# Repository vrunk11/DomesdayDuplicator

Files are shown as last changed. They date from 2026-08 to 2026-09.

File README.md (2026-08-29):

# Domesday Duplicator (DdD)

The Domesday Duplicator is a LaserDisc capture focused, USB 3.0 based DAQ capable of 40
million samples per second acquisition of analogue RF data at 10-bits resolution.

Please see the [Project Documentation](https://domesday86.github.io/DomesdayDuplicator/) for
details of the project and for access to the project documentation. For contributing
guidelines, see [CONTRIBUTING.md](CONTRIBUTING.md).

Domesday Duplicator Overview

## The capture application

Capture is via an easy to use GUI capture application, with real-time signal analysis —
waveform, spectrum analyser and spectrogram, amplitude history and live capture statistics —
so you can see the RF while it is being sampled rather than after the fact.

The capture application, showing the spectrogram view

The application also drives a Pioneer LaserDisc player over serial, runs whole-disc automatic
captures, and updates the Duplicator's own firmware and gateware over USB. The
[Capture Application documentation](https://domesday86.github.io/DomesdayDuplicator/capture-gui/)
covers every panel.

## Installing — no compilation required

**There is absolutely no need to compile anything.** All end-user installs must be performed
using the provided binary packages and firmware images. Building from source is a development
activity only, and nothing you need as a user requires it.

### The capture application

Download from the [releases page](https://github.com/Domesday86/DomesdayDuplicator/releases)
and follow the installation page for your platform:

| Platform | Package | Installation |
| --- | --- | --- |
| Linux | `DomesdayDuplicator-<version>.flatpak` | [Linux (Flatpak)](https://domesday86.github.io/DomesdayDuplicator/capture-gui/install-flatpak/) |
| macOS (Apple Silicon) | `DomesdayDuplicator-<version>-macos-arm64.dmg` | [macOS (DMG)](https://domesday86.github.io/DomesdayDuplicator/capture-gui/install-dmg/) |
| Windows 11 | `DomesdayDuplicator-<version>-windows-x64.msi` | [Windows (MSI)](https://domesday86.github.io/DomesdayDuplicator/capture-gui/install-msi/) |

Every release also carries `SHA256SUMS` and a `PROVENANCE.txt` recording the commit each
asset was built from. Verify your download against `SHA256SUMS`.

### Firmware and gateware

You do not build these either. Firmware releases publish a single signed update bundle,
`domesday-duplicator-update-<version>.dddfw`, and the capture application installs it for you:
**Tools → Firmware → Update firmware…**. The application verifies the bundle's signature and
every payload digest before it writes anything, and reports the version it reads back off the
live device afterwards. See
[Updating your Domesday Duplicator](https://domesday86.github.io/DomesdayDuplicator/capture-gui/updating-your-domesday-duplicator/).

A board that has never been programmed is handled the same way, with no jumper and no shell —
see [Bringing up a new or legacy board](https://domesday86.github.io/DomesdayDuplicator/capture-gui/bringing-up-a-board/).
Firmware releases also publish the raw images (`firmware.img`, the provisioning `.jic` and the
factory `.svf`) for bench recovery, but the bundle is the supported route.

Every released artefact is built by CI from the tagged commit; nothing is built on a
maintainer's machine or attached by hand
([release pipeline](https://domesday86.github.io/DomesdayDuplicator/development/release-pipeline/)).

## Cloning the repository

Everything is in this one repository. There are no git submodules, so a plain clone gives
you the complete project:

```
git clone https://github.com/Domesday86/DomesdayDuplicator.git
```

### Repository layout

| Directory | Contents |
| --- | --- |
| [hardware/](hardware/) | KiCad design for the custom DdD board, plus hardware documentation |
| [fpga/](fpga/) | Verilog gateware for the Terasic DE0-NANO (Cyclone IV) |
| [fx3/firmware/](fx3/firmware/) | Cypress FX3 USB 3.0 controller firmware |
| [fx3/programmer/](fx3/programmer/) | Host-side tool for programming the FX3 |
| [fx3/mkimage/](fx3/mkimage/) | `fx3-mkimage`, the project's own ELF-to-boot-image tool |
| [fx3/sdk/](fx3/sdk/) | Vendored Cypress FX3 SDK the firmware builds against |
| [ddd-gui/](ddd-gui/) | Qt 6 capture application, and the Flatpak/DMG/MSI packaging under `ddd-gui/packaging/` |
| [docs/](docs/) | Source of the project documentation website |
| [docs-vendor/](docs-vendor/) | Transcribed vendor service documentation for supported players |
| [nix/](nix/) | The single flake's shared helpers, default dev shell, NixOS module and whole-tree checks |
| [tools/](tools/) | Repository-wide scripts, run both by hand and by the checks |

## Developing the project

**Do NOT install from source unless you intend to develop the software** — see
[Installing](#installing--no-compilation-required) above for user installations.

### Nix on Linux is the only supported environment

**The only supported development and build environment is Nix on Linux.** There is exactly one
`flake.nix`, at the repository root, and exactly one `flake.lock`; every toolchain the project
needs is pinned by it, and CI builds through the same flake, so a build that fails under Nix
is a real failure rather than an environment quirk.

**Pull requests that introduce another development or build environment will not be accepted.**
That includes alternative build systems, per-distribution dependency lists, and packaging
intended to make a component build without Nix. If you develop on macOS or Windows, use a
Linux virtual machine — that is the supported route, and it is the only one.

### Building

Run any of these from anywhere in the working tree; Nix walks up to find the flake at the
root, so `.#ddd-gui` resolves identically from `ddd-gui/` and from the repository root.

| Component | Build | Development shell |
| --- | --- | --- |
| Capture application | `nix build .#ddd-gui` | `nix develop .#ddd-gui` |
| FX3 firmware | `nix build .#fx3-firmware` | `nix develop .#fx3` |
| FX3 programmer | `nix build .#fx3-programmer` | `nix develop .#fx3` |
| FX3 boot-image tool | `nix build .#fx3-mkimage` | `nix develop .#fx3` |
| FPGA gateware | `nix build .#bitstream` | `nix develop .#fpga` · `nix develop .#fpga-quartus` |
| Documentation site | `nix build .#docs-site` | `nix develop .#docs` |
| PCB | — | `nix develop .#hardware` |

```
nix develop                          # every component's tools in one shell
nix flake check                      # build everything and run the whole T1–T4 test suite
```

The capture application installs three binaries: `ddd-gui`, plus `ddd-update` and `ddd-jtag`,
which drive the same engine from a shell.

Components deliberately carry no flake of their own: an earlier layout gave each one a thin
flake for the `cd ddd-gui && nix develop` shorthand, and every one of those resolved
`nixos-unstable` into a lock file of its own — so entering the tree through a component quietly
got a different nixpkgs from the root pin. The reasoning is in the header comment of
[flake.nix](flake.nix).

Two caveats on the FPGA row. Quartus Prime Lite is unfree, `x86_64-linux` only and cannot be
served from a binary cache, so `nix build .#bitstream` means a multi-gigabyte first download
and is excluded from `nix flake check` — the per-commit tier must never require an unfree
download of anyone. It *is* built by CI, in a workflow of its own that runs on gateware
changes and from release tags, so every released bitstream is CI-built from the tagged commit.
`nix develop .#fpga` — without `-quartus` — gives the free tools instead: Verilog lint,
simulation and a language server, with no Quartus at all, and that covers most gateware work.

Build directories are `build/` under each component and are gitignored. Never build in-tree:
in the gateware's project directories in particular, Quartus rewrites the tracked `.qsf` on
every compile.

On NixOS, device permissions come from the flake's module — set
`hardware.domesdayDuplicator.enable = true;`, which covers the Duplicator, the FX3 and the
on-board USB-Blaster together. Elsewhere, see
[Linux device access](https://domesday86.github.io/DomesdayDuplicator/development/hardware-programming/linux-device-access/).

[AGENTS.md](AGENTS.md) records the project conventions and [TESTING.md](TESTING.md) the test
tiers, including the hardware-in-the-loop capture-integrity procedure that is the most
important test in the project.

## The Decode Family

The samples the DdD captures can be used with the whole family of decoders that make the FM RF
archival workflow ready to use today.

The original design was for the wide bandwidth of LaserDisc RF — making it suitable for all of
the more bandwidth restricted mediums too (that have a single stream of RF).

[Please see the documentation for more details](https://domesday86.github.io/DomesdayDuplicator/general/overview/)

## 3D Printed Case

The Domesday Duplicator also has [3D models](https://github.com/Domesday86/DomesdayDuplicator-Case)
and ready to use STL files for producing 3D printed cases, to protect from dust or line with
copper tape for affordable EMI shielding for example.



## Authors

Domesday Duplicator is designed and maintained by [Simon Inns](https://github.com/simoninns).

## Licences

- [Software Licence — GPLv3](LICENSE)
- [Hardware Licence — Creative Commons BY-SA 4.0](https://creativecommons.org/licenses/by-sa/4.0/)
  (full text in [hardware/pcb/LICENSE.txt](hardware/pcb/LICENSE.txt))

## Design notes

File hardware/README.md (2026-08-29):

# Domesday Duplicator Hardware

Design files for the custom Domesday Duplicator PCB — the analogue front end, ADC and
interconnect that sit between the RF source and the DE0-NANO/FX3 boards.

## Contents

| Path | Contents |
| --- | --- |
| [pcb/](pcb/) | KiCad project: schematics, PCB layout, symbol and footprint libraries |
| [pcb/fab/](pcb/fab/) | Fabrication outputs, one frozen directory per board revision |
| [pcb/tools/](pcb/tools/) | Plotting and Gerber comparison scripts |
| [doc/](doc/) | Hardware documentation, including the gain and filter calculations |

The project is on the current KiCad format (10). Board revisions are recorded in
[pcb/CHANGELOG.md](pcb/CHANGELOG.md), and [pcb/MIGRATION.md](pcb/MIGRATION.md) documents the
conversion from the original KiCad 4 files, how it was verified, and what is still
outstanding.

Schematic PDFs and the BOM are not kept in the repository. They are build output, plotted
per revision into `pcb/fab/rev<REV>/` by the script below, and can be regenerated from the
project at any time.

## Design

The Domesday Duplicator hardware is based on:

- Terasic DE0-NANO FPGA development board (see [fpga/](../fpga/))
- Cypress FX3 USB 3.0 controller (see [fx3/](../fx3/))
- High-speed ADC for RF signal capture
- Custom analogue front-end circuitry

## Manufacturing

Each fabricated board revision has its own directory under `pcb/fab/`, holding the Gerbers
and drill file exactly as sent out, the schematic PDF and BOM they were built from, a
`MANIFEST.md` recording provenance, and a `SHA256SUMS`. These are a historical record, not
build output: they are written once and never regenerated, because they are the reference
for what the working board actually is.

`pcb/fab/rev1.0/` is the proven production board, plotted with KiCad 4.0.7 in 2018. A
modern KiCad cannot reproduce it byte for byte — it encodes zone fills differently — which
is why it is preserved rather than rebuilt.

To plot a new revision:

```sh
nix develop .#hardware
hardware/pcb/tools/plot-fab.sh 2.0
```

The script refuses to write into a revision directory that already exists. To compare a
fresh plot against an existing one, plot with `--scratch` and use
`pcb/tools/gerber-compare.py`, which compares geometry rather than text and so ignores the
aperture renumbering and object reordering that make a plain diff useless.

## Licence

The hardware design is licensed under **Creative Commons Attribution-ShareAlike 4.0
International**. The full text is in [pcb/LICENSE.txt](pcb/LICENSE.txt).

This is different from the software in this repository, which is GPLv3 — see the root
[LICENSE](../LICENSE).

## Documentation

For detailed documentation, please see the
[main project documentation](https://domesday86.github.io/DomesdayDuplicator).

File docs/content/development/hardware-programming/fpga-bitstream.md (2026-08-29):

# FPGA bitstream

How to build the Domesday Duplicator's gateware and get it onto the DE0-NANO, with a check to
confirm each step actually worked.



The gateware runs on a **Terasic DE0-NANO** carrying an Intel (Altera) **Cyclone IV
EP4CE22F17C6**. It generates the ADC sampling clock, buffers samples across the clock-domain
boundary, and feeds them to the FX3 over the GPIF II bus.

The board has an **onboard USB-Blaster**, so no separate programming pod is needed — the
DE0-NANO's mini-USB connector is both its power supply and its programming interface.

The DE0-NANO's mini-USB connector, in an assembled unit

!!! warning "In an assembled Duplicator, it is not the only power supply"

    That description is of the board on its own. Bolted to a Duplicator PCB with the FX3 kit
    above it, the assembly is powered through **either** USB connector, and either one alone
    keeps the whole thing alive.

    Two consequences, and the second is a trap. The board is lit whatever the mini-USB is
    doing, so "the lights are on" says nothing at all about whether the USB-Blaster is
    connected — a charge-only cable looks identical to a working one. And **a power cycle
    means unplugging both cables**: pull only one and nothing reboots, while the board stays
    lit and looks perfectly normal.

!!! tip "The application can do this for you"

    Writing the EPCS no longer needs Quartus: `ddd-gui` plays a CI-built SVF through the same
    onboard USB-Blaster — **Tools ▸ Firmware ▸ Bring up a new or legacy board…**.
    See [Bringing up a new or legacy board](../../capture-gui/bringing-up-a-board.md), and
    [USB-Blaster and SVF programming](../usb-blaster-and-svf.md) for how it works.

    This page remains the reference for building the bitstream and for programming it by
    hand.

There are two ways to program it, and you will usually want both:

| | Writes to | Survives a power cycle | Use for |
| --- | --- | --- | --- |
| **FPGA configuration SRAM** (`.sof`) | Volatile memory in the FPGA | **No** | Testing a bitstream before committing to it |
| **EPCS64 serial configuration device** (`.jic`) | The DE0-NANO's onboard flash | **Yes** | Normal use |

Start with the `.sof`. It cannot leave the board in a bad state — a power cycle restores
whatever the flash holds — so it is the safe way to find out whether a bitstream works before
making it permanent. This mirrors the RAM-then-EEPROM order on the
[FX3 firmware](fx3-firmware.md) page, and for the same reason.

## Before you start

1. **Set up device access** — [Linux device access](linux-device-access.md). Without it,
   Quartus reports `Unable to lock chain - Insufficient port permissions` and cannot program
   anything.
2. **Get Quartus Prime Lite.** It is free and needs no licence file, but it is a
   multi-gigabyte download and is `x86_64` Linux or Windows only. The project builds against
   **version 25.1**.

!!! tip "You may not need to build anything"

    Prebuilt `.sof` and `.jic` files are attached to
    [releases](https://github.com/Domesday86/DomesdayDuplicator/releases), along with a
    `bitstream-provenance.txt` recording the commit and Quartus version they came from. If you
    only want to program a board, skip to [step 2](#2-program-the-board).

## 1. Build the bitstream

### With Nix

From anywhere in a checkout, on `x86_64-linux`:

```bash
nix build .#bitstream
ls result/
```

```
application/  factory/  provisioning/  reports/  bitstream-provenance.txt
```

The gateware is **two** images that live in one flash: the capture gateware in
`application/`, and a small resident boot loader in `factory/` that a unit falls back to if
a gateware update is ever interrupted. `provisioning/` holds the one `.jic` that carries
both, and that is the file a board is programmed with. The model is described on the
[EPCS layout and boot flow](../epcs-layout-and-boot-flow.md) page.

There is deliberately **no `.jic` of the capture gateware alone**: programming one would
write it over the factory image, leaving a unit with nothing to fall back to.

Quartus comes from the flake, so nothing needs installing first. **The first build is slow**:
Quartus is not redistributable, so it can never come from a binary cache and must be fetched
from Altera. The build is restricted to the Cyclone IV device family, which removes five of
the six component downloads.

### With Quartus installed by hand

Put Quartus' `bin` directory on `PATH`, then:

```bash
./fpga/build-local.sh
```

That copies the sources to `fpga/build/`, compiles both images, converts them into one
provisioning `.jic` — and into the `.svf` carrying the same content as JTAG vectors — and
writes the provenance record. Or drive the tools yourself — the GUI
is not required for any step:

```bash
cd factory      && quartus_sh --flow compile DomesdayDuplicatorFactory
cd application  && quartus_sh --flow compile DomesdayDuplicator
cd provisioning && quartus_cpf -c DomesdayDuplicatorProvisioning.cof   # both .sof -> one .jic
cd provisioning && quartus_cpf -c -q 4.5MHz -g 3.3 -n p \
    DomesdayDuplicatorProvisioning_write_jic.cdf \
    DomesdayDuplicatorProvisioning.svf                                # the same, as vectors
```

!!! warning "Do not compile in `fpga/application/` or `fpga/factory/`"

    `quartus_sh` **rewrites the `.qsf` project file in place** to record the Quartus version
    that last touched it, and scatters about thirty build products beside the sources. Both
    routes above copy the project to a build directory first. If you compile in the source
    directories you will find the repository has uncommitted changes you did not make.

### Check: what did you just build?

The build writes a `bitstream-provenance.txt` recording where the bitstream came from:

```
Source
------
  commit                    1b86b65a
  device                    EP4CE22F17C6
  family                    Cyclone IV E

Toolchain
---------
  quartus                   Version 25.1std.0 Build 1129 10/21/2025 SC Lite Edition
```

A `-dirty` suffix on the commit means the working tree had uncommitted changes, so the hash
alone does not describe what you built. Worth noticing before you program anything.

## 2. Program the board

Each `.cdf` file names its own inputs, so run it from the directory holding the bitstream it
names — under `result/` for a Nix build, `fpga/build/` for a local one.

### 2a. The `.sof` — the test path

```bash
cd application && quartus_pgm DomesdayDuplicator_write_sof.cdf
```

or, to look at the factory image on its own:

```bash
cd factory && quartus_pgm DomesdayDuplicatorFactory_write_sof.cdf
```

```
Info (213045): Using programming cable "USB-Blaster [7-3.2]"
Info (213011): Using programming file ./DomesdayDuplicator.sof with checksum 0x001D67A1 for device EP4CE22F17@1
Info (209016): Configuring device index 1
Info (209017): Device 1 contains JTAG ID code 0x020F30DD
Info (209007): Configuration succeeded -- 1 device(s) configured
Info (209011): Successfully performed operation(s)
```

`0x020F30DD` is the Cyclone IV EP4CE22's JTAG ID. If you see a different one, the `.cdf` is
talking to a different board.

**This is volatile.** Power cycle and it is gone, replaced by whatever is in the EPCS64
flash. That is the point: if the bitstream is broken, you have lost nothing.

### 2b. The provisioning `.jic` — the production path

Do this once you are satisfied the bitstream works.

```bash
cd provisioning && quartus_pgm DomesdayDuplicatorProvisioning_write_jic.cdf
```

!!! tip "Or without Quartus at all"

    `ddd-jtag DomesdayDuplicatorProvisioning.svf` writes the same content through the same
    on-board cable, driving it over libusb rather than through Quartus — see
    [USB-Blaster and SVF programming](../usb-blaster-and-svf.md). The `.svf` comes from the
    same build as the `.jic` and describes the same flash, so the two routes are
    interchangeable; everything on the rest of this page — the power cycle, the silicon
    identifier, what the board comes up as — applies to both. Quartus's own `jtagd` holds
    the cable open whenever it is running, so stop it first.

This writes the EPCS64 serial configuration device, which the FPGA loads from at every
power-up, with **both** images: the factory image at address 0 and the capture gateware at
`0x200000`. It takes appreciably longer than the `.sof` path, because it programs the flash
through the FPGA rather than configuring the FPGA directly.

The programmer prints the flash's silicon identifier as it works. It must read `0x16`, the
EPCS64's, which is the same value the firmware checks before it will write a byte.

**Then power cycle the board, and treat that as part of the procedure rather than as
housekeeping.** The programmer reaches the flash by loading a serial flash loader into the
FPGA, and it leaves that running — so until the board is power cycled the FPGA is running
Altera's loader and not this project's gateware at all. It answers nothing on the register
link, and an update attempted in that state is refused with *"the FPGA is not answering"*.

What it comes up as depends on what was in the flash before, because **the erase is
page-selective and the boot block sector is outside the pages this file writes**:

- a board being provisioned for the first time has no boot block, so it comes up running the
  **factory image** — the resident boot loader rather than the capture gateware. The capture
  application reports it as running recovery gateware. Writing the boot block is the last
  step of a gateware update rather than part of this file, so that is the expected state;
- a board being *re*-provisioned keeps its existing boot block, and if the application image
  just written still matches the CRC that block records, it boots straight into the capture
  gateware.

Both are correct. The [EPCS layout and boot flow](../epcs-layout-and-boot-flow.md) page
describes the states and what makes an application image count.

**This is the last time a cable is needed.** From here the capture gateware is updated over
the same USB cable the Duplicator already uses.

## Confirming what is running

### The LEDs

The gateware generates no pattern of its own. It lights **LED 0 alone** coming out of reset
and then leaves the row to the FX3, which drives it over the register link as a status
display. So the LEDs answer a different question than they used to, and a more useful one:

| What you see | What it means |
| --- | --- |
| Nothing lit | The FPGA is unconfigured — its pins are high-Z |
| One LED, steady | Gateware configured and running, and the FX3 has not spoken to it yet |
| A firmware pattern | The FX3 is talking to it. The patterns are listed on the [FPGA register interface](../fpga-register-interface.md#led-0x11) page |
| One LED, blinking every few seconds | **Not a pattern.** The FPGA is configuring repeatedly — see below |

The blinking case is worth knowing on sight, because it is what a broken handover looks like
and it is easy to read as a heartbeat. Each brief flash is a configuration completing, the
FX3 not getting far enough to write the register, and the board reverting; the lap time is a
few seconds. A unit doing this is not running the capture gateware at all, whatever the
cable says.

The old bouncing-LED check — one lit LED sweeping up the row and back — belonged to gateware
predating the register interface, where it doubled as a PLL-lock indicator. The equivalent
check now is the register bank answering at all: the identity block cannot be read unless the
design is clocked and the PLL is locked.

### The device on USB

The FPGA does not appear on USB itself. What it does is supply the FX3's interface clock, so
the check is that the FX3 still enumerates at full speed:

```bash
$ lsusb -v -d 1209:2347 | grep -E "bcdUSB|iProduct"
  bcdUSB               3.00
  iProduct                2 Domesday Duplicator (d0566b3e)
```

!!! warning "This does not prove the capture path works"

    The FX3 enumerates when *it* boots, which may have been before you reprogrammed the FPGA.
    A device still present at SuperSpeed afterwards is consistent with working gateware but is
    not evidence of it.

    The only test that exercises the path carrying samples is a capture. Dropped samples do
    not announce themselves — a capture with a fault completes normally and produces a file
    that looks fine and is wrong. See below.

### The capture-integrity test — the one that counts

After any gateware change, run a test capture:

1. Launch the capture application and **enable test mode**. This switches the FPGA from ADC
   data to an internally generated counter ramp.
2. Capture for **at least 60 seconds**, so the buffers wrap many times. A short capture can
   pass while a longer one drops samples.
3. Analyse the capture: **Edit → Analyse test data...**, or from a shell,
   `DomesdayDuplicator --analyse-test-data <file>`.

**Zero sequence breaks is a pass.** Any break at all means a sample was lost somewhere
between the FPGA and the disk, and is a blocker rather than a flake — the ramp is
deterministic, so there is no such thing as an intermittent false positive here.

## Reproducibility

Quartus fitting is deterministic: the same source, on the same Quartus version and the same
architecture, produces the same placement and routing. The project pins the two settings that
depends on — the Fitter seed and the parallel-processor count — in the `.qsf`.

What that means for the files:

| File | Across rebuilds |
| --- | --- |
| `DomesdayDuplicator.jic` | **Byte-identical** |
| `DomesdayDuplicator.sof` | Differs in about 34 bytes, all header metadata — a compile timestamp, a per-run design hash, and the checksum covering them |

So `bitstream-provenance.txt` publishes two digests per file: a **release** digest over the
file as shipped, for checking a download, and a **canonical** digest over the configuration
content, for checking a rebuild. For the `.jic` they are the same number.

To verify a released bitstream yourself, rebuild it with the same Quartus version and compare
the canonical digests:

```bash
nix build .#bitstream
./fpga/bitstream-provenance.py --build-dir result
```

## Troubleshooting

| Symptom | Cause and fix |
| --- | --- |
| `Unable to lock chain - Insufficient port permissions` | Device permissions. See [Linux device access](linux-device-access.md) |
| `No JTAG hardware available` | The USB-Blaster is not visible at all. Check the DE0-NANO's mini-USB cable is connected and is a data cable, not charge-only |
| `jtagconfig` reports `USB-Blaster variant` rather than `USB-Blaster` | Also permissions — Quartus cannot open the device far enough to identify the cable |
| `Can't find the programming file` | The `.cdf` names its inputs relative to the working directory. Run `quartus_pgm` from the directory holding the `.sof`/`.jic` |
| A different JTAG ID than `0x020F30DD` | Not a Cyclone IV EP4CE22 — check which board is plugged in |
| LEDs dark or frozen after programming | The PLL is not locking, or the FPGA is held in reset. Check the FX3 board's reset button, and that both boards are seated in their headers |
| Board captures nothing but garbage | The FX3 firmware and the gateware may be out of step. They share a protocol defined in both — update both across a release that changed it |
| Quartus rewrote files in `fpga/application/` or `fpga/factory/` | You compiled in a source directory. See the warning in step 1 |

### You cannot brick the DE0-NANO by programming it

The `.sof` path never touches non-volatile memory. The `.jic` path writes the EPCS64, but the
FPGA can always be reconfigured over JTAG regardless of what the flash contains — the
USB-Blaster talks to the FPGA directly. If a bad image reaches the flash, program a good
`.sof` over JTAG and rewrite the `.jic`.

## Related

- [FX3 firmware](fx3-firmware.md) — the other half, and it must be kept in step with this one
- [Linux device access](linux-device-access.md) — the USB-Blaster needs a udev rule, and it is
  in the same file as the FX3's
- [Software guide](../software-guide.md) — what each Verilog module does

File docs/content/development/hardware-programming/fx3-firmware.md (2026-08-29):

# FX3 firmware

How to build the Domesday Duplicator's USB 3.0 firmware and get it onto the device, with a
check to confirm each step actually worked.



The FX3 is a **Cypress EZ-USB FX3 SuperSpeed Explorer Kit (CYUSB3KIT-003)** that plugs into
the Domesday Duplicator PCB. Everything on this page happens over the FX3's own USB
connector.

There are two ways to program it, and you will usually want both:

| | Writes to | Survives a power cycle | Use for |
| --- | --- | --- | --- |
| **RAM** (`-u`) | Volatile memory | **No** | Testing a build before committing to it |
| **I2C EEPROM** (`-p`) | The kit's onboard EEPROM | **Yes** | Normal use |

Start with RAM. It cannot leave the device in a bad state — a power cycle undoes it
completely — so it is the safe way to find out whether an image works before making it
permanent.

!!! note "There is no SPI flash here"

    The SuperSpeed Explorer Kit boots from an I2C EEPROM. Older versions of
    `fx3-programmer`'s help text described `-p` as programming "SPI flash"; that was wrong,
    and there has never been an SPI code path. If you are reading documentation that mentions
    SPI flash for this board, it is out of date.

!!! tip "The application can do this for you"

    Everything on this page is now also available from `ddd-gui` — **Tools ▸ Firmware ▸
    Bring up a new or legacy board…** — which programs both the FX3 and the FPGA
    with no vendor toolchain installed at all. See [Bringing up a new or legacy
    board](../../capture-gui/bringing-up-a-board.md).

    This page remains the reference for what the wizard is doing, and the route to take
    when something needs doing by hand.

## Before you start

1. **Set up device access** — [Linux device access](linux-device-access.md). Without it
   every command below reports that no device was found.
2. Locate the **PMODE jumper, J4**, on the FX3 board. You will be moving it.

The two positions, which every step below refers to as *fitted* and *removed*:

<div class="grid" markdown>

Jumper J4 fitted — the USB-boot position

Jumper J4 removed — the EEPROM-boot position

</div>

## 1. Build the firmware

From anywhere in a checkout:

```bash
nix build .#fx3-firmware
ls result/
```

```
firmware.elf  firmware.img  firmware.map
```

`firmware.img` is the one you program. Nothing needs installing first — the ARM cross
compiler, the image builder and the SDK all come from the flake.

For an editing loop rather than a one-shot build, `nix develop .#fx3` gives the same
toolchain as a shell; the build options are in
[`fx3/firmware/README.md`](https://github.com/Domesday86/DomesdayDuplicator/blob/main/fx3/firmware/README.md).

### Check: does the build know what it is?

The firmware stamps the commit it was built from into its USB product descriptor, which is
how you will confirm later that the device is running *your* image and not the one that was
already on it. The configure step prints it:

```
-- Firmware version: d0566b3e
```

A value of `unknown` means the build could not determine a version — pass one explicitly with
`-DFIRMWARE_VERSION=<hash>`. A `-dirty` suffix means the working tree had uncommitted
changes, so the hash alone does not describe what you built. Both are worth noticing before
you program anything.

## 2. Put the FX3 into bootloader mode

Both programming modes need the FX3's **boot ROM** in control. Once the device is running
firmware, the boot ROM is not, and neither `-u` nor `-p` will work.

1. **Fit the PMODE jumper (J4).**
2. **Power cycle the board** — unplug the FX3's USB cable and plug it back in.

### Check: is it in bootloader mode?

```bash
$ lsusb -d 04b4:
Bus 007 Device 013: ID 04b4:00f3 Cypress Semiconductor Corp. FX3 micro-controller (DFU mode)
```

`04b4:00f3` and "DFU mode" is what you want. And through the tool:

```bash
$ fx3-programmer -l
Found 1 FX3 device(s):

[0] VID:PID=04b4:00f3 Bus=007 Device=013 Mode=Bootloader (FX3)
```

If it still shows `1209:2347` / `Mode=Application`, the jumper is not fitted or the board was
not actually power cycled. Note that a warm reboot of your PC may not cut USB bus power —
unplug the cable.

## 3a. Load into RAM — the test path

```bash
fx3-programmer -d 0 -u result/firmware.img
```

```
Uploading result/firmware.img (111348 bytes) to FX3 device 0...
Target device: VID:PID=04b4:00f3
........................................................
Program entry address: 0x400074e8

Successfully uploaded 111300 bytes to FX3 device 0
```

The bootloader transfers control to the image as soon as the download finishes — there is no
separate start step. The device disappears from the bus and comes back as the Domesday
Duplicator a second or so later.

**This is volatile.** Power cycle and it is gone. That is the point: if the image is broken,
you have lost nothing.

## 3b. Write the EEPROM — the production path

Do this once you are satisfied the image works.

```bash
fx3-programmer -d 0 -p result/firmware.img -v
```

```
Downloading flash programmer /…/share/domesday-duplicator/cyfxflashprog.img to device 0...
Successfully uploaded 106408 bytes to FX3 device 0
Found FX3 flash programmer (device 0)
Programming result/firmware.img (111348 bytes, padded to 111360) to FX3 I2C EEPROM...
..
Successfully programmed 111360 bytes to FX3 I2C EEPROM
Verifying result/firmware.img against FX3 I2C EEPROM (111348 bytes, padded to 111360)...
..
Verification successful: EEPROM matches result/firmware.img
Power cycle the device (remove J4/PMODE to boot from EEPROM)
```

Three things worth understanding in that output:

- **A Cypress secondary loader is downloaded first.** The FX3 boot ROM can only write RAM, so
  reaching the EEPROM needs a helper program running on the device. `fx3-programmer` ships it
  and finds it automatically.
- **The device re-enumerates as `04b4:4720` partway through.** That is the loader running.
  It is expected and goes away at the next power cycle.
- **`-v` is worth using.** It re-reads the EEPROM and compares it against the file. Each
  chunk is also verified as it is written, but `-v` checks the whole image afterwards.

Then:

1. **Remove the PMODE jumper (J4).**
2. **Power cycle the board.**

It should now boot the programmed firmware on its own, with no host involvement.

## Confirming what is running

This is the step people skip, and it is the only one that proves anything.

```bash
$ lsusb -d 1209:2347
Bus 008 Device 005: ID 1209:2347 Generic Domesday Duplicator (d0566b3e)
```

Then read the descriptors:

```bash
$ lsusb -v -d 1209:2347 | grep -iE "bcdUSB|iManufacturer|iProduct"
  bcdUSB               3.00
  iManufacturer           1 Domesday86
  iProduct                2 Domesday Duplicator (d0566b3e)
```

Three things to check, in order of importance:

| Field | Expect | If it is wrong |
| --- | --- | --- |
| `iProduct` | `Domesday Duplicator (<commit>)` | The hash in brackets is the commit the firmware was built from. **If it is not the one your build printed, the device is running something else** — most likely the previous EEPROM contents, meaning your programming did not take |
| `bcdUSB` | `3.00` | At `2.10` or lower the device fell back to USB 2.0. Try a different cable or port — this halves your capture bandwidth and causes dropped samples |
| `iManufacturer` | `Domesday86` | Anything else is not this firmware |

You can also confirm the negotiated link speed:

```bash
$ for d in /sys/bus/usb/devices/*/; do
    [ "$(cat $d/idVendor 2>/dev/null)" = "1209" ] && \
    echo "$(cat $d/speed) Mbps — $(cat $d/product)"
  done
5000 Mbps — Domesday Duplicator (d0566b3e)
```

**5000 Mbps** is SuperSpeed and is what you need. 480 Mbps means USB 2.0.

## Troubleshooting

| Symptom | Cause and fix |
| --- | --- |
| `No FX3 devices found`, but `lsusb` shows it | Device permissions. See [Linux device access](linux-device-access.md) |
| `Error: device 0 is not in bootloader mode` | The FX3 is running firmware. Fit J4 and power cycle |
| `Error: Device must be in bootloader mode to launch flash programmer` | Same — `-p` needs the boot ROM |
| `Error: cyfxflashprog.img not found` | The Cypress secondary loader is missing. It ships with the programmer; if you are running from a build tree rather than an install, set `FX3_FLASH_PROG` to its path |
| Device never reappears after `-u` | The image is not bootable. Power cycle with J4 fitted to get back to the bootloader — RAM loading cannot brick anything |
| `iProduct` still shows the old commit | The EEPROM write did not take, or J4 is still fitted so it booted over USB instead. Re-check step 3b and that J4 is **removed** |
| `iProduct` shows `unknown` | The firmware was built without version information. Rebuild passing `-DFIRMWARE_VERSION=` |
| Device enumerates at 480 Mbps | USB 2.0 fallback. Use a USB 3.0 port and a cable rated for it |
| The **host** takes ~20 seconds to wake from sleep, with a blank screen | Not a device fault. A board left in bootloader mode across a suspend — see [below](#leaving-the-board-in-bootloader-mode-can-stall-suspend-and-resume) |

### There is no software reset

`fx3-programmer` has no reset option, and one is not possible: the FX3 boot ROM offers no
reset command, and the Domesday Duplicator firmware implements only its own capture control
requests. **Changing boot mode always means a physical power cycle**, with J4 fitted or
removed to choose where the device boots from.

### Leaving the board in bootloader mode can stall suspend and resume

Finish a programming session by putting the board back to application firmware, or by
unplugging it. A board left sitting in bootloader mode is running the Cypress boot ROM, and
the boot ROM does not survive a host suspend reliably.

On Linux, waking from S3 with an `04b4:00f3` device still attached can stall the kernel's
device-resume phase for around twenty seconds:

```
usb 7-3.3: reset high-speed USB device number 23 using xhci_hcd
usb 7-3.3: device descriptor read/64, error -110
```

`-110` is `-ETIMEDOUT`: after resetting the port, the kernel asked the device for its
descriptors and got no answer. All of that happens before `Restarting tasks`, so userspace —
including whatever is drawing your screen — is still frozen for the whole stall. **The
machine looks dead**, with a blank display and no response to input, until the kernel gives
up on the device and lets userspace run again.

It is not deterministic. The same board in the same state has resumed cleanly from a short
suspend and stalled after a long one, so a session that ended fine yesterday is no guarantee.
A board running application firmware (`1209:2347`) is unaffected — it resumes in the same
fraction of a second as a machine with nothing on the port at all.

The cure is to not leave it there: remove J4 and power cycle when you have finished, or
unplug the cable. Nothing in this project can do it for you, because
[there is no software reset](#there-is-no-software-reset) — the boot ROM has no command that
would return the device to application firmware, and the host cannot power cycle it.

If you would rather the host coped, Linux can be told to power the port down at suspend
rather than trying to resume the device:

```
usbcore.quirks=04b4:00f3:m,04b4:4720:m
```

`m` is `USB_QUIRK_DISCONNECT_SUSPEND`, which makes `usb_suspend()` call `usb_port_disable()`
on the way into suspend. At resume there is nothing on the port to reset, so the timeout never
happens and the device re-enumerates normally afterwards. `4720` is the transient
flash-programmer identity, which is the same boot-ROM-era code and worth covering too. This is
a boot parameter, so it needs a reboot to take effect — and unrecognised flag letters are
*silently ignored*, so check the letter against
`Documentation/admin-guide/kernel-parameters.txt` for your own kernel rather than expecting a
typo to report itself.

### Recovering a device that will not boot

You cannot brick the FX3 by programming it, because the PMODE jumper bypasses the EEPROM
entirely. Fit J4, power cycle, and the boot ROM takes over regardless of what is in the
EEPROM. Then reprogram.

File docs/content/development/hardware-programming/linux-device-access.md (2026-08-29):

# Linux device access

On Linux a USB device node is created owned by `root`, readable by everyone and writable by
nobody else. `fx3-programmer` and the capture application both need **write** access, so
without a udev rule every operation fails — and it fails in a way that looks like the device
is missing rather than forbidden:

```
$ fx3-programmer -l
No FX3 devices found
```

even though `lsusb` clearly shows it. If you see that, this page is the fix.

## What the rules have to cover

A Domesday Duplicator presents **five different USB identities** depending on what it is
doing, and a rule matching only one of them will appear to work until the moment it does not:

| Identity | When | Needed by |
| --- | --- | --- |
| `04b4:00f3` | FX3 in bootloader mode, PMODE jumper fitted | `fx3-programmer` |
| `04b4:4720` | Transient, while the EEPROM is being written | `fx3-programmer` |
| `04b4:0007` | The SuperSpeed Explorer Kit's on-board USB-UART, whenever it is powered | A serial terminal, for firmware debug output |
| `1209:2347` | Running Domesday Duplicator firmware | The capture application |
| `09fb:6001` | The DE0-NANO's onboard USB-Blaster, whenever it is powered | Quartus (`quartus_pgm`, `jtagconfig`) |

All five are covered by **one file**, `70-domesday-duplicator.rules`. The first four are the
FX3 board: everything with the Cypress vendor ID `04b4`, plus `1209:2347`. The UART needs a
rule of its own — the vendor rule matches only the USB device node, and a serial port is
opened through the tty node created alongside it. The bridge is CDC-ACM, so that node is
`/dev/ttyACM<n>` rather than the `/dev/ttyUSB<n>` most USB serial adaptors get.

`1209:2347` is this project's own ID, [registered with pid.codes](https://pid.codes/1209/2347/).
Boards running firmware from before that registration enumerate as `1d50:603b` and are not
matched by the current rules; reprogram them rather than adding the old pair back.

The capture application recognises `1d50:603b` all the same, and deliberately never opens
one: enumeration works without any rule, so such a board is named on screen instead of being
reported as no device at all, and nothing is asked of firmware that could not answer.

The fifth is the FPGA's JTAG cable. The same file also covers the other USB-Blaster and
USB-Blaster II product IDs (`6002`, `6003`, `6010`, `6810`) for anyone using a standalone
cable.

!!! note "Quartus does not install the JTAG rule for you"

    Neither Altera's own installer nor the nixpkgs package ships any udev rules. Without one
    the JTAG device is root-only and every Quartus programming operation fails.

!!! important "The USB-Blaster rules are installed even if you never program an FPGA"

    JTAG is the **recovery** path — the thing you reach for when a firmware update has left
    a board unresponsive — so it has to work the first time it is tried, on a machine set up
    months earlier by someone who only wanted to capture. Splitting the cable's rules into a
    file that a capture-only install had no reason to fetch would put the permissions
    failure exactly where it is least welcome, so there is one file and it covers
    everything.

    `ddd-gui`'s [bring-up wizard](../../capture-gui/bringing-up-a-board.md) programs the FX3
    and the FPGA in one flow. Its connectivity page opens both devices before anything is
    programmed, so a missing rule turns up there — named, with the file to install — rather
    than in the middle of writing a flash.

## NixOS

The repository provides a NixOS module. Add the flake as an input and enable it:

```nix
{
  inputs.domesdayduplicator.url = "github:Domesday86/DomesdayDuplicator";

  # ... in your configuration:
  imports = [ domesdayduplicator.nixosModules.udev ];
  hardware.domesdayDuplicator.enable = true;
}
```

Then `sudo nixos-rebuild switch`. That one option covers all five identities — the FX3 and
the USB-Blaster together — and by default also installs `fx3-programmer` itself. One option
narrows it:

| Option | Effect |
| --- | --- |
| `hardware.domesdayDuplicator.installProgrammer = false` | Permissions only, no `fx3-programmer` in `systemPackages` |

There is no option to leave the USB-Blaster rules out. `hardware.domesdayDuplicator.usbBlaster`
used to be one; it is now ignored, and setting it to `false` produces a build warning telling
you to remove the line.

## Debian, Ubuntu, Fedora, Arch and others

Install the rules file from the repository:

```bash
sudo install -m 644 fx3/programmer/configs/70-domesday-duplicator.rules \
     /etc/udev/rules.d/70-domesday-duplicator.rules
sudo udevadm control --reload
sudo udevadm trigger --action=add --subsystem-match=usb
```

That is the whole thing — FX3, capture device, debug UART and USB-Blaster in one file. If you
built and installed `fx3-programmer` with `cmake --install`, it is already at
`<prefix>/lib/udev/rules.d/70-domesday-duplicator.rules` and can be symlinked instead of
copied.

!!! warning "Remove any older Altera rules file first"

    Many Altera installation guides tell you to create
    `/etc/udev/rules.d/40-altera-usbblaster.rules` by hand. If you have followed one,
    delete that file. It grants access through `MODE="0666"` alone, with no `uaccess` tag, so it
    hands write access to *every* user and process on the machine rather than to the user at
    the console — and having two files matching the same device makes it much harder to work
    out which one is responsible when something is wrong.

## The filename matters

!!! warning "Do not rename the rules file to something sorting after `73`"

    `udev` processes rule files in **lexical order**, and systemd consumes the `uaccess` tag
    in `73-seat-late.rules`:

    ```
    TAG=="uaccess", ENV{MAJOR}!="", RUN{builtin}+="uaccess"
    ```

    A rule that sets the tag in a file sorting *after* 73 sets it after anything looks for
    it. No ACL is applied and the tag is silently ignored — and because the rules also set
    `MODE="0666"`, which *is* applied regardless of ordering, the file still appears to do
    its job. That combination is why the mistake is so easy to miss.

    The `70-` prefix is load-bearing. Keep it.

## Confirming it worked

Plug the device in — or re-trigger udev as above — and look at the node.

Find it first:

```bash
$ lsusb | grep -iE "04b4|1209"
Bus 008 Device 005: ID 1209:2347 Generic Domesday Duplicator (d0566b3e)
```

`Generic` is not a mistake and not a fault: `1209` is the [pid.codes](https://pid.codes/)
vendor ID for open-source hardware, and that is the name `usb.ids` gives the whole shared
range. The part after it — `Domesday Duplicator (<commit>)` — is not from `usb.ids` at all.
No entry exists there for `2347`, so `lsusb` falls back to the `iProduct` string read from
the device itself, which is why the build's commit hash appears in a line that otherwise
looks like a static lookup. That string is what identifies the device — see
[FX3 firmware](fx3-firmware.md#confirming-what-is-running).

Then check the permissions on that bus and device number:

```bash
$ ls -la /dev/bus/usb/008/005
crw-rw-rw-+ 1 root root 189, 900 Aug 12 20:36 /dev/bus/usb/008/005
```

The trailing **`+`** is the important character. It means an ACL is present. Confirm it names
you:

```bash
$ getfacl -p /dev/bus/usb/008/005
user::rw-
user:sdi:rw-        <-- you, granted by uaccess
group::rw-
mask::rw-
other::rw-
```

Finally, the tool that matters:

```bash
$ fx3-programmer -l
Found 1 FX3 device(s):

[0] VID:PID=1209:2347 Bus=008 Device=005 Mode=Application (Domesday Duplicator)
```

### And for the USB-Blaster

Same idea, different tool. `jtagconfig` scans the JTAG chain, which needs write access:

```bash
$ jtagconfig
1) USB-Blaster [7-3.2]
  020F30DD   10CL025(Y|Z)/EP3C25/EP4CE22
```

The second line is the FPGA it found, read back over JTAG — so this confirms both the
permissions and the cable's connection to the board.

Without the rule, the same command reports:

```
1) USB-Blaster variant [7-3.2]
  Unable to lock chain - Insufficient port permissions
```

Note that it says **`USB-Blaster variant`** rather than `USB-Blaster`. Quartus cannot open the
device far enough to identify which cable it is, so it falls back to a generic name. That
wording is itself a permissions symptom, and it is easy to mistake for a hardware problem.

## If it still does not work

| Symptom | Cause |
| --- | --- |
| No `+` on the device node | The rule did not match, or was not reloaded. Re-run `udevadm control --reload` **and** `udevadm trigger`, or simply replug the device — rules are applied at enumeration, so a device plugged in before the rule was installed keeps its old permissions |
| `+` present but no `user:` line for you | `uaccess` grants to the user at the **active local seat**. Over SSH, or as a second logged-in user, you will not get it. Fall back on the `MODE="0666"` the same rules set, or run as root |
| Rule present, no ACL, no error | Check the filename sorts before `73-seat-late.rules` — see above |
| Works for `1209:2347` but not for programming | Your rule matches only the application identity. The bootloader is `04b4:*` |
| FX3 works but Quartus reports `Insufficient port permissions` | The rules file in `/etc/udev/rules.d/` does not carry the USB-Blaster lines. Check it contains `09fb`, and reinstall it from the repository if not |
| `No JTAG hardware available` | Not a permissions problem — the blaster is not enumerating at all. Check `lsusb` shows `09fb:6001`, and that the DE0-NANO's mini-USB cable carries data rather than power only |

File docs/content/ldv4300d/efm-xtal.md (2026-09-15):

# Removing the EFM crystal

# Overview
The reference LD-V4300D LaserDisc player produces an unwanted signal in the RF output around 8.5MHz which can interfere with PAL captures.

The unwanted signal is caused by the EFM decoder IC's clock on the AUDB board and injected via the CN12 board interconnect cable.

To remove this unwanted signal it's possible to simply remove the clock from the AUDB board.

!!! warning "Caution"
    Removing the clock will disable all EFM functionality - the player will no longer output digital sound via the backpanel connectors.

You will need a soldering iron, some de-soldering wick, flux and a correctly grounded anti-static band.

# Instructions

## Remove the bottom plate

Turn the player upside down on the bench and remove the 6 screws shown in the following photograph:

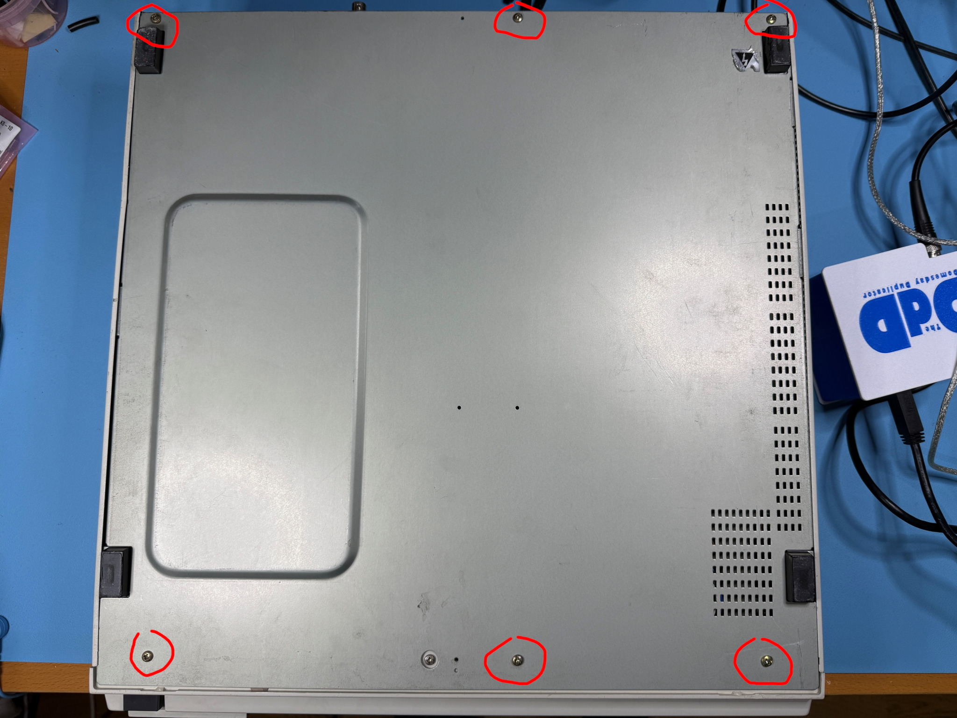
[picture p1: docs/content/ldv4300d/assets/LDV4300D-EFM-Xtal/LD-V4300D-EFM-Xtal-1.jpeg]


With the screws removed, the bottom panel should easily lift out to expose the circuit boards at the bottom of the player.

## Remove the connector screws

At the back of the player you will find 3 screws holding the audio out and EFM out connectors in place.

Remove all 3 screws - keep note of which screw goes where - the audio out screw is different from the EFM screws.

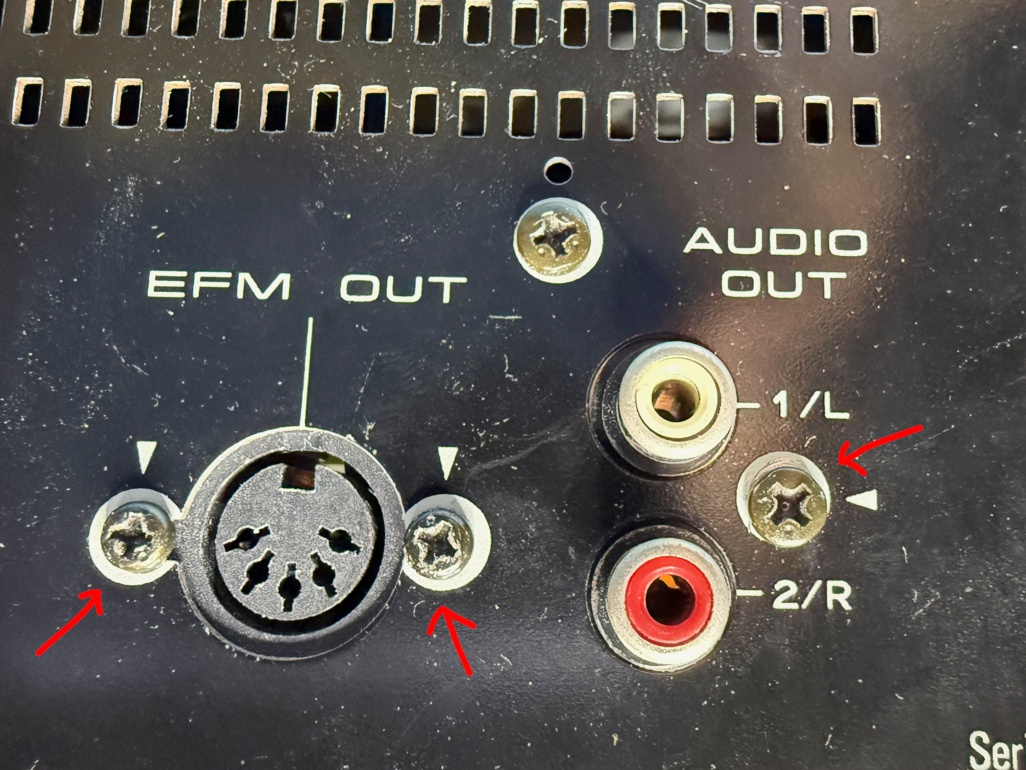
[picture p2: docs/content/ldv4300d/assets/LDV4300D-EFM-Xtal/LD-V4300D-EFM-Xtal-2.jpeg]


## Remove the AUDB PCB screws

There are 3 screws along the front of the AUDB PCB which also need to be removed.

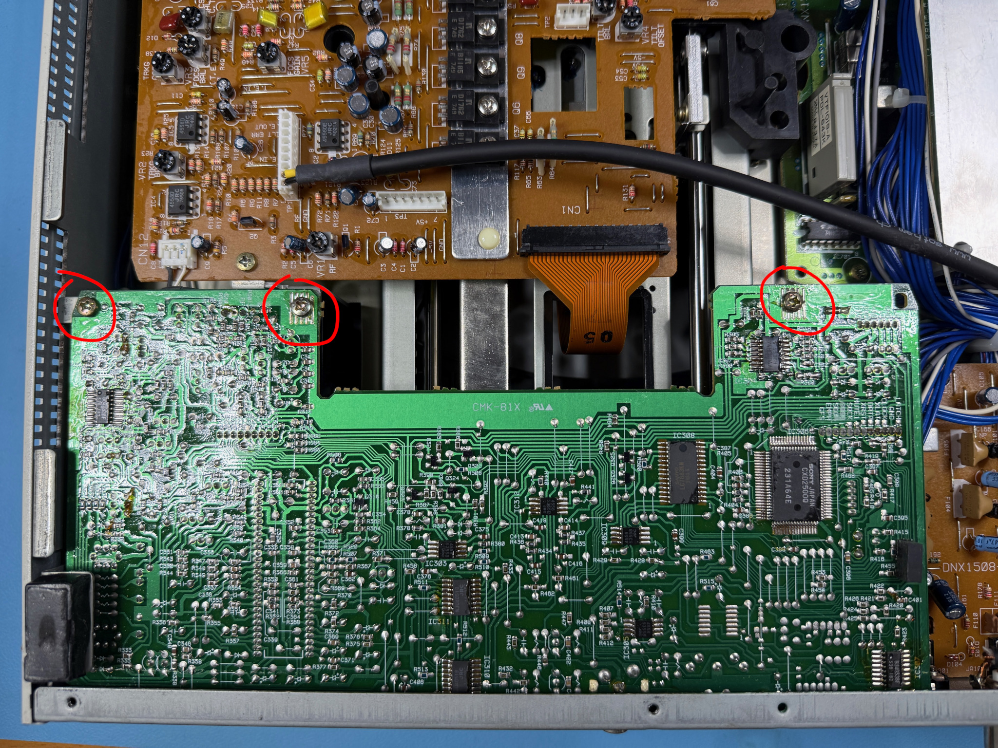
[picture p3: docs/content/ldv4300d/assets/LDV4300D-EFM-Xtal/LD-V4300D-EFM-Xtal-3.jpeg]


## Releasing the cables under the AUDB PCB

Now that all the screws are removed it's possible to lift the AUDB board slightly by the front edge.

!!! warning "Caution"
    Do not force the board up - there are cables under the board which restrict the movement.

You will need to get your hand under the board and release the cables from the cable holder shown in the following photo.

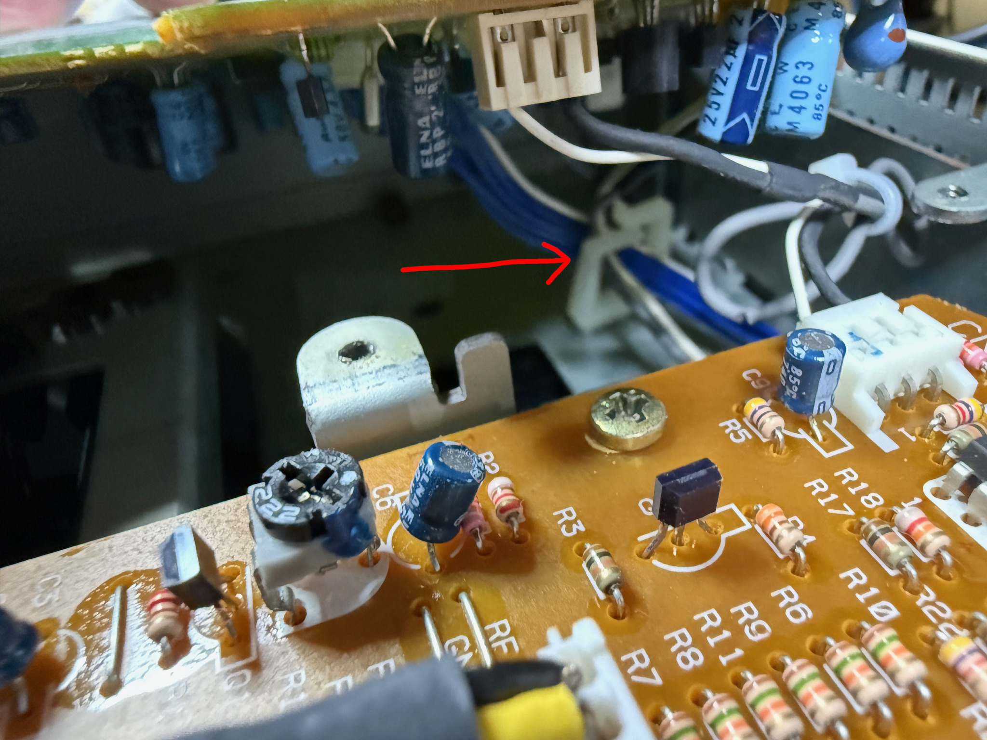
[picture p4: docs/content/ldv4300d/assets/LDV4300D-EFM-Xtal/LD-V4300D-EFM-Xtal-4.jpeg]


Once released the board should come up easily - note that the cables on the right-hand side of the board will stop you from completely lifting the board.  This is ok, you do not need to remove it completely.

The board should be as shown in the following photograph:

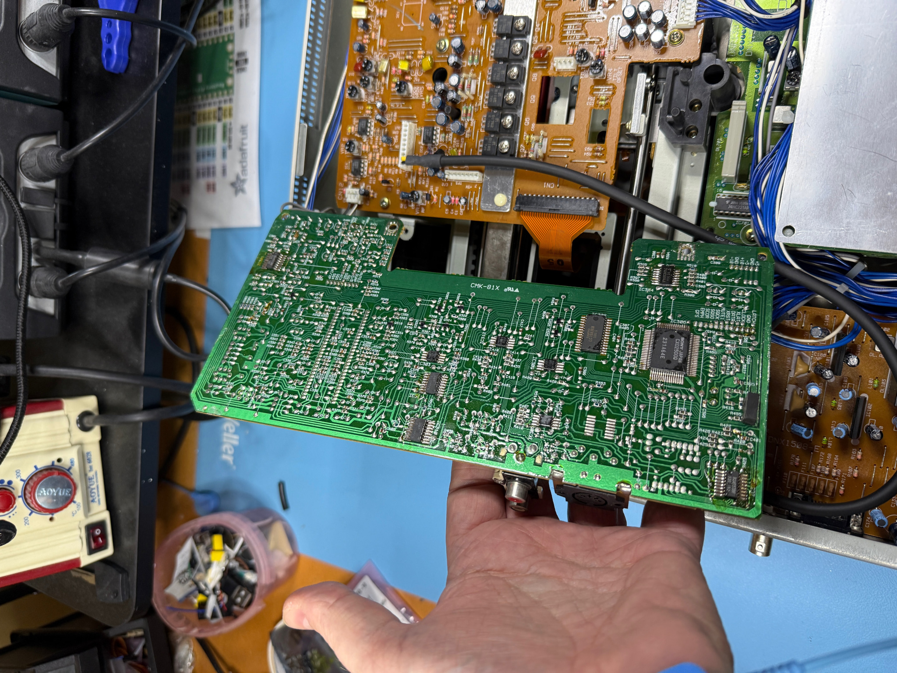
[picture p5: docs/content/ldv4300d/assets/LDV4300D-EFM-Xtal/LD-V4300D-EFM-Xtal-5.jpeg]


## Locating the crystal

The crystal is a standard quartz 'can' and has two terminals on the left of the AUBD PCB shown in the following photograph:

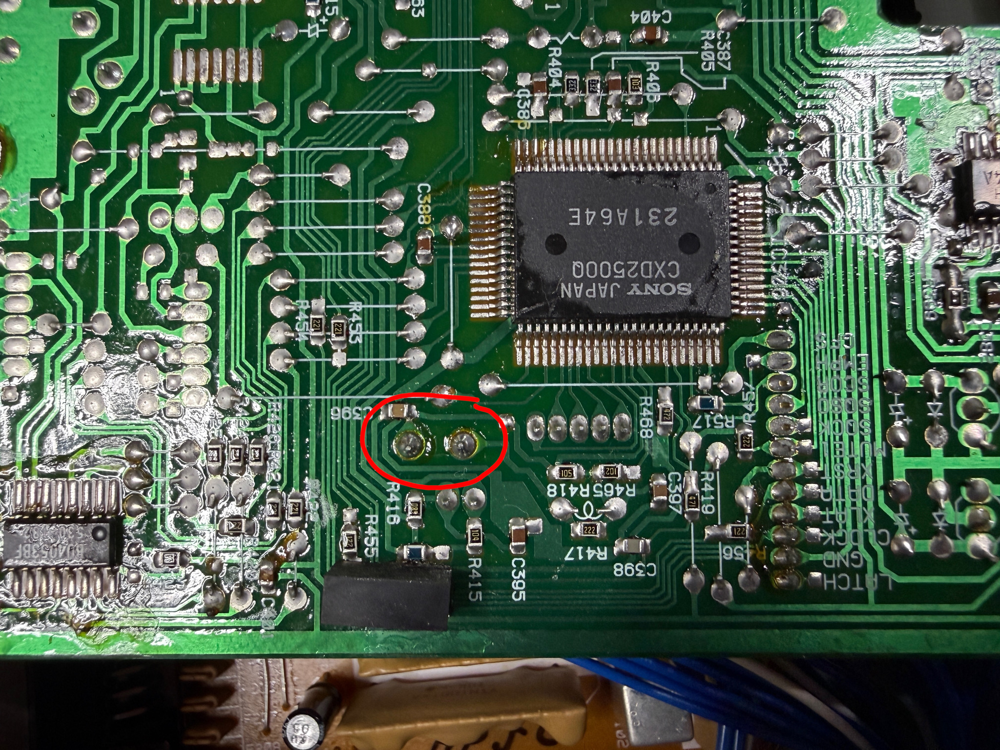
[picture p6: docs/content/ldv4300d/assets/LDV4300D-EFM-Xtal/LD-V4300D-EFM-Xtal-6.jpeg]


Using de-soldering wick (such as Chemtronics Soder-Wick size #3) and a good soldering iron - put some flux around the two terminals and remove the solder with the wick.  Make sure the solder is removed - the crystal should just fall out of the PCB (be careful not to drop it into the player).

Once removed it should look like the following photo (crystal shown here just for reference):

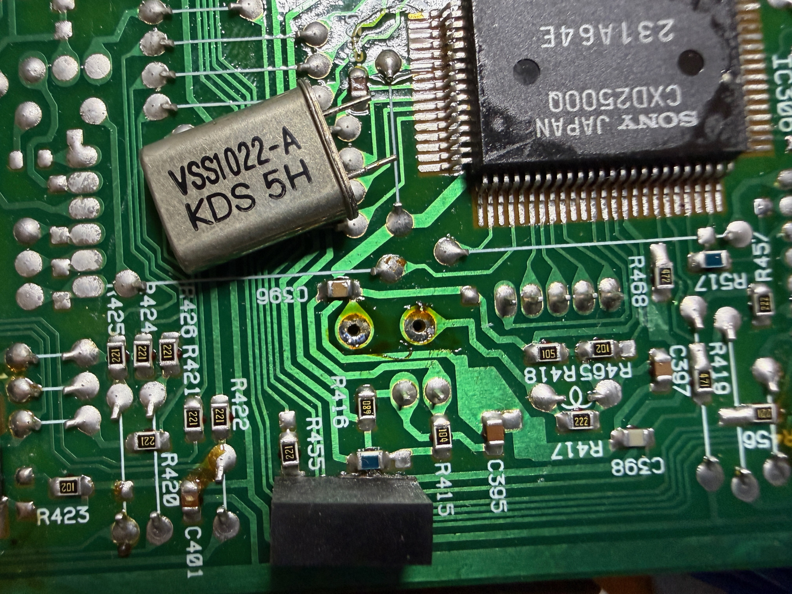
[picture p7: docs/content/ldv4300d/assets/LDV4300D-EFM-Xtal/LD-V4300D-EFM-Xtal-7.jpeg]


## Reassemble

To reassemble follow the assembly instructions in reverse. Make sure the cables are placed back in the cable holder and ensure that the PCB is slotted into the holder in the back panel correctly.  Double check that the PCB is flat and square before screwing it back in.

Keep the removed crystal in an anti-static bag - if you need to reverse the modification, you can simply solder the crystal back in place.

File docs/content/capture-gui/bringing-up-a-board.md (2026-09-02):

# Bringing up a new or legacy board

**Tools ▸ Firmware ▸ Bring up a new or legacy board…**

Programming a Domesday Duplicator from nothing to fully up to date: the FX3's firmware, and both images in the FPGA's configuration flash. When it finishes there is nothing else to do — the board captures.

**It does not matter what the board is running now.** A newly built unit whose FX3 has never been programmed and whose DE0-Nano still holds whatever Terasic shipped on it; a unit running the original Duplicator firmware from before this application existed; a unit that already works; a unit left half-programmed by a run of this that was stopped. This asks for the same things and does the same work in every case, and running it twice is harmless.

The reason is one physical fact: **fitting jumper J4 puts the FX3 into its boot ROM whatever it was doing**, and a JTAG configuration replaces whatever the FPGA is running whatever its flash holds. So nothing here has to diagnose your board, and nothing branches on what it finds — every board goes through the same eight pages, including one that is already sitting in its boot ROM.

If your board already answers this application and you only want the current release on it, **Tools ▸ Firmware ▸ Update firmware…** does that with no cables moved and no case opened. That is [updating](updating-your-domesday-duplicator.md), and it is what you want nearly every time.

## Before you start

**Take the unit out of its enclosure.** The FX3's jumper can be reached with the case on; the DE0-Nano's mini-USB connector cannot, and part of this happens through it.

**Stop any capture first.** The menu entry is greyed out while one is running, because everything behind it resets the device, rewrites its flash or reconfigures its FPGA, and a capture is a bulk transfer from that same device. Monitoring needs nothing from you — opening the wizard puts it down, and closing the wizard picks it up again.

You will need:

| | |
| --- | --- |
| The kit's **USB 3.0 cable** | The one you normally capture through |
| The DE0-Nano's **mini-USB cable** | A cable that carries **data**. A charge-only cable is the commonest thing that goes wrong here, and the board lights up either way |
| A **jumper** (shunt) | Always, whatever the board is running. A newly built kit already reports the boot ROM the wizard needs, but it does so because its EEPROM is empty — take the jumper away and it leaves again at the first restart |
| An **update file** | Usually nothing to do: an installed copy of this application already carries one. See *The update file* below |

Both cables stay connected for the whole procedure, and the mini-USB comes off at the very end, when the case goes back on. Allow about five minutes, most of it watching the three images being written and checked.

## The one thing that catches people

**A power cycle means unplugging *both* cables.**

The assembled unit is powered through the FX3 kit's USB 3.0 connector *and* through the DE0-Nano's mini-USB. Either one alone keeps the whole assembly alive. So pulling just the USB 3.0 cable leaves the unit powered, the FX3 never re-reads where it boots from, the FPGA never reloads from flash — and the board stays lit and looks completely normal while nothing at all has happened.

Every page that asks for a power cycle says *both*, in those words. If a page waits and waits for the board to come back, that is the first thing to check.

## The update file

**The same file the update window installs.** One signed `.dddfw` per release, and it carries four payloads:

| Payload | What it is |
| --- | --- |
| `firmware.img` | The FX3's firmware |
| `gateware-app.rpd` | The application gateware — what the board captures with |
| `gateware-provisioning.svf` | The gateware as **JTAG vectors** |
| `gateware-factory.rpd` | The **factory image**, as raw flash bytes |

An ordinary update writes the first two and ignores the rest. A bring-up needs all four, and the reason is the ordering problem this whole flow exists to solve: an ordinary gateware update goes *through* the gateware's own flash bridge, which a board being brought up does not yet have. So the vectors put a gateware into the FPGA over a second cable first, and everything else is then written through the bridge that gateware provides.

**An installed copy of this application already carries a file**, and the wizard chooses it for you. That is deliberate and it is the point: a board being brought up cannot be updated over USB, so the computer beside it is quite likely one that has just been built and has nothing downloaded yet. Nothing about this procedure needs a network.

Two reasons to choose a file instead, and the page has a button for it:

- **your copy carries none.** A build from source does, unless it was told otherwise. The page says so and names the file to fetch;
- **you have a newer release** than the one your application shipped with.

Either way it is verified identically: the signature first, then every payload's digest, before anything is programmed. Arriving with the application is not a reason to trust a file, and a bundled one that does not verify is refused exactly as a downloaded one would be. A development-signed file says so on the page, every time, because that signature proves the file is well formed and nothing whatever about where it came from.

A release bundle from before the bring-up payloads existed is refused here, and the page names exactly which of the four it is missing. Such a file updates a working device perfectly well; it just cannot bring a board up.

## How each page tells you where it has got to

Every page that has anything to wait for ends in one line, and it is one of two:

| Line | Means |
| --- | --- |
| **• Waiting for** *…something…* | Nothing is happening yet, and this is what it is waiting for — you to press a button, or a board to come back |
| **✓ All done.** *…what happened…* **Click “Next ›” to continue.** | That step is finished |

A step that is finished also takes its own button away: **Load the gateware** becomes a greyed-out **Gateware loaded**, and **Program the board** becomes **Board programmed**. So there is never a question of whether pressing it again is needed, or whether it worked the first time.

## What the wizard does, page by page

### 1 · What this does, and what it will ask of you

A checklist rather than an explanation: what to have ready before starting, and what you will be asked to do. Everything physical is listed here so that the case comes off once, both cables go on once, and no physical step is ever asked for twice.

It also states where you end up: **a working Duplicator running the release you chose, ready to capture.** Nothing follows it.

### 2 · Both boards, and jumper J4

Three numbered instructions and two live status rows.

The instructions: **fit jumper J4** across the FX3 board's two-pin `PMODE` header — a photograph at the foot of the page shows exactly which — then **unplug both cables**, then **plug both back in**. The jumper only takes effect on a boot, and the unit does not boot while either cable still feeds it, which is why all three steps are needed and why doing only the first looks exactly like success.

**Fit it whatever the board is running**, including one the page reports as already waiting in its boot ROM. That is the state a newly built kit arrives in, and it arrives there because its EEPROM is empty rather than because anything is holding it there. Without the jumper it leaves the boot ROM again at the first restart — part way through step 5, which is where the bring-up fails with nothing obvious to point at. Nothing in software can see a jumper, so the wizard cannot tell the two cases apart and does not try to.

The two rows, one per board, are what the page waits for. Each device is **opened**, not merely noticed, so that a permissions problem turns up here — while nothing is half-programmed — rather than in the middle of writing a flash. The FX3 row ticks when the board has been seen to **go away and come back in its boot ROM**: going away is the half the application can actually see, and it is what proves both cables came out.

This is the page that makes your board's previous state irrelevant. Whatever it was running, the jumper reaches the same boot ROM, and everything after this works from there.

Each row carries a mark, and the middle one is the one people misread:

| Mark | Means |
| --- | --- |
| Green tick | That board is ready |
| **Amber dot** | That board is there, and the three steps above have still to be done to it. **Not** that anything is wrong with it |
| Red cross | Something to put right before going on |

What the FX3 row can say:

| Row says | Meaning | Mark |
| --- | --- | --- |
| *In its boot ROM after restarting* | The jumper is fitted and both cables came out. This is what the page is waiting for | Green |
| *Waiting in its boot ROM* | A newly built kit, whose EEPROM is empty. **The jumper is still needed**: an empty board comes up in its boot ROM whether or not one is fitted, and the row ticks only once the board has been seen to go away and come back | Amber |
| *Running this application's own firmware (commit)* | A board that already works. **You probably want [Update firmware](updating-your-domesday-duplicator.md) instead.** Carrying on is safe and reprograms everything | Amber |
| *Running the **original** Duplicator firmware … 1d50:603b* | The firmware from before this application existed | Amber |
| *The kit's debug serial port is answering* | The board has power and its USB 3.0 link is not answering. Check that cable and that it is in a USB 3.0 socket | Red |
| *Nothing found* | No cable, no power, no permissions — **or, on Windows, a board that is plainly attached and running firmware.** See below | Red |

And the FPGA row:

| Row says | Meaning | Mark |
| --- | --- | --- |
| *Found and opened* | The USB-Blaster is reachable | Green |
| *Nothing found* | Nearly always a charge-only cable. On Linux, check `70-domesday-duplicator.rules` is installed — see [Linux device access](../development/hardware-programming/linux-device-access.md) | Red |
| *attached but could not be opened* | Something else has it. Quartus's own `jtagd` holds the cable open whenever it is running; on Windows it is the driver binding | Red |

**Bring-up needs the device rules installed on Linux.** One file, `70-domesday-duplicator.rules`, covers both the Duplicator and the USB-Blaster.

**On Windows it needs WinUSB bound to up to three USB identifiers**, and the first two are not the one a working Duplicator uses: `04B4:00F3` for the FX3 in its boot ROM, and `09FB:6001` for the DE0-Nano's on-board USB-Blaster. Windows binds drivers by USB identifier, so a board in either of those states is a *different device* as far as Windows is concerned. An unbound FX3 is invisible to this application rather than merely unopenable, so its row reads as nothing found; the USB-Blaster is seen on the bus whatever driver holds it, so an unbound cable reads as *attached but could not be opened* and names the binding. Do both before starting: [Windows — MSI](install-msi.md#if-the-board-does-not-show-up-as-a-domesday-duplicator) walks through it. macOS needs nothing.

**A board running the original firmware reads as *nothing found* on Windows, and that is the state this page is built around.** `1D50:603B` is an identifier nobody has any reason to bind, so such a board is absent as far as this application is concerned even though it is plainly attached and lit. The remedy is the one the page asks for anyway: fit jumper J4, pull both cables, plug them back in, and the board returns as `04B4:00F3` — the identifier to bind, and the only one this flow needs from the FX3.

The third is `1209:2347`, the Duplicator the board becomes, and it is needed *part way through* — step 5 restarts the board into its new firmware and then reopens it under that identifier. On any machine that has ever had a working Duplicator plugged in it is already bound and there is nothing to do. On one that has not, the board presents nothing for Zadig to pick until step 5 has already run, so this binding is made a different way: **Zadig's Device → Create New Device** installs a driver for an identifier nothing is presenting, and Windows matches it when the board appears. Do it in the same session as the other two, before starting — [Binding an identifier the board is not presenting yet](install-msi.md#binding-an-identifier-the-board-is-not-presenting-yet) has the fields to enter — and the wizard runs straight through.

Reaching step 5 without it costs nothing but the run. The step stops after thirty seconds, having written nothing permanently, and it names what happened rather than reporting an absence — the board *is attached as a Duplicator (1209:2347) and cannot be opened under that identifier* — because the board is on the bus at that point doing exactly what it was told to, and the only thing missing is the driver binding. Leave the board plugged in, bind `1209:2347` the ordinary way now that it is visible, and run the wizard again. The application does not need restarting; it re-reads the device list five times a second.

### 3 · The update file

The file your copy of the application carries, already chosen, with its version and what it carries written out. Signature and digests are checked here, on that one exactly as on any file you choose instead.

If your copy carries none, this is the one page that needs something from elsewhere: the file to download and where from.

### 4 · Load the gateware into the FPGA

Press **Load the gateware**. It plays the gateware into the FPGA through the DE0-Nano's own USB-Blaster — the only route to a board whose flash holds nothing this application can talk to. About three seconds.

**Nothing is written to the board by this step.** A JTAG configuration lives in the FPGA's own memory and would be lost the moment the power went off. What it buys is the next page: a Duplicator that can reach its own flash, so that everything after this is written by the device itself over the USB 3.0 cable.

Because nothing is written, an attempt that does not take can simply be made again — and the page does that for you, once, before reporting anything. Nearly six million bits go down a bit-banged cable, the check at the end of the file exists to catch a configuration that did not arrive intact, and the answer to one that it catches is another three seconds rather than a message. If you see the bar go back to the beginning, that is what happened, and the page says so while it runs. A second failure is reported, with the line of the file it stopped at.

The FX3 is sitting in its boot ROM while this happens, with every shared pin idle. That is why this comes before the firmware rather than after it — see *Why this order* below.

### 5 · Program the board

Press **Program the board**. Everything permanent happens in this one step: the FX3's boot ROM is handed the firmware and runs it from memory, and that firmware then writes three things — the same protocol, the same digests and the same readback an ordinary update uses:

1. its own **EEPROM**, so the board has firmware of its own;
2. the FPGA's **factory image**, which is what the board falls back to and what makes future updates possible;
3. the FPGA's **application image**, which is what it captures with.

**That order is deliberate.** Stopped or interrupted at any point, the board comes back in a state this application can reach and repair: after the first write it boots the new firmware, and after the second it always has a valid image to fall back to before the region it falls back *from* is touched. Written the other way round, an interrupted run could leave a bare board with an application image and nothing to load it with.

Nothing is restarted at the end. The jumper is still fitted, and a restart would land the FX3 back in its boot ROM — so all three become the running images together, at the power cycle two pages on.

The flash writes pause every few seconds while a block is erased; that is the flash doing its job, not something stuck. **Stop** is safe at any point.

### 6 · Remove jumper J4

Same board, same photograph, header bare. **Do not unplug anything yet.**

Nothing here can detect a jumper, and the page says so rather than pretending to wait for something: click **Next ›** once it is off.

### 7 · Power cycle

Three numbered instructions again: unplug both, wait a couple of seconds, plug both back in. That is what makes the three images you have just written the running ones — the FX3 re-reads where it boots from, and the FPGA loads the factory image, which hands over to the application image beside it.

**This page cannot go by whether a Duplicator is attached**, and that is worth knowing because one is. The previous step handed the firmware to the FX3's boot ROM and ran it out of memory, so the board is enumerating as a working Duplicator before you touch anything. What the page waits for instead is two things it can observe:

- the device **going away**, which is what proves a cable came out;
- it coming back **on the application image**, which is what proves the board lost power. The gateware loaded over JTAG in step 4 is the *factory* image, and only a power cycle makes the FPGA reload from flash.

That second check catches the failure this page has always warned about. Pulling the USB 3.0 cable alone makes the device vanish and return while the mini-USB keeps the board alive — the firmware in memory survives, the gateware in the FPGA survives, and every outward sign is of a power cycle that worked. The page says so:

| What the page says | What happened |
| --- | --- |
| *Waiting for both cables to come out* | Nothing yet — the board is still on the bus |
| *Waiting for the Duplicator to come back* | The cables are out |
| **The board did not lose power** | Only one cable came out. Unplug **both** |
| **The board has come back in its boot ROM** | Jumper J4 is still fitted. Go back a page and take it off |
| **✓ All done** | It restarted and is running from its own flash |

**Both go back in, even though the USB 3.0 cable alone would boot the board.** It would: with both cables out the unit is dead, so the USB 3.0 cable on its own is a real cold start, and nothing on this page or the next one is read over the mini-USB. It goes back in so that the instruction is the same one every time — the half people get wrong is the *unplug* half — and so that the USB-Blaster is still there if this page sends you back a step. The mini-USB comes off at the end of step 8, when the case goes back on.

### 8 · What the device is running now

Four things, read off the device rather than assumed:

- the Duplicator's own firmware is running;
- it speaks a protocol this build knows;
- its firmware is the build the update file carries;
- its FPGA is answering, **on the application gateware**.

That last one is what separates a finished board from one that is most of the way there. A board that comes back on its factory image works and is not damaged, but it cannot capture — and the page says so rather than reporting success.

Then: **unplug the DE0-Nano's mini-USB cable, put the case back on and click Close.** The mini-USB was only ever the way in to a board that could not yet be reached over USB 3.0, and nothing from step 5 onwards uses it; the kit's USB 3.0 cable stays where it is, because that is the one you capture through. From now on this board updates itself.

## Why this order

The FX3 and the FPGA share one interconnect, and one line changed direction between the original design and the current one. Under the original firmware `CTL_07` is driven by the FX3; under the current gateware the same wire is driven by the FPGA. Those two must never run together.

What keeps a board out of that pairing is not care — it is where the FX3 is while the FPGA changes. In its boot ROM every shared pin is idle, so the gateware can change underneath it with nothing to contend with, and by the time any firmware runs again it is the firmware out of the file you chose. That is why the page that asks for the jumper comes before the gateware is loaded, and why the wizard refuses to write anything until it has been.

## If something goes wrong

**Nothing here can be broken by stopping part way**, and that is worth stating plainly:

- the FX3 cannot be bricked. Fitting jumper J4 always reaches its boot ROM, whatever is or is not in its EEPROM;
- the DE0-Nano cannot be bricked. JTAG always reaches the configuration flash, whatever is in it;
- every step can simply be run again, from the beginning, as many times as you like. A stopped run leaves a board this same wizard accepts on its next run, because that run assumes nothing.

The commonest failures, in order:

| What you see | What it usually is |
| --- | --- |
| A page waiting for a board that never comes back | Only one cable came out. Unplug **both**, count to three, reconnect |
| *The board did not lose power* on page 7 | The same thing, caught rather than guessed at — the USB 3.0 cable alone came out while the mini-USB kept the board alive |
| *Nothing found* on the FPGA row | A charge-only mini-USB cable |
| The cable is attached and will not open | Quartus's `jtagd` is running, or the udev rules are not installed |
| A page waiting for the boot ROM after fitting the jumper | The jumper is on the wrong header, or the power cycle did not happen |
| *Nothing found* on the FX3 row, on Windows, with the board plainly attached | The board is running firmware under an identifier nothing is bound to. Fit jumper J4 and pull both cables: it comes back as `04B4:00F3`, which is the identifier to bind |
| The file is refused on page 3 | It is a release from before the bring-up payloads existed. The page names what is missing |
| *The device restarted … and is attached as a Duplicator (1209:2347), but this application cannot open it*, on page 5, on Windows | WinUSB has never been bound to `1209:2347` on this machine. Nothing was written; bind it with Zadig and run the wizard again. Creating that binding before starting avoids the run entirely — see [Both boards, and jumper J4](#2-both-boards-and-jumper-j4) above |
| *The device did not come back after being given its firmware*, on page 5 | The board did not re-enumerate at all, which is a different failure from the one above and is not a driver binding: nothing with those identifiers is on the bus. Nothing was written — unplug both cables, plug them back in, and run the wizard again |

## What this replaces

Before this existed, both halves were programmed with vendor tools: `fx3-programmer` for the firmware and Quartus for the FPGA — several gigabytes of unfree, x86_64-Linux-only software whose entire role was to write a file this project already publishes. Those procedures still work and are still documented under [hardware programming](../development/hardware-programming/index.md); the wizard is the same operations without the toolchain.

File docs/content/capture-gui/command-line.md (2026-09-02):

# Command line

The application is called `ddd-gui`. It is a graphical application and needs no arguments,
but it accepts a few.

```bash
ddd-gui [options]
```

| Where the binary is | |
| --- | --- |
| Linux (Flatpak) | `flatpak run --command=ddd-gui io.github.simoninns.DddGui` |
| macOS | `/Applications/Domesday Duplicator.app/Contents/MacOS/ddd-gui` |
| Windows | `C:\Program Files\Domesday Duplicator\ddd-gui.exe` |

## Options

### `--version`

Prints the commit the binary was built from. This is the string to quote in a bug report.

!!! note "Windows, and where the output goes"

    The Windows build is linked as a GUI-subsystem executable and has no console of its own,
    so at startup it borrows the console it was started from. Output then appears in the
    command prompt as it does everywhere else — but the prompt does not wait for a windowed
    application, so it returns immediately and the output lands underneath it. Started from a
    desktop shortcut there is no console to borrow and nothing is printed at all, which is
    why **Help ▸ About** carries the identical string.

### `--help`

The usual summary of these options.

### `-d`, `--debug`

Log debug-level diagnostics, and show the [Log panel](main-window.md#the-log-panel) at
startup rather than leaving it hidden.

This is what to do before reproducing a fault you intend to report: start with `--debug`,
make the fault happen, then copy the Log panel's contents into the report. Better still,
add [`--log-file`](#-f-log-file-file) and attach the file.

`--debug` is the short way to say `--log-level debug` *and* open the panel. Given both, the
explicit `--log-level` decides the level and `--debug` still opens the panel — so
`--debug --log-level info` is "show me the panel, at the usual level".

### `-l`, `--log-level <level>`

How much is logged, to the [Log panel](main-window.md#the-log-panel) and to the console
alike. One of:

| Level | What it admits |
| --- | --- |
| `trace`, `debug` | Everything, including per-step diagnostics |
| `info` | The default: what the application did |
| `warn`, `warning` | Only what went wrong or nearly did |
| `error`, `critical` | Only failures |
| `off` | Nothing at all |

At `debug`, a capture keeps a full account of itself — see
[What debug level records about a capture](#what-debug-level-records-about-a-capture)
below. That is the level to reproduce a fault at.

The application has four levels of its own, and this vocabulary is the wider one the
project's other tools use, so a level named there means the same thing here: `trace` is a
second name for `debug` and `critical` a second name for `error`. The names are lower case
and an unknown one is an error rather than a silent fall back to `info`.

```bash
ddd-gui --log-level debug
```

### `-f`, `--log-file <file>`

Write the log to a file as well as showing it in the Log panel. The file is **replaced at
every start**, so it describes the run that produced it — reproduce a fault twice and you
have the second attempt, not both.

```bash
ddd-gui --log-level debug --log-file capture.log
```

This is the log to attach to a bug report. The Log panel holds the last few thousand records
and closes with the application; a file survives both. The console stays quiet unless
[`--log-out`](#-log-out-destination) asks for it.

### `--log-out <destination>`

Where the log goes **besides** the Log panel:

| Destination | Where records go |
| --- | --- |
| `none` | The default: the Log panel and nowhere else |
| `console` | The console as well. A `--log-file` is ignored |
| `file` | A log file as well, and nothing to the console |
| `both` | The console and a log file |

The Log panel is not one of these values and cannot be turned off by one. It shows every
record the level admits whatever this says — it is the destination a user who is not looking
at a terminal has, and `none` means *no second copy*, not "no log".

Naming a [`--log-file`](#-f-log-file-file) with no `--log-out` is an explicit request for a
file, so it means `file`. Spelling out `--log-out` always wins over that, including
`--log-out none` beside a `--log-file` — which writes no file, and says so in the panel
rather than leaving a switch that quietly did nothing.

`file` and `both` need `--log-file` to have named one. Asking for either without a file logs
to the panel and the console and says so.

!!! tip "Where the console is"

    Log records go to standard error, so that a script reading `--analyse-test-data`'s
    verdict from standard output does not have to filter them out. On Windows the console is
    the one the application was started from, as described under `--version` above.

### Capture options

Eight options start, stop and set up a capture, so that a script can do what the window
does. They are listed here for completeness and covered properly — with the exit codes, the
worked examples and what each platform needs — in
**[Scripting captures](scripting.md)**.

| Option | What it does |
| --- | --- |
| `--start-capture` | Start capturing as soon as a device is found. The window still opens unless `--headless` is given |
| `--headless` | Run with no window. Needs `--start-capture` |
| `--stop-capture` | Stop the capture a running instance is taking, wait for its file to be finished, print it and exit |
| `--capture-directory <folder>` | Write here instead of the configured folder. Created if it is not there |
| `--capture-name <name>` | Call the capture this, without a suffix |
| `--sample-rate <msps>` | `40` or `20` |
| `--duration-limit <seconds>` | 1 to 86400. Leave it out to capture until stopped |
| `--output-format <format>` | `flac` or `s16` |

Given without `--start-capture` or `--stop-capture`, the last five simply fill the window in
and start nothing. Whatever they set applies to that run only and is never saved.

```bash
ddd-gui --headless --start-capture --capture-name disc-42-side-1 --duration-limit 1800
```

The finished file's path goes to standard output on its own, and everything meant for a
person goes to standard error — so `file=$(ddd-gui --headless --start-capture …)` is all the
parsing a script needs.

### `--analyse-test-data <file>`

Check a test-mode capture for sequence breaks and exit, without opening a window.

```bash
ddd-gui --analyse-test-data TestData_2026-08-16_14-30-00.ddd.flac
```

| Exit code | Meaning |
| --- | --- |
| `0` | The ramp was intact |
| `1` | It broke |
| `2` | The file could not be analysed |

The verdict goes to standard output and "I could not read this" to standard error, so a
script collecting results does not end up with a message about its own arguments in the
collection. On Windows it goes to the console the application was started from, or wherever
a caller redirected it; the exit code works either way, and that is what a script actually
reads.

This is the same analysis **Tools → Test data → Analyse test data…** performs, over the same
code. See [Test mode](test-mode.md).

### `--dev-update-key`

Accept a firmware update file signed with the project's **development** key, whose secret
half is public.

A release build pins the release key and accepts nothing else. This widens that for one run,
and the Update page puts a banner on every development-signed file it then opens. It proves
the file is well formed and **nothing about where it came from**, which is the whole reason
it is opt-in and per-run rather than a setting.

You want this only if you are building update bundles yourself; see
[Developer update loop](../development/developer-update-loop.md).

## What is always logged

Three lines every run, whatever the level, because they are what every fault report is read
against:

```
Capture application started.
Application commit c6ca52b4-dirty.
Platform: NixOS 26.05 (Yarara), kernel linux 6.18.43, x86_64, Qt 6.11.1.
```

The commit is the build; **Help ▸ About** carries the identical string. The platform line
names the operating system as it names itself, the kernel — which is the version that
actually decides how USB behaves, and is the one a kernel-level fault is filed against — the
processor architecture, and the Qt in use. A packaged build that ships one Qt and loads
another says both versions, which is a class of fault that reads as an application bug until
this line contradicts it.

## What debug level records about a capture

`info` says a capture started, stopped, and how it ended. `debug` adds the account a
developer needs to say *why* it ended that way, and none of it needs a rebuild to turn on.

**When the stream starts**, the ring it will run with — asked for, planned, and how much
time it buys before a sample would be lost — and every option the run was made under, so a
log can be read without the settings file that has since been changed.

```
Ring: 256.0 MiB asked for, 127 slots of 2.0 MiB = 254.0 MiB, which is 3.33 s of
  headroom at 40.0 Msps (80.0 MB/s)
Options: test mode off, memory locking on, priority elevation on, stall timeout
  5000 ms, snapshot every 4 buffers of 64.0 KiB, throughput window 1000 ms,
  progress every 10000 ms
```

**While it runs**, a line every ten seconds carrying the throughput against what it should
have been, the ring depth, the device's back pressure, and how much has reached the file.
This is the record of *when* a squeeze happened, which no figure taken at the end can give.

```
Capturing for 4 m 12 s: 9648 buffers, 79.9 MB/s (99.9% of the wire rate), ring
  1/127 slots, peak 6; device buffer 0% back pressure, peak 34%; written
  9.42 GiB (4 m 12 s of stream)
```

**When a capture file closes**, what actually reached it: samples, the length of stream
they are, the size on disk and what that is as a fraction of what arrived — which is the
compression a FLAC capture achieved — and how long the encoder's final flush took, since
that pause is paid for out of the ring's headroom.

```
Closed flac after 9648 buffers over 4 m 12 s: 10113318912 samples = 4 m 12 s of
  stream, 9.42 GiB on disk (46.7% of the 18.83 GiB that arrived), finishing took
  214 ms
Capture file: 10113318912 samples over 4 m 12 s, 9.42 GiB of 18.83 GiB that
  arrived (50.0%), 38.3 MB/s to disk
Signal in the file: range 41-980 of 1023, RMS 331.2, clipped low 0 high 0
While this file was open: device lost 0 samples in 0 overflows; session peak back
  pressure 34%, session peak ring depth 6 of 127 slots
```

**When the stream stops**, the whole run: what went through, how full each buffer got, and
what the device's own FIFO did. Back pressure is reported as a mean and as counts at three
levels beside the peak, because a run that touched three quarters of the ring once and one
that sat there for twenty minutes report the same peak and are not the same capture.

```
Run: 4 m 20 s, 9962 transfers, 9962 buffers = 19.45 GiB = 4 m 20 s of stream,
  averaging 79.8 MB/s (99.8% of the wire rate, counting the discarded opening
  slots and anything still in flight)
Ring depth: mean 0.9%, peak 4.7% (9962 readings), never over a quarter full; peak
  6 of 127 slots, 9962 filled, 9962 freed
Device back pressure: mean 2.1%, peak 34% (1043 readings), over a quarter for 3,
  never over half; at or above the gateware's near-full mark for 1.42 s, peak
  9216 words
Signal over the run: 10402320384 samples, range 38-988 of 1023, RMS 330.9,
  clipped low 0 high 0; sequence intact
```

Two of those figures are worth knowing how to read:

- **Ring depth** is the host keeping up. A healthy capture sits near zero and never
  climbs; a mean that is not near zero means this machine is only just managing, whatever
  the peak says.
- **Device back pressure** is the device waiting for the host to take packets, on a scale
  where zero means every packet was taken as soon as it was offered and one hundred means
  samples were lost. The near-full time beside it is how long the device spent close to
  the edge, which is the figure that survives a squeeze nobody was reading at the moment
  it happened.

## What debug level records about an update or a bring-up

Installing firmware and bringing a board up are the two operations that touch a device
permanently, and both are minutes long. At `debug` each keeps its own account, and the
engine's half and the interface's half go to the same place.

**Choosing a file** — what it is, whether it verified, and what the compatibility gate made
of it beside the device it was asked about. A file that verifies and cannot be installed is
the commonest thing to be handed, and the verdict alone does not say why:

```
Update page: opening /home/me/Downloads/domesday-duplicator-update-1.4.0.dddfw
Update file verified: version 1.4.0, release channel, 3.41 MiB, …
Compatibility gate: allowed (device attached, personality application, firmware
  protocol 2, register map 3)
```

**Installing** — what the file carries, what is being written, the shape the device
negotiated, and how long each part took:

```
Update starting: bundle version 1.4.0, channel release, restart deferred no
  carries firmware 4d23a25, 195.3 KiB, sha256 c7a7d73b, interface version 2
  carries gateware 4d23a25, 1.02 MiB, sha256 91b0e47c, interface version 3
Installing firmware 4d23a25, 195.3 KiB, …: 98 chunks of 2.0 KiB (the device
  offered 2048 bytes), device phase idle
Sent the whole firmware: 98 chunks, 195.3 KiB in 12.41 s (16.1 KiB/s). Waiting for
  the device to finish writing and reading back.
Installed firmware after 41.20 s
Update finished after 3 m 04 s: succeeded at stage Complete, identity confirmed,
  device reports "Domesday Duplicator (4d23a25)", gateware 4d23a25
```

**When it fails** — the device's own account of itself at the moment it stopped, which is
the diagnosis and the one thing nobody can go back and ask for afterwards:

```
Failed to install firmware after 2.31 s: The device could not write to its own
  memory. The update was not completed.
Device status at the failure: phase failed, error write (10), 200000 received,
  0 written, 0 verified
Update finished after 2.34 s: failed at stage Failed, identity not confirmed; …
```

**A bring-up** records the same for its writes, and around them the procedure itself: every
page the wizard visited, what the USB-Blaster probe found, whether the file carries all four
payloads a bring-up needs, each step and how long it took, and — because the JTAG step is
allowed a second attempt — what each attempt did:

```
Bring-up: moved to page 4 of 8 — Load the gateware
Bring-up: USB-Blaster probe: opened
Bring-up: update file verified: version 1.4.0, release channel, carries firmware
  yes, factory image yes, gateware yes, JTAG vectors yes
Bring-up: starting the gateware-over-JTAG step
Configuring the FPGA over JTAG: 1.38 MiB of vectors from the update file, up to 2
  attempts. Nothing is written to the board by this step.
JTAG attempt 1: succeeded after 2.71 s, cable opened, 1284 statements, 5717248
  bits shifted
Bring-up: the gateware-over-JTAG step succeeded after 2.83 s
Programming the board, in the one order that leaves every interruption
  recoverable: EEPROM (195.3 KiB), factory image (1.02 MiB), then application
  image (1.02 MiB). Nothing is restarted here.
```

and, at the end, the last page's verdict check by check — a board that fails one of them is
a completely different problem from one that fails all of them.

## A related tool

`ddd-update` installs a firmware bundle from a shell, over the identical engine code the
application's Update page uses. It links no Qt at all. It is built alongside the
application from source but is not part of the released packages — it is a developer tool,
and [Developer update loop](../development/developer-update-loop.md) is its page.

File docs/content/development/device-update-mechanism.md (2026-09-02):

# Device update mechanism

How a Domesday Duplicator updates its own firmware and gateware over the one USB cable it already has, with no jumper, no second cable, no Quartus and no command line.

!!! note "Specification first, and now built end to end"

    This page is **normative**: it defines the protocol, the register map and the compatibility rules that the firmware, the gateware and the capture application are built to. All of it now describes something that exists.

    **Target 0 — the FX3 boot EEPROM — is implemented and proved on hardware.** The firmware answers `0xD0`–`0xD4`, brings up its own I2C block, writes and verifies its own boot EEPROM, and advertises a protocol version in `bcdDevice`. The application installs a bundle through it and `ddd-update` does the same headlessly.

    **Target 1 — the FPGA's EPCS — is implemented and proved on hardware.** The firmware drives the EPCS through the gateware's flash bridge: it identifies the flash, erases and programs the application region, reads it back to check the digest, writes the boot block last, and answers `0xD5`. Both gateware images implement register map version 2 around it. A unit was provisioned, updated and handed over from the factory image to the application image on 2026-08-15; the procedure is §6 of TESTING.md, and the defects that first session found are recorded there and on the [EPCS layout and boot flow](epcs-layout-and-boot-flow.md) page.

    Both numbers this page used to carry from documentation are now measurements: the flash's silicon identifier is `0x16`, and how long an update takes is under [Writing the EPCS](#writing-the-epcs-what-target-1-actually-does) below. What has *not* been exercised is the interruption half — power lost mid-write or mid-verify — which is the next bench session, and which the commit ordering below is what will be under test.

## The problem

Updating a Duplicator today needs tools and physical intervention. The FX3 firmware needs `fx3-programmer`, the J4 boot jumper and a power cycle; the FPGA gateware needs Quartus, the DE0-Nano's second USB cable and `quartus_pgm`. Both live in the *hardware programming* section of this site and both are developer procedures. A user with an assembled, cased unit cannot follow either.

The two halves of that problem have different shapes, and only one of them is a software problem.

The FX3 boots from an I2C EEPROM on the Explorer Kit. Its I2C pins are dedicated — not shared with the 16-bit GPIF bus or the UART — so the running firmware *can* bring up the I2C block and rewrite its own boot EEPROM. It simply does not today.

The FPGA is harder, and the reason is in the wiring rather than in the code: **the FX3 has no electrical path to the FPGA's configuration circuitry**. A trace of the schematics finds the GPIF data bus, `USB_PCLK`, the CTL lines carrying the SPI register link and `nReset`, sixteen wired-but-unused data lines and one spare — and no JTAG, no active-serial pins, no `nCONFIG`, no `nSTATUS`, no `CONF_DONE`, no MSEL. The EPCS64 configuration flash sits on the DE0-Nano's own dedicated pins and never leaves that board. So the only route from the host to the EPCS is *through the FPGA fabric*, using the Cyclone IV's `asmiblock` primitive to reach the flash and `rublock` to trigger reconfiguration.

That single fact shapes the whole design. It is also why loading the gateware from the host at every connection — the obvious way to make staleness impossible — is not merely inadvisable here but electrically impossible.

## One agent, three targets

```
ddd-gui ──EP0 vendor requests──▶ FX3 application firmware
                                    │
                                    ├─ target 0:  I2C block ──▶ boot EEPROM (M24M02)
                                    │
                                    ├─ target 1:  bit-banged SPI ──▶ spiRegisters
                                    │                   │ (flash bridge unlocked)
                                    │                   └──▶ asmiblock ──▶ EPCS64
                                    │                        rublock  ──▶ reconfigure
                                    │                          application image, 0x200000
                                    │
                                    └─ target 2:  the same route, the factory image at 0
```

The FX3 application firmware is the single on-device update agent. It is its own flasher for its own EEPROM, and it is the host's proxy for the EPCS. The gateware stays deliberately dumb: it offers a byte-at-a-time SPI pass-through and a reconfiguration trigger, and every decision about erase order, page programming and verification lives in C, where it can be reviewed and — for the pure parts — tested without hardware.

The alternative was a flash command engine in the gateware, with the firmware relaying. It is functionally equivalent and was rejected because it puts the complexity in the half of the project with the weakest test coverage. The gateware's job here is small enough to review line by line, which matters more than usual because half of it ends up in an image that can never be updated in the field.

## The vendor protocol

Six requests, all on endpoint 0. Existing codes are untouched: `0xA0` belongs to the Cypress boot ROM, `0xB0`/`0xBA`/`0xBB` to the Cypress flash programmer personality, and `0xB5`–`0xB8` to this firmware's capture and register interface.

`wIndex` selects the target throughout: **0** is the FX3 boot EEPROM, **1** is the FPGA EPCS application image, **2** is the same flash at the factory image's address. A request naming any other target stalls.

Target 2 is the one a user never reaches. It is written by a board bring-up and by nothing else — that is the one flow which replaces the image a board falls back to — and it is refused unless `UPDATE_BEGIN` carries the factory-write word below. Adding it was an **additive** change and deliberately did not bump the protocol version: no existing field changed meaning.

There is no firmware in the field without it. The first release of this firmware carries all three targets, and everything published before it is the original firmware, which has no update agent at all and is recognised on the bus rather than asked. So this page describes no fallback for a device that speaks the protocol but lacks target 2 — that combination exists only as an intermediate build inside this repository, and designing a recovery path around it would be documenting the development process rather than the product.

| Request | `bmRequestType` | Direction | Data stage | Purpose |
| --- | --- | --- | --- | --- |
| `0xD0` `UPDATE_STATUS` | `0xC0` | IN | 16 bytes | Phase, byte counter, last error, capability bits |
| `0xD1` `UPDATE_BEGIN` | `0x40` | OUT | 40 bytes | Payload length and SHA-256; enters update mode |
| `0xD2` `UPDATE_DATA` | `0x40` | OUT | ≤ 2 KiB | One chunk; `wValue` is the chunk index |
| `0xD3` `UPDATE_FINISH` | `0x40` | OUT | none | Finish writing, verify by readback, commit |
| `0xD4` `DEVICE_RESET` | `0x40` | OUT | none | Cold reset; the device re-enumerates |
| `0xD5` `FPGA_RECONFIG` | `0x40` | OUT | none | Trigger reconfiguration from the application image |

### `0xD1` UPDATE_BEGIN

| Offset | Size | Field |
| --- | --- | --- |
| 0 | 4 | Payload length in bytes, little-endian |
| 4 | 32 | SHA-256 of the payload |
| 36 | 4 | Flags, little-endian. `0x00000000` for targets 0 and 1; `0x57464444` — `'D','D','F','W'` on the wire — unlocks target 2. Any other value is refused |

**The flag word is a guard against a mistake, not against a determined host**, and it is sized for exactly that. Writing the factory region is safe when it is meant and irreversible when it is not, so a host that means target 1 and sends a 2 is refused because it carries a zero flags word. Nothing stronger is needed here: recovery from a half-written factory region needs JTAG, and every DE0-Nano has a USB-Blaster soldered to it — the cable is present on every unit this could happen to, and connected by definition during the one flow that uses the target. The word is required *only* on target 2, and target 2 is refused without it, so neither can be reached by accident from the other.

The digest arrives *before* the first byte of payload, which is what lets the firmware hash the incoming stream as it arrives and abort before anything is committed. It is SHA-256 and not a CRC because it is the same number the bundle's manifest carries and the same number CI computed at build time — one digest, checked at every hand-off, is the rule the whole chain is built on.

`UPDATE_BEGIN` is refused while a capture is running, and a capture is refused while an update is in progress. The two are mutually exclusive by state, not by convention.

### `0xD2` UPDATE_DATA

`wValue` carries the chunk index, starting at zero and incrementing by one. A chunk that arrives out of order fails the transfer rather than being buffered: the host is a program, not a network, and a gap in the sequence means something has gone wrong that reordering would hide.

Every chunk but the last is the full chunk size the device advertises in `0xD0`, and **every chunk but the last must be a whole number of the target medium's pages** — 64 bytes for the EEPROM, 256 for the EPCS. That is the one constraint the protocol puts on the host, and it is there so that the firmware can write a chunk straight to the medium with no assembly buffer in between: a page write that runs past the end of its page wraps to the start of the same page on both media, so the alignment has to hold somewhere and the host is the cheapest place for it to hold.

A host that takes the advertised chunk size and rounds it *down* to a multiple of **256** satisfies both targets for any advertised size, which is what the application does rather than assuming 2048. One alignment for both, because a whole number of the larger page is a whole number of the smaller one.

The last chunk carries whatever is left. On the EEPROM the firmware zero-pads its final page on the way out, and the padding is outside the payload the digest covers; on the EPCS nothing beyond the payload is written at all, because an erased flash byte already reads as what an unwritten byte should be.

Chunks are acknowledged by the control transfer itself; per-target flow control — I2C page-write timing, EPCS busy polling — happens inside the firmware between chunks, so the host never has to know the medium's timing. **The host must therefore put no deadline on `0xD2`**, and this matters far more for the gateware than for the firmware: the chunk that opens a new 64 KiB flash sector pays for that sector's erase, which the part specifies at a second typically and three at worst. Roughly one chunk in thirty is seconds long, and the application's progress line says so rather than leaving a bar to pause unexplained.

**Each EEPROM page is attempted up to four times before the transfer is given up.** A firmware image is a little over two thousand 64-byte page writes and a few hundred readback reads, and until this was added every one of them had to succeed or the whole update was abandoned — which is an unreasonable thing to ask of an I2C bus. The SDK documents its own timeout return as retryable with no recovery needed, and a board whose bus is marginal (long wiring, weak pull-ups, a rail sagging under a just-configured FPGA) fails one page somewhere in the middle, in a different place every run, and never completes. Between attempts the firmware settles the bus and then waits for the part to acknowledge its own address again rather than guessing how long its internal write cycle needs.

Retrying is safe because a page write is idempotent and the whole page is rewritten, not the part of it that did not go: a transfer that died part way has left an unknown number of bytes in the part's page buffer, and refilling it is the only way to know what is in there. Nothing about this weakens the guarantee, either — what decides whether an update commits is the readback digest over the medium, never the fact that a write returned success.

### `0xD3` UPDATE_FINISH

The firmware completes any outstanding writes, reads the written region **back from the medium**, recomputes SHA-256 over what it read, and compares it against the digest from `UPDATE_BEGIN`. Only on a match does it write the commit record. The result is read with `0xD0`; `UPDATE_FINISH` itself does not stall on a verification failure, because "the update failed and here is why" is more useful than a stalled endpoint.

`UPDATE_FINISH` **returns immediately**. It checks the stream digest — the cheap half, over bytes already in RAM — and if that passes it moves to the verifying phase and hands the readback to the firmware's application thread. The readback is tens of seconds of I2C for the EEPROM and minutes for the EPCS, and a control request that took that long to answer would be abandoned by the host long before it did. The host watches the `bytes verified` counter and waits for the phase to reach complete or failed.

That split is also why the phase, rather than a lock, decides which of the firmware's two threads may touch the medium. Every request the USB setup callback would honour is refused during the verifying phase, so the application thread has the medium to itself; and `UPDATE_STATUS`, which is what the host's progress display is made of, stays answerable throughout because it takes no lock at all.

The same asymmetry explains which failures stall and which do not, and the dividing line is *when the answer is known*, not how serious it is. A refusal that can be reached before the request's data stage is read stalls; one that cannot be reached until afterwards is answered through `UPDATE_STATUS`, because the USB hardware acknowledges a control-OUT transfer as soon as its last byte arrives and a request whose payload has been taken can no longer be refused.

So two kinds of refusal stall. A request whose *shape* is wrong — an `UPDATE_BEGIN` that is not 40 bytes, a chunk larger than the advertised maximum. And **an `0xD2` the transfer's own state cannot accept**: the wrong target, an index out of sequence, a length that is not a whole number of pages or would overrun, or a transfer that is no longer receiving because it has already failed. All of that is in the request's fields, so none of it has to wait for the data.

That second case is the one that matters in practice. Without it a device that fails a write part way through an image goes on acknowledging every chunk that follows, and a host has no other signal to read: it sends the whole remaining image — tens of seconds of it — into a transfer that ended long ago, and only learns what happened when it reads `UPDATE_STATUS` at the end. Stalling costs no diagnosis, because the host reads `UPDATE_STATUS` on a failed chunk anyway and the *first* error recorded is the one kept: what it finds there is the write that failed and the offset it reached, not the sequence refusal that followed from it.

A content refusal still cannot stall, and `UPDATE_FINISH` still does not: "the update failed and here is which check caught it" is worth more to whoever is looking at the screen than an endpoint that simply stopped answering.

### `0xD0` UPDATE_STATUS

| Offset | Size | Field |
| --- | --- | --- |
| 0 | 1 | Phase: idle, receiving, writing, verifying, complete, failed |
| 1 | 1 | Last error code, zero when there has been none |
| 2 | 2 | Maximum chunk size the device accepts, little-endian |
| 4 | 4 | Bytes received so far |
| 8 | 4 | Bytes written to the medium so far |
| 12 | 4 | Bytes verified so far |

Three separate counters, because they move at very different speeds and a progress bar driven by one of them would lie during the other two. Transferring a gateware image over EP0 takes seconds; erasing and programming the EPCS takes minutes; verifying takes about as long as reading it back. A user watching a single bar would see it fill quickly and then apparently stop.

The status request is answerable at any time, including when no update is in progress, and it is how the host discovers the chunk size rather than assuming one.

### `0xD4` DEVICE_RESET and `0xD5` FPGA_RECONFIG

`0xD4` is `CyU3PDeviceReset(CyFalse)` — a cold reset, so the FX3 re-reads its boot source and comes back running whatever is now in the EEPROM. It also closes a long-standing gap: until now the host had no way to reboot the device at all.

`0xD5` writes the reconfiguration trigger through the gateware's `rublock` control. Reconfiguration stops `USB_PCLK` underneath the GPIF, so `0xD5` is always followed by `0xD4`: the FX3 is reset rather than left holding a capture path whose clock has gone away.

It is refused — by stalling — when no gateware carrying the flash bridge is answering, and while a transfer is open. Acknowledging either would tell a host that a reconfiguration had happened when nothing had, and the second case would pull the bridge out from under a write in progress.

What the FPGA reconfigures *to* is the factory image, not the application image. The factory image then makes the same boot decision it makes at every power-on, with whatever the flash now holds. That asymmetry is deliberate: an update ends with the device booting the way it always boots, rather than the way a special case in the application image thought it should, so the path taken after an update is the path every unit has exercised since it was provisioned.
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

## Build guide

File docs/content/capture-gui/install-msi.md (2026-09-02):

# Windows — MSI

The Windows package is a standard MSI installer carrying the application, the Qt runtime,
libFLAC and libusb.

**Windows 11 (64-bit) only.** Windows 10 and earlier — including Windows 8, 7 and XP — are
not supported, and no package is built for them. The application is built and tested against
Windows 11 alone; an older release may install, but nothing about it is tested and problems
on it are not something the project can act on.

## Install

Download `DomesdayDuplicator-<version>-windows-x64.msi` from the
[releases page](https://github.com/Domesday86/DomesdayDuplicator/releases), then verify it
in PowerShell:

```powershell
Get-FileHash DomesdayDuplicator-<version>-windows-x64.msi -Algorithm SHA256
```

and compare against the line for that file in `SHA256SUMS`.

Run the installer. It installs to `C:\Program Files\Domesday Duplicator` and adds a Start
menu shortcut.

## First launch: SmartScreen

**The installer is not code-signed**, so Windows will show:

> Windows protected your PC — Microsoft Defender SmartScreen prevented an unrecognised app
> from starting.

Click **More info**, then **Run anyway**. Code signing needs a certificate held by an
individual, which is not something a community project's CI can hold; verifying the
download against `SHA256SUMS` gives you the same assurance that the file is the one that
was released.

## You still need the WinUSB driver

**The MSI does not install a device driver.** Windows will not let the application talk to
anything on the USB bus until WinUSB is bound to it, and shipping a driver package requires
a signed `.inf` — the same problem as above.

Windows binds drivers **by USB identifier**, so this is not one binding: it is one per
identifier the hardware can present, and a board that is new, legacy or half-programmed
presents *different* identifiers from a working one. That is why a board can be plugged in,
lit up and completely absent from the application. The bindings are done once per machine
with [Zadig](https://zadig.akeo.ie/), and they persist.

| What it is | Shows in Zadig as | USB ID | Bind it when |
| --- | --- | --- | --- |
| A working Duplicator | `Domesday Duplicator (…)` | `1209:2347` | Always — this is what the capture window opens. Already done if this machine has ever run one; on one that has not, and where a board is about to be brought up, create it in advance as below |
| The FX3 in its boot ROM | `WestBridge` | `04B4:00F3` | The board is new, legacy, or an update was interrupted |
| The DE0-Nano's on-board USB-Blaster | `USB-Blaster` | `09FB:6001` | You are bringing the board up, or reprogramming its FPGA |

Binding a device that is plugged in is the same four steps:

1. Plug the device in.
2. Run Zadig, and choose **Options → List All Devices**.
3. Pick the device by the identifiers in the table — the **USB ID** field in Zadig shows
   them, and it is the field to go by rather than the name.
4. Choose **WinUSB** in the driver box and click **Replace Driver**.

**A board is only ever one of these at a time**, because whatever firmware it is running is
what it enumerates as. A board running this project's firmware shows `1209:2347` and a board
running the original firmware shows `1D50:603B` — and neither of them shows `04B4:00F3`,
however long you look. To bind `04B4:00F3` you first have to put the board *into* its boot
ROM by fitting jumper J4 and power-cycling it — see
[If the board does not show up as a Domesday Duplicator](#if-the-board-does-not-show-up-as-a-domesday-duplicator)
below.

### Binding an identifier the board is not presenting yet

The four steps above need the device in front of Zadig, and one of these bindings cannot be
done that way. A board being brought up does not present `1209:2347` until it has been
programmed, and it cannot be programmed until the application can open what it becomes — so
on a machine that has never had a working Duplicator plugged into it, that binding has
nothing to attach to at the moment it is needed.

**Zadig can install a driver for an identifier nothing is presenting.** Use
**Device → Create New Device**, which writes the driver into Windows' driver store so that
PnP matches it when a device with those identifiers eventually appears:

| Field | Enter |
| --- | --- |
| Device name (top box) | `Domesday Duplicator` |
| USB ID, first box | `1209` |
| USB ID, second box | `2347` |
| USB ID, third box (Advanced Mode only) | leave empty |
| Driver | `WinUSB` — the left-hand box reads `(NONE)`, which is correct for a device that is not there |
| Button | **Install Driver** |

The third USB ID box is the interface number, for composite devices. The Duplicator has a
single interface, so anything entered there produces a driver that never matches.

The name is cosmetic — it becomes the device's description in Device Manager. Use the plain
name rather than the full product string the firmware reports, which carries the build's
commit hash: the binding outlives firmware updates and a hash in it would stop being true at
the first one.

To check it took, before there is any board to test it with:

```powershell
Get-ChildItem C:\Windows\INF\oem*.inf | Where-Object {
  ([Text.Encoding]::ASCII.GetString([IO.File]::ReadAllBytes($_.FullName)) -replace "`0") -match 'VID_1209&PID_2347'
} | Select-Object -ExpandProperty Name
```

One `oemNN.inf` back means the driver is in the store and keyed on the right identifier.
Nothing back means the install did not take, or the identifiers were mistyped. The
byte-for-byte read is deliberate: these files may be UTF-16, and `findstr` finds nothing in
those without saying so, which looks exactly like a driver that was never installed.

The application says so plainly when it cannot open a device it can see, so a missing
binding looks like a clear message rather than an empty device list.

## If the board does not show up as a Domesday Duplicator

If Zadig lists no `1209:2347` at all, your board is not running this project's firmware, and
no amount of driver binding will make it appear as a Duplicator. What is listed instead says
which case you are in:

| Zadig lists | What the board is | What it needs |
| --- | --- | --- |
| `04B4:00F3` (`WestBridge`) | An FX3 sitting in its boot ROM: a newly built kit whose EEPROM has never been written, or a board left half-programmed by an interrupted update | Bring-up, or a firmware repair |
| `1D50:603B` | The **original** Duplicator firmware, from before this application existed | Bring-up — and note that this is what Zadig shows *instead of* `04B4:00F3` until jumper J4 is fitted |
| `04B4:0007` only | The FX3 kit's debug serial port. The board has power but its USB 3.0 link is not answering | Check the USB 3.0 cable, and that it is in a USB 3.0 socket |
| Nothing from that board at all | No data cable, no power | A cable that carries **data**, in a working socket |

For the first two, the way forward is
**Tools ▸ Firmware ▸ Bring up a new or legacy board…** — see
[Bringing up a new or legacy board](bringing-up-a-board.md). It programs the FX3's firmware
*and* both images in the FPGA's flash, which is what a new or legacy board needs; the
firmware alone would leave you with a device that enumerates and cannot capture.

**On Windows that wizard needs up to three bindings**, and each has to be in place before
the step that uses it:

1. **`04B4:00F3` — the FX3 in its boot ROM.** The wizard fits jumper J4 and hands the
   firmware to the FX3's built-in loader over the USB 3.0 cable. Until WinUSB is bound to
   `04B4:00F3` the application cannot open the board in that state at all, so the wizard's
   connectivity page marks the FX3 row as a problem and will not go on.

   **Putting the FX3 into its boot ROM so Zadig can see it.** A board that is running
   firmware — legacy or otherwise — does not present `04B4:00F3`, so there is nothing for
   Zadig to bind: a legacy board shows `1D50:603B` and a working one shows `1209:2347`.
   Do this first, in this order:

   1. **Unplug the USB 3.0 cable from the FX3**, and the DE0-Nano's mini-USB USB-Blaster
      cable too if it is connected. Either cable on its own keeps the unit powered, and the
      jumper is only read at boot — so with either still attached the board never reboots
      and nothing changes.
   2. **Fit jumper J4** across the FX3 board's two-pin `PMODE` header.
   3. **Plug the USB 3.0 cable back in.** The board boots into its boot ROM and enumerates
      as `04B4:00F3` (`WestBridge`).
   4. **Now run Zadig** — **Options → List All Devices** — and bind `04B4:00F3` to WinUSB.

   Leave J4 fitted afterwards: this is also the state the wizard's step 2 asks for, so
   nothing is wasted, and the wizard takes the jumper back off at step 6.

   If you also need `09FB:6001` bound, reconnect the mini-USB cable once the FX3 binding is
   done and bind that in the same Zadig session.

2. **`09FB:6001` — the DE0-Nano's on-board USB-Blaster.** This is the JTAG cable that loads
   the gateware into the FPGA, and it is the only route to a board whose flash holds nothing
   the application can talk to. It appears on the DE0-Nano's **mini-USB** connector, which is
   a second cable to the same assembly — connect it before running Zadig. Without this
   binding the wizard's FPGA row is a problem too.

   **The wizard can see this cable whatever it is bound to**, unlike the FX3 above, so a
   missing binding here reads as *a USB-Blaster is attached but this application cannot
   open it* rather than as an empty row. That sentence names the binding, and it means the
   cable and its lead are fine and Zadig is all that is left to do.

   A **charge-only mini-USB cable** is the commonest thing that goes wrong here: the board
   lights up either way, and nothing enumerates. If Zadig lists no `09FB` device, try
   another cable before anything else.

   The application drives the original USB-Blaster, `09FB:6001`, which is what the DE0-Nano
   carries on board. A USB-Blaster II (`09FB:6010` or `09FB:6810`) is a different cable and
   is not driven — the application names it rather than saying nothing was found.

   If you have **Quartus** installed, its own Altera USB-Blaster driver may already be bound
   to this device. Replacing it with WinUSB takes the cable away from Quartus; undo it in
   Device Manager if you want Quartus to have it back. Only one of them can hold the cable.

3. **`1209:2347` — what the board becomes.** The wizard does not merely program the FX3 and
   stop: step 5 hands the firmware to the boot ROM, the board restarts into it, and the
   wizard then **reopens it as a Duplicator** to write the EEPROM and both gateware images.
   So `1209:2347` is needed part way through the wizard, not after it.

   **Usually there is nothing to do here.** If this machine has ever had a working Duplicator
   plugged into it — this board before it was reprogrammed, or another unit entirely — the
   binding is already there and persists, and the wizard runs straight through.

   On a machine that has **never** seen a working Duplicator, the board presents nothing for
   Zadig to pick until step 5 has already programmed the FX3. Create the binding in advance
   instead, with **Device → Create New Device** — see
   [Binding an identifier the board is not presenting yet](#binding-an-identifier-the-board-is-not-presenting-yet)
   above. Do it in the same Zadig session as the other two, before starting the wizard, and
   the bring-up runs straight through.

   **If you reach step 5 without having done it**, the step stops after thirty seconds and
   says that the device is **attached as a Duplicator (1209:2347) but cannot be opened under
   that identifier** — it looks at the bus before it speaks, so this is what a board that
   came back and may not be opened gets, rather than the *did not come back* sentence that
   belongs to a board which never restarted. Nothing was written permanently: the failure is
   before the first write, with the firmware running out of memory. Leave everything plugged
   in, bind `1209:2347` — the board is on the bus now, so the ordinary four steps work —
   and run the wizard again from the start. It assumes nothing about the board's state and
   running it twice is harmless.

   **You do not need to quit the application to do this.** Its device list is re-read five
   times a second, so a binding made while it is running is picked up as soon as Windows
   re-enumerates the device. Only the wizard is restarted, not the program — and if you have
   Zadig already open, binding it inside the thirty seconds step 5 waits lets that step carry
   on by itself.

The bindings survive the bring-up, so a board that later needs bringing up again — or a
second board on the same machine — needs none of this repeated.

## Update

Run the newer MSI. It upgrades in place — there is no need to uninstall first.

## Uninstall

**Settings → Apps → Installed apps → Domesday Duplicator → Uninstall**, or Add/Remove
Programs. The WinUSB driver bindings are separate and stay; undo them in Device Manager if
you want a device back on its original driver.

## First time through

In this order:

1. **Bind the device to WinUSB** with Zadig, as above. Until that is done the application
   cannot open it.

2. **If the board has never been programmed, or is running the original firmware**, bind
   `04B4:00F3` and `09FB:6001` as well — a board running the original firmware has to be
   put into its boot ROM with jumper J4 before Zadig can see `04B4:00F3` at all — then run
   **Tools ▸ Firmware ▸ Bring up a new or legacy board…** — see
   [If the board does not show up as a Domesday Duplicator](#if-the-board-does-not-show-up-as-a-domesday-duplicator)
   above, and [Bringing up a new or legacy board](bringing-up-a-board.md). A board that
   already captures needs none of this.

3. **Tell the application what SW401 is set to.** **File → Settings…**, and set **Front-end
   gain** to the position of the four-way DIP switch on the Duplicator board. The switch is
   mechanical and has no electrical path to anything the application can read, so until it is
   declared every level is shown in converter codes rather than in millivolts. Nothing about
   the capture itself depends on it — see [Front-end gain](settings.md#front-end-gain).

4. **Take a first capture.** The [Quick start](quick-start.md) walks through monitoring,
   setting the player's RF output by what is on screen, and writing a file.

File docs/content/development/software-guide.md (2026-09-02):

# Domesday Duplicator Software Guide

The Domesday Duplicator is a completely open-source and open-hardware solution.  All required files to construct the hardware and all of the source-code is available on Github. The Github repository contains the following items:

* Kicad schematics and PCB design
* FPGA Verilog HDL code for the DE0-Nano
* GPIF II state-machine design for the FX3
* FX3 firmware for the Cypress FX3 board
* Qt 6 GUI capture application for Linux, Windows and macOS

The Github repository is accessible via the following link: [Domesday Duplicator Github](https://github.com/Domesday86/DomesdayDuplicator) 

Every component builds with ordinary, distribution-packaged tools, and the repository provides a Nix flake that supplies them all — see [Building locally](building-locally.md). The one exception is Cypress GPIF II Designer, which produces the FX3's parallel-interface state machine and is Windows-only. Its output is committed to the repository, so it is only needed in order to change the state machine.

# FPGA code
## Purpose
The DE0-Nano FPGA board is used to bridge the Domesday Duplicator's ADC hardware with the Cypress FX3 USB 3.0 board.  The code provides data manipulation, error checking and a 16K word FIFO to allow buffering in case of short constrictions of USB bandwidth to the host computer.  The FPGA code also contains a test data generation function that allows testing of the Domesday Duplicator with known test data (that can be verified as intact once received by the host application).

## Development environment
The FPGA code is built with **Intel Quartus Prime Lite 25.1**. Quartus is free and needs no licence file, but it is a multi-gigabyte download and is `x86_64` Linux or Windows only.

The project files were originally written by Quartus 16.0.2 and 18.0.0. Version 25.1 compiles them unchanged — no upgrade prompt and no source edits — although it does rewrite the `.qsf` in place to record the version that last touched it, which is why builds should be run out of tree.

**The GUI is not required at any point.** Compiling, converting and programming are all command-line tools, and the repository provides a development shell that supplies them:

```bash
nix develop .#fpga-quartus     # Quartus, plus the free tooling below
```

For editing, linting and simulating the Verilog you need no Quartus at all — those tools are free and cross-platform:

```bash
nix develop .#fpga             # verible, verilator, iverilog, gtkwave
./fpga/tests/run-lint.sh       # lint the hand-written modules
./fpga/tests/run-sim.sh        # run the testbenches
```

## USB device configuration
Programming the DE0-Nano needs user-space access to its onboard USB-Blaster. The repository ships the required udev rule — in the same `70-domesday-duplicator.rules` that covers the FX3, so a machine set up for capture is already able to program the FPGA — and the procedure, including the NixOS module that installs it, is on the **[Linux device access](hardware-programming/linux-device-access.md)** page.

!!! warning "If you followed an Altera installation guide"

    Most of them tell you to hand-write `/etc/udev/rules.d/40-altera-usbblaster.rules`. **Delete that file if you have it.** It grants access through `MODE="0666"` alone, which hands write access to every user and process on the machine rather than to the user at the console, and having two files matching the same device makes permission problems much harder to diagnose.

## Building and programming the DE0-Nano
Both steps are covered in full, with the output to expect at each stage and a troubleshooting table, on the **[FPGA bitstream](hardware-programming/fpga-bitstream.md)** page. In brief:

```bash
nix build .#bitstream                              # or ./fpga/build-local.sh
cd result
quartus_pgm DomesdayDuplicator_write_sof.cdf       # volatile, lost on power cycle
quartus_pgm DomesdayDuplicator_write_jic.cdf       # permanent, into the EPCS64
```

The `.cof` conversion setup and both `.cdf` programming files are committed, so no settings need entering by hand. Program the `.sof` first: it cannot leave the board in a bad state, so it is the safe way to test a bitstream before making it permanent.

The DE0-Nano User Manual, which documents the EPCS64 serial configuration device in section 9.1, is available from Terasic.

## Source code modules
### DomesdayDuplicator.v
This module is the top-level verilog module and contains the hardware mapping information for the communication between the FPGA and the ADC as well as the communication between the FPGA and the FX3. The module also includes instantiation code for the Intel IP PLL function, which generates the single 80 MHz system clock the whole design runs from. The ADC's 40 MHz sampling clock is a divide-by-two of that clock generated in the fabric, and the register that divides it also provides the sample enable, so the sampling instant and the ADC clock edge are aligned by construction. The top-level module includes the sub-modules 'dataGenerator', 'buffer' (and the 'fifo' it is built from, and the 'bufferMonitor' that watches it), 'fx3StateMachine' and 'spiRegisters'.  The purpose of these modules is described below.

### dataGenerator.v
The data generator module is responsible for generating data either from the ADC or (if in test mode) internally. When in test mode the generator outputs a repeating sequence of 10-bit numbers, 0 to 1020 inclusive.

The data generator also inserts a sequence number into the top 6 bits of each sample, so that the DomesdayDuplicator application can detect missing samples. The sequence numbers count repeatedly from 0 to 62 inclusive, incrementing every 65535 samples.

Data from the ADC is read on the system clock edge that also takes the ADC clock high — one sample every second cycle — and passed to the FIFO buffer.

The lengths of the test sequence (1021) and the sequence number sequence (63) were chosen in order to maximise the length of time before a USB transfer has the same contents as a previous transfer in test mode (about 210 seconds). The number of samples per sequence number was chosen to allow a length of blocks of missing samples up to 0.1s to be detected correctly; experimentation on a machine with an early USB3 controller showed maximum dropouts of about 0.01s under artifically heavy CPU load, so this gives some additional margin.

The block length is 65535 rather than 65536, and the odd number is deliberate. The host detects loss by predicting the next sequence number, so the one gap it cannot see is a gap of exactly a whole period — all 63 blocks — because that leaves the stream in the phase it would have been in anyway. USB 3 loses capture data a whole endpoint packet at a time, 1024 bytes or 512 samples, and with a block of 65536 the period was 8064 whole packets: a 7.875 MiB hole, a tenth of a second of capture, read as no hole at all. An odd block length shares no factor of two with a packet, so the smallest hole that is both a whole number of packets and a whole period becomes 512 periods — just under 4 GiB, or 53 seconds. The capture application measures the block length off the stream rather than assuming it, so a board carrying gateware from before this change still captures and is still checked.

(In versions of the firmware before June 2022, there were no sequence numbers, and the test sequence ran from 0 to 1023. That firmware enumerates under the old USB identifiers, so the capture application recognises a board running it but does not speak to it — see [bringing up a legacy board](../capture-gui/bringing-up-a-board.md).)

### buffer.v
The buffering functionality is provided by a single FIFO of 16384 16-bit words, implemented in `fifo.v` rather than by vendor IP. It is written one word per sample and read one word per system clock cycle while the FX3 is taking a packet.

The FIFO is twice the packet size, and the packet size (8192 16-bit words) is chosen to match the USB end-point buffer size provided by the FX3 (16 Kbytes). The headroom above the packet is what a USB stall is paid for out of: 8192 words at 40 MSPS is about 205 µs of grace. The module has no collect enable: it buffers whatever `dataGenerator` produces for as long as the FPGA is out of reset.

`dataAvailable` is raised when a whole packet is queued and is then held for the length of that packet, so the FX3 is never told a packet is ready and then made to wait part-way through one. Samples are already 16 bits wide by the time they reach the buffer — `dataGenerator` packs the 10-bit ADC value and the 6-bit sequence number into one word — so no padding happens here. Data is only read from the FIFO while the `isReading` input is asserted, which `fx3StateMachine` holds for the duration of a transfer.

If the FX3 stops reading for long enough to fill the FIFO, the samples that do not fit are dropped and `bufferError` is raised and held long enough for the FX3 to see it. The sequence numbers in the stream let the host find the resulting gap.

(Before 2026 this module was two dual-clock `DCFIFO` instances in a 'ping-pong' arrangement, because a dual-clock FIFO cannot report an exact occupancy and so "is a whole packet ready" had to be answered by filling one buffer completely and swapping. With a single clock domain the occupancy is exact and one FIFO answers it directly.)

### bufferMonitor.v
The buffer monitor watches the FIFO and reports what it did, so that a host can tell a capture that was comfortable from one that nearly failed. It keeps the highest occupancy reached since it was last read and since reset, the number of overflow bursts and the samples they cost, the packets the FX3 has taken, and the time spent at or above three quarters of the depth. The host reaches all of it through registers `0x40` to `0x56` of the SPI register bank — see the [FPGA register interface](fpga-register-interface.md) page for the block and for the read that samples it.

**Every port but one is an output, and the exception reaches nothing else.** The module is given the occupancy, the write enable, the overflow condition and the read strobe, and it is given a one-clock pulse when a host reads the block; that pulse touches only this module's own registers. There is no path from the instrument back into the FIFO, its pointers, `dataAvailable` or the GPIF handshake, so a defect here can misreport a capture but cannot damage one. That is why it is a module of its own rather than a handful of counters added to `buffer.v`.

Reading it is a sampling operation rather than a stream: the link the figures leave by moves about a byte every 80 µs and the occupancy changes every 12.5 ns, so a read copies every counter into a shadow bank in a single clock and clears the interval counters. What comes back over the link is one coherent instant rather than nine counters caught at nine different ones.

A figure worth knowing before reading any of it: on a capture that is keeping up the peak is 8194 of 16384 words on every interval, because the FIFO fills to the 8192-word packet threshold, `dataAvailable` is registered on the next clock, and the FX3 begins draining a cycle or two later while the sampler is still adding a word every second clock. The overshoot is two words, and it is the same two words every time. A peak that *stops* being constant is the FX3 having been late.

### fx3StateMachine.v
The fx3StateMachine module implements the required mirror state-machine for the GPIF II implementation (detailed below).  The state-machine has two states:

1. state\_waitForRequest - The state-machine waits for the GPIF II state-machine to indicate a transfer is about to begin.
2. state\_sendPacket - The state-machine waits for 8192 clock cycles (whilst data is transferred) before returning to the waitForRequest state.

### spiRegisters.v
The spiRegisters module holds the registers that the FX3 reads and writes over the private SPI link between the two boards. It replaced statusLED.v, which used to run a chasing pattern on the DE0-Nano's eight LEDs to show that the gateware was alive.

The registers are a read-only identity block — a fixed signature, the register map version, build flags and the commit the gateware was built from — plus test mode, the LEDs, and (in the application image only) the capture buffer instrument's window at `0x40`–`0x56`. The LEDs are now driven by the FX3, which uses them to report capture state. The gateware lights one of them coming out of reset, so a board that is configured but has not yet been spoken to by the FX3 still looks different from one that is not configured at all.

The commit comes from `version.vh`, which `fpga/generate-version.sh` writes at build time. The copy committed beside the sources reports no commit, which is the honest answer for a lint or simulation run.

The module is a shift register and two counters, framed by chip select. It is deliberately one module rather than a slave and a register file with an interface between them, because what is worth testing is the whole path from an edge on a pin to a register that changed — and `fpga/tests/tb_spiRegisters.v` does exactly that, driving the link at the fastest rate the specification allows.

# Cypress FX3 firmware
## Purpose
The Cypress FX3 firmware provides a DMA driven data transfer between the FPGA and the USB 3 compatible host computer.  A GPIF state-machine design is used to automatically read data from the FPGA and transmit it via USB 3 with minimal interaction of the FX3's ARM processor. 

In addition the FX3 provides a set of generic input and output GPIOs to and from the FPGA.  Currently the firmware monitors the inputs from the FPGA and produces debugging information (via the serial console) if any signal is set, this is to assist with debugging the FPGA code.  Configuration of the FPGA is done through a register bank in the gateware, which the FX3 reaches over a private SPI link and exposes to the host through the vendor-specific commands 0xB7 and 0xB8 described below.

## Development environment
The FX3 firmware is C, built with `arm-none-eabi-gcc` and CMake against the Cypress FX3 SDK 1.3.5. A subset of that SDK is vendored in the repository at `fx3/sdk/`, so no SDK installation is needed. `fx3-mkimage`, this project's own tool, converts the linked ELF into the boot-loadable image; it replaces the SDK's proprietary `elf2img`. The GPIF II state-machine design is developed in Cypress GPIF II Designer 1.0, which is only available for Windows.

Full build instructions, covering both the Nix route and the toolchain-only route, are in `fx3/firmware/README.md` in the repository.

## Programming the FX3
The FX3 is programmed with `fx3-programmer`, a small libusb command-line tool built from this repository. It replaces the Cypress `cyusb_linux` GUI that earlier versions of this page described.

The full procedure — device access, both programming modes, and what to check at each step — is on the **[FX3 firmware](hardware-programming/fx3-firmware.md)** page. In brief:

```bash
# Close jumper J4 (PMODE) and power cycle the board to enter bootloader mode
fx3-programmer -l                   # list connected FX3 devices
fx3-programmer -u firmware.img      # load into RAM: volatile, lost on power cycle
fx3-programmer -p firmware.img -v   # write the I2C EEPROM and verify: permanent
```

Program to RAM first. It cannot leave the device in a bad state — a power cycle undoes it completely — so it is the safe way to find out whether an image works before making it permanent. Remove the J4 jumper and power cycle again once you are done.

## GPIF II
### IO Matrix
The following diagram shows the IO matrix configuration for the FX3 GPIF implementation: 



_Cypress GPIF I/O Matrix view_

The purpose of the signals are as follows:

* CLK - This is the GPIF clock supplied by the FPGA (80 MHz)
* dataAvailable - This signal indicates that there is sufficient data in the FPGA's FIFO buffer for a transfer
* Databus - The 16-bit data bus from the FPGA to the FX3
* nReset - (not) reset condition signal from the FX3 to the FPGA
* collectData - Flag from the FX3 to the FPGA that indicates if the FPGA should collect ADC data. The current gateware ignores this signal and collects continuously — see the note under command 0xB5 below
* readData - Flag from the FX3 to the FPGA indicating that a transfer is about to begin
* input0 - Generic input GPIO from the FPGA to the FX3 - carries the buffer overflow flag in the current gateware
* input1 - Generic input GPIO from the FPGA to the FX3 - unused by the current gateware
* input2 - Generic input GPIO from the FPGA to the FX3 - unused by the current gateware
* input3 - Generic input GPIO from the FPGA to the FX3 - unused by the current gateware
* spiClock - SPI clock from the FX3 to the FPGA, for the register interface below (was outputE0)
* spiMosi - SPI data from the FX3 to the FPGA (was outputD0)
* spiMiso - SPI data from the FPGA to the FX3 (was outputD1)
* spiChipSelectN - SPI chip select from the FX3 to the FPGA, active low (was outputD2)
* (reserved) - Wired but unused, held for a future out-of-band signal (was outputD3)

These five lines used to be five independent configuration bits, of which only test mode was ever used. Four of them now carry an SPI link to a register bank inside the gateware, which is what the vendor commands below reach.

### State machine
The following diagram shows the GPIF II state machine design for the FX3 GPIF implementation:



_Cypress GPIF State-machine view__

The state machine is designed to use the automatic transfer feature of the FX3 where the incoming data from the FPGA is automatically moved to the USB interface by the GPIF module with minimal interaction with the FX3's ARM processor.  The design uses two GPIF 'threads' to ensure minimum delay between transfers.  The GPIF design is configured with 16Kbyte buffers and data is automatically committed to the USB interface once a buffer is full. 

As the GPIF interface is synchronous both threads enter a wait state until the FPGA signals that enough data is available for a transfer.  Once this flag is received the GPIF changes to the 'request' state where it signals to the FPGA that a transfer is about to start (the TH0\_REQUEST and TH1\_REQUEST states repeat for 3 clock cycles to allow time for the FX3 to send the signal and the FPGA to receive it). 

Once the state-machine enters the read state, 8192 16-bit words of data are transferred between the FPGA and the FX3 (filling the available 16Kbyte buffer), the state-machine then commits the data to the USB interface and returns to a wait state.  This design allows for a deterministic transfer with minimal signalling complexity whilst allowing for the non-deterministic nature of the DMA ready state on the FX3 (the buffer 'ready' is unpredictable due to the reliance on the host computer to transfer data in a timely manner).  By using a combination of deterministic and non-deterministic states the GPIF design provides an asynchronous data transfer via the synchronous interface with minimal overhead to ensure high-bandwidth of data transfer. 

Since the FPGA to USB interface is 80MHz (twice the rate of capture) this design allows the USB interface to 'catch-up' rapidly whenever there is a drop in the bandwidth across the USB interface.

## Source code modules
### cyfx\_gcc\_startup.S
This file contains the proprietary start-up code necessary for the FX3 to function - Cypress why-oh-why would you not release this open-source?

### cyfxtx.c
This file contains the Cypress USB 3.0 Platform source file - again under a proprietary license (and necessary for the FX3 to function)

### domesday-duplicator.c
This file contains the main functions for the Domesday Duplicator firmware: device and GPIO initialisation, the application thread, the USB setup and event callbacks, and the start and stop of the capture path.

### domesday-duplicator.h
This file contains the definitions, buffer sizes and function prototypes for `domesday-duplicator.c`.

### domesday-duplicator-gpif.h
This file contains the state-machine definition code generated by the GPIF II designer application. It is generated, not hand-written — the original GPIF II Designer project is also included in the repository. 

### usb-descriptor.c
This file contains the USB descriptor information for the Domesday Duplicator USB device. The product string descriptor is generated at build time so that it carries the commit the firmware was built from.

## Vendor specific USB commands
The firmware handles three vendor specific USB commands: 0xB5, 0xB7 and 0xB8.

### Vendor specific command 0xB5 - Start/Stop data collection
The vendor specific command 0xB5 accepts a value of either 0 or 1. If called with a value of 1 the firmware drives the collectData signal high to tell the FPGA to begin sample data collection; a value of 0 drives it low again. The firmware also uses the command to bracket a capture for link power management purposes, described below.

!!! note "Not currently in use"

    Neither half of this command is live today. The capture application does not send 0xB5, and the current gateware ignores the collectData signal and collects continuously. The command is still implemented in the firmware and the pin is still wired, so restoring the mechanism would be a change to the gateware and the capture application rather than to the firmware.

### Vendor specific commands 0xB7 and 0xB8 - FPGA registers
The gateware holds a small bank of registers that the FX3 reaches over the private SPI link described above, and these two commands relay them to the host.  They replaced command 0xB6, which set the five configuration GPIO pins directly — those pins are now the SPI link itself.

`0xB7` reads registers: `wValue` is the first register address and `wLength` the number of bytes.  The address auto-increments in the gateware, so the whole identity block is one request.  `0xB8` writes one register, with the address in the high byte of `wValue` and the value in the low byte, which keeps it to a setup packet with no data stage.

Because the commands address registers rather than named settings, a register added to the gateware later needs no new firmware command and no new request number to become reachable from the host.

The registers are a read-only identity block — a signature, the register map version, build flags and the commit the gateware was built from — plus test mode and the status LEDs.  The FX3 refuses to relay a host write to the LED register, because it drives the LEDs itself to report capture state.

A device whose FPGA is unconfigured, or whose gateware predates this interface, stalls both commands.  That is not an error condition: capture works normally, and only the gateware version and the status LEDs are lost.

The full contract — pin assignment, SPI mode and timing, the register map, and why this is SPI rather than I2C — is on the [FPGA register interface](fpga-register-interface.md) page.

## USB power management
A USB 3.0 link spends its time in one of four power states: U0 (active), U1 and U2 (progressively deeper idle states, entered and left by the link hardware), and U3 (suspend, which only the host may put the device into and only the device may leave, by signalling remote wakeup). How the firmware treats each is a deliberate design point, because a capture device that gets it wrong either drops samples or stops the host machine from going to sleep.

### U1 and U2
The USB driver's own handling of U1 and U2 is left in place while the device is idle, so an attached-but-unused device does not hold the link at full power. While a capture is running — which the firmware learns from the 0xB5 start and stop commands — U1 and U2 entry is refused, both by `CyU3PUsbLPMDisable()` and by the firmware's LPM request callback. U2's exit latency is up to 2ms, which is long enough for the FPGA's FIFO to overflow mid-capture. Normal handling is restored on stop, and on every USB reset, connect and disconnect, as the FX3 SDK requires for USB compliance. Because nothing sends 0xB5 today, that suppression is dormant; the FX3's own driver still declines U1 and U2 whenever it has packets waiting to go out.

### U3, host sleep and hibernate
When the host suspends the bus, the firmware stops the FPGA collecting, discards anything still buffered, and then leaves the link alone. It does **not** try to bring the link back to U0: requesting U0 from U3 *is* remote wakeup signalling, and a device that does it wakes the machine up again the moment it tries to sleep. The device does not advertise remote wakeup in its configuration descriptors, because it has nothing to wake a sleeping host for.

On resume the firmware rebuilds the capture path from scratch — endpoint, DMA channel and GPIF state machine — rather than assuming any of it survived. A resume does not necessarily bring a `SET_CONFIGURATION` with it, so nothing else would restore the DMA channel, and a device that enumerates but never delivers another sample is indistinguishable from one that has died.

Hibernating a host removes VBus. That reaches the firmware as a VBus removal event, and the response is to take the USB connection down explicitly and wait for VBus to return before presenting the device again, so it re-enumerates cleanly rather than resuming onto a connection that was torn down underneath it.

### Link speed
The capture path is only started on a SuperSpeed connection; 40 million samples per second is far beyond what a USB 2.0 link can carry. On a 2.0 connection the device still enumerates and still answers control requests, so the host can reset the port and re-train at SuperSpeed — which is what some machines do when resuming from hibernate.

## Serial debug
The FX3 Superspeed explorer board provides a USB 2.0 service debug output.  Connecting this output to a suitable machine with a serial terminal allows monitoring of the debug information from the FX3 firmware. The FX3 serial debug output is 115200 bps 8N1. In order to access any serial port the Ubuntu user account must be a member of the dialout group.  Add your current user account to the dialout group using the following command:

```sudo adduser $USER dialout```

If you have problems getting the ttyACM device configured for use with the Cypress FX3 board, create (as root) the following file:

```/etc/udev/rules.d/49-cypressserial.rules```

Then place the following configuration in the rules file:

```
# 04b4:0007 - Cypress FX3 serial debug port
ATTRS{idVendor}=="04b4", ATTRS{idProduct}=="0007", ENV{ID\_MM\_DEVICE\_IGNORE}="1"
ATTRS{idVendor}=="04b4", ATTRS{idProduct}=="0007", ENV{MTP\_NO\_PROBE}="1"
SUBSYSTEMS=="usb", ATTRS{idVendor}=="04b4", ATTRS{idProduct}=="0007", MODE:="0666"
KERNEL=="ttyACM\*", ATTRS{idVendor}=="04b4", ATTRS{idProduct}=="0007", MODE:="0666"
```

Then issue the following command to re-read the USB configuration rules:

```sudo udevadm control --reload-rules```

# Capture application
## Purpose
The capture application provides a capture front-end for the user. The application also provides a high-speed multi-threaded USB implementation that allows extremely high-speed data transfer from the FX3 in real-time. In addition, a multi-buffer disk IO implementation deals with writing the large amounts of capture data to disk in a timely manner. The application is also capable of sending vendor-specific USB commands to the Domesday Duplicator in order to control and configure the capture device.

![](../capture-gui/assets/main-window.png)

_The Domesday Duplicator capture application_

## Development environment
The application is C++20, built with CMake against Qt 6.5 or later (Core, Gui, Widgets and SerialPort), libusb-1.0 and libFLAC. It builds for Linux, Windows and macOS; Windows uses WinUSB in place of libusb. For instructions on how to build it please see [Building Locally](building-locally.md), which covers all of the components.

The build runs `clang-format` and `clang-tidy` as gates, so compiling is what enforces the code style. Build from `nix develop .#ddd-gui` — both tools change their check sets between releases, and CI runs them from that shell.

## Source code modules

The application lives in [`ddd-gui/`](https://github.com/Domesday86/DomesdayDuplicator/tree/main/ddd-gui). Its defining rule is that the parts which handle sample data link no Qt at all, so they can be unit tested without Qt, libusb or hardware — and if one of them ever grows a Qt dependency, its test binary stops linking.

| Directory | Contents |
| --- | --- |
| `src/capture/` | `ddd::capture` — the engine: the disk buffer ring, sequence validation and metrics, the capture file format, the FLAC writer and reader, the USB back-ends, the test-pattern verifier, and the device update and programming paths. Qt-free, by rule |
| `src/analysis/` | `ddd::analysis` — the display mathematics behind the waveform, spectrum and amplitude panels. Qt-free, for the same reason |
| `src/player/` | `ddd::player` — the LaserDisc player protocol, with one header per supported model under `src/player/players/`. Qt-free, and portless |
| `src/gui/` | `ddd::gui` — the Qt layer, built as a static library, plus `main()` |
| `src/update-cli/` | `ddd-update` — a `main()` over the engine that links no Qt, deliberately: it stops linking the moment a Qt dependency reaches the update path |
| `src/jtag-cli/` | `ddd-jtag` — the same, for the JTAG programming path |
| `src/vendor/` | The only third-party sources here: SHA-256 and Ed25519. Never edited in place — see [`src/vendor/VENDOR.md`](https://github.com/Domesday86/DomesdayDuplicator/blob/main/ddd-gui/src/vendor/VENDOR.md) |

The full layout, including the test binaries and what each of them is allowed to link, is in [`ddd-gui/README.md`](https://github.com/Domesday86/DomesdayDuplicator/blob/main/ddd-gui/README.md).

## Multi-threaded USB transfer architecture
The following diagram shows the approximate structure of the multi-threaded architecture used by the capture application to achieve the required USB and disk bandwidth:

![](assets/software/Transfer-diagram-1_0.png)

_The transfer architecture. The queue entries are asynchronous transfers in flight rather than separate threads_

The USB interface is read through a queue of transfers that are all in flight at once, so the device is never left waiting for the host to ask for more data. These are asynchronous transfers rather than a thread each: libusb's asynchronous API on Linux and macOS, and overlapped IO through WinUSB on Windows. Each completion is written into the current disk buffer slot and the request is immediately resubmitted. The transfer queue size and the disk buffer size are both configurable from the Settings dialog.

The disk buffers are much larger than the individual transfers as, for optimal disk write performance, it is more efficient to write larger blocks of data rather than many smaller writes. Once a disk buffer is full it is marked as ready, and a separate processing thread picks it up, checks the sequence numbers for dropped samples, packs the sample data and commits the result to disk.

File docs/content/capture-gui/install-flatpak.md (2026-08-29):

# Linux — Flatpak

The Linux package is a Flatpak bundle, which brings its own Qt and libFLAC and so does not
care which distribution you run it on.

## Install

Download `DomesdayDuplicator-<version>.flatpak` from the
[releases page](https://github.com/Domesday86/DomesdayDuplicator/releases), then:

```bash
# Verify the download first
sha256sum -c SHA256SUMS --ignore-missing

# Flathub provides the KDE runtime the application is built against
flatpak remote-add --if-not-exists --user flathub https://dl.flathub.org/repo/flathub.flatpakrepo

flatpak install --user DomesdayDuplicator-<version>.flatpak
```

Run it from your desktop's application menu, or:

```bash
flatpak run io.github.simoninns.DddGui
```

## You still need udev rules

**This is the step that catches people out.** A Flatpak cannot install udev rules — they are
host system configuration, and the sandbox has no business writing them. Without them the
device node belongs to root and the application cannot open it, which shows up as the
device simply not being found.

Install the rules once, on the host:

```bash
sudo curl -o /etc/udev/rules.d/70-domesday-duplicator.rules \
  https://raw.githubusercontent.com/Domesday86/DomesdayDuplicator/main/fx3/programmer/configs/70-domesday-duplicator.rules
sudo udevadm control --reload-rules
sudo udevadm trigger
```

Then unplug and replug the device.

!!! warning "Keep the `70-` filename"

    It sorts before `73-seat-late.rules`, which is the file that acts on the `uaccess` tag
    the rules set. Save it under a name sorting after that and the tag is set with nothing
    left to read it, leaving only the rules' `MODE="0666"` fallback doing any work.

One file is all you need. It covers the capture device, the FX3 in its recovery identities,
the debug UART, **and the FPGA's USB-Blaster** — the JTAG cable used to reprogram a board
that an update has left unresponsive. You almost certainly will not need that last one, but
the day you do you will not want to be diagnosing a permissions failure first, so it is
included here rather than in a separate step you would have skipped.

On NixOS, use the module the repository ships instead:

```nix
{
  imports = [ inputs.domesdayduplicator.nixosModules.udev ];
  hardware.domesdayDuplicator.enable = true;
}
```

Details, including how to check the rules took effect, are in
[Linux device access](../development/hardware-programming/linux-device-access.md).

## Why it asks for network access

It does not use the network. The application makes no network connections at all — it does
not check for updates, report anything, or fetch anything.

The permission is there for one reason: a Flatpak without it is put in a network namespace
of its own, and the kernel does not deliver device-attach events into one. Those events are
how the application learns that a Duplicator has been plugged in. Without the permission it
finds a device that was already attached when it started and never notices one attached
afterwards — and, during an update, never notices the device coming back after it restarts
itself.

If you would rather not grant it, you can take it away:

```bash
flatpak override --user --unshare=network io.github.simoninns.DddGui
```

The application is built to cope. It compares what the kernel says is attached against what
its USB library believes, and where the two differ it restarts its USB connection to catch
up — so a Duplicator plugged in afterwards is still found, a fraction of a second later than
it otherwise would be. The permission is what makes that fallback unnecessary rather than
what makes the application work, and the same fallback is what keeps it working inside a
plain container.

## What player control needs

[Player control](player-control.md) drives a LaserDisc player over a serial cable, and that
is a second cable with a second permission behind it. Three things are worth knowing before
you go looking for a Flatpak setting that does not exist:

- **No override is needed.** The same `--device=all` permission that reaches the Duplicator
  reaches `/dev/ttyUSB*` and `/dev/ttyACM*`, because both are inside `/dev`. There is no
  narrower static permission for a serial port and no portal for one, so this single
  permission covers both cables.
- **Your group membership still applies.** Serial devices belong to a group — `dialout` on
  Debian, Ubuntu and Fedora, `uucp` on Arch and its derivatives — and the sandbox keeps your
  supplementary groups rather than routing around them. `sudo usermod -a -G dialout $USER`,
  then **log out and back in**: a group you have just been granted does not apply to the
  session you are already in.
- **Nothing opens a port until you ask it to.** Player control is off until it is switched
  on, so a Flatpak install touches no serial port at all until then.

The rest — which players are supported, how the port is found, and what to do when nothing
answers — is on the [Player control](player-control.md) page.

## Where captures can be written

The Flatpak is granted your home directory plus `/run/media`, `/media` and `/mnt`, which
covers the usual places an external drive is mounted. Captures are large — an hour of
LaserDisc RF is around 90 to 145 GB — so most people write to a second drive, and those
paths are why that works without further configuration.

If your drive mounts somewhere else, grant it explicitly:

```bash
flatpak override --user --filesystem=/path/to/drive io.github.simoninns.DddGui
```

## Update

```bash
flatpak install --user DomesdayDuplicator-<newer-version>.flatpak
```

## Uninstall

```bash
flatpak uninstall --user io.github.simoninns.DddGui
```

The udev rules are separate and stay behind; remove
`/etc/udev/rules.d/70-domesday-duplicator.rules` if you want them gone too.

## First time through

In this order:

1. **Install the udev rules** on the host, as above. Without them the device is not found at
   all.

2. **Join the serial port's group** — `dialout`, or `uucp` on Arch — if you want [player
   control](player-control.md), and log out and back in. Skip it if you are not using it;
   nothing else needs it.

3. **Tell the application what SW401 is set to.** **File → Settings…**, and set **Front-end
   gain** to the position of the four-way DIP switch on the Duplicator board. The switch is
   mechanical and has no electrical path to anything the application can read, so until it is
   declared every level is shown in converter codes rather than in millivolts. Nothing about
   the capture itself depends on it — see [Front-end gain](settings.md#front-end-gain).

4. **Take a first capture.** The [Quick start](quick-start.md) walks through monitoring,
   setting the player's RF output by what is on screen, and writing a file.

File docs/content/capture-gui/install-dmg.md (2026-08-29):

# macOS — DMG

The macOS package is a disk image containing the application bundle, with Qt, libFLAC and
libusb bundled inside it.

**Apple Silicon (arm64) only.** Intel Macs are not supported, and no package is built for
them. The application is built and tested against Apple Silicon alone; on an Intel Mac you
would have to build [from source](../development/building-locally.md), and nothing about
that path is tested.

## Install

Download `DomesdayDuplicator-<version>-macos-arm64.dmg` from the
[releases page](https://github.com/Domesday86/DomesdayDuplicator/releases), then:

```bash
# Verify the download first
shasum -a 256 -c SHA256SUMS --ignore-missing
```

Open the `.dmg` and drag **Domesday Duplicator** to the Applications folder.

## First launch: Gatekeeper

**The application is not code-signed or notarised.** Signing requires a paid Apple Developer
ID held by an individual, and that is not something a community project's CI can hold. The
consequence is that a normal double-click gets you:

> "Domesday Duplicator" cannot be opened because the developer cannot be verified.

To open it the first time:

1. Find the application in Finder (`/Applications`).
2. **Right-click** (or Control-click) it and choose **Open**.
3. Click **Open** in the dialog that appears.

macOS remembers the decision, so subsequent launches are ordinary double-clicks.

If macOS refuses outright — on some versions the right-click route has been removed — clear
the quarantine attribute instead:

```bash
xattr -dr com.apple.quarantine "/Applications/Domesday Duplicator.app"
```

Do that only for a download you have verified against `SHA256SUMS`.

## USB access

No driver or permission setup is needed. macOS lets an unprivileged application claim the
device through libusb, so it should be found as soon as it is plugged in.

## Update

Drag the new version over the old one in `/Applications`.

## Uninstall

Move `/Applications/Domesday Duplicator.app` to the Trash. Settings are stored under
`~/Library/Preferences/com.domesday86.ddd-gui.plist` and can be removed separately.

## First time through

In this order:

1. **Plug the Duplicator in.** No driver or permission setup is needed on macOS.

2. **Tell the application what SW401 is set to.** **File → Settings…**, and set **Front-end
   gain** to the position of the four-way DIP switch on the Duplicator board. The switch is
   mechanical and has no electrical path to anything the application can read, so until it is
   declared every level is shown in converter codes rather than in millivolts. Nothing about
   the capture itself depends on it — see [Front-end gain](settings.md#front-end-gain).

3. **Take a first capture.** The [Quick start](quick-start.md) walks through monitoring,
   setting the player's RF output by what is on screen, and writing a file.

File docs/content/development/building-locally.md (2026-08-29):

# Building Locally

How to build each component from a checkout, out of tree, without installing anything into
the source directories.

Everything here runs from the **repository root**. Each component keeps its own build
directory, so building one never disturbs another and `git status` stays clean.

```bash
git clone https://github.com/Domesday86/DomesdayDuplicator
cd DomesdayDuplicator
```

There are no submodules — a plain clone gives you the whole project.

## Getting a toolchain

**Nix on Linux is the only supported development and build environment**, and nothing needs
installing to use it: each component has a development shell carrying exactly what it needs,
pinned by the repository's single `flake.lock`. If you develop on macOS or Windows, use a
Linux virtual machine.

| Shell | Carries |
| --- | --- |
| `nix develop .#ddd-gui` | Qt 6, libusb, libFLAC, GoogleTest, CMake, Ninja, clangd, clang-format and clang-tidy |
| `nix develop .#fx3` | `arm-none-eabi-gcc`, CMake, Ninja, libusb, GoogleTest |
| `nix develop .#fpga` | verible, verilator, iverilog, gtkwave — free tools, no Quartus |
| `nix develop .#fpga-quartus` | the above plus Quartus Prime Lite (`x86_64-linux` only, several GB) |
| `nix develop .#docs` | MkDocs Material and the site plugins |

These work from any directory in the tree; Nix walks up to find the flake at the root. A bare
`nix develop` gives the all-components shell rather than the one for the directory you happen
to be standing in.

## Why out of tree

Two of the three components have a specific reason beyond tidiness:

- **Quartus rewrites the project file it is given.** `quartus_sh` records
  `LAST_QUARTUS_VERSION` in the `.qsf` as it compiles, so building in `fpga/application` or
  `fpga/factory` dirties a tracked file every single time — and then scatters thirty-odd build products among the
  Verilog sources.
- **The FX3 build is a cross build.** Its CMake cache holds an ARM toolchain, and reusing a
  directory that once configured a host build produces confusing failures rather than clear
  ones.

The GUI has no such trap, but the same habit applies for consistency.

---

## The capture application

```bash
nix develop .#ddd-gui

cmake -B build/ddd-gui -S ddd-gui -G Ninja
cmake --build build/ddd-gui
```

Building it also runs its two quality gates: `clang-format` as a build target and
`clang-tidy` through `CXX_CLANG_TIDY`, so compiling is what runs them. Both tools change their
check sets between releases, and CI runs them from this shell — a clang-tidy of a different
version will disagree with CI in both directions, passing what CI fails and occasionally the
reverse, which is why the shell is pinned rather than assumed.

One consequence worth knowing: changing `.clang-tidy` does not invalidate object files, so
an incremental build re-analyses only what you edited. After a config change, build from a
clean tree before believing a green result.

`QT_QPA_PLATFORM=offscreen` is only needed where there is no display, such as over SSH; drop
it to run the application itself.

### As a Nix package

```bash
nix build .#ddd-gui
./result/bin/ddd-gui --version
```

This builds hermetically, runs the test suite as part of the build, and checks the installed
binary reports its commit. Note that it reads **git-tracked files only** — a new file that has
not been `git add`ed does not exist as far as the flake is concerned, which produces a
confusing "path that does not exist" error. CMake reads the working tree and has no such
restriction, which is why it is the better loop while you are editing.

---

## The FX3 firmware

A cross build for the ARM926EJ-S core in the FX3, so it needs a toolchain file. Pass it as an
**absolute** path — CMake resolves a relative one against the build directory, not the source
directory.

```bash
nix develop .#fx3

cmake -B build/fx3-firmware -S fx3/firmware -G Ninja \
      -DCMAKE_TOOLCHAIN_FILE="$PWD/fx3/firmware/arm-none-eabi-toolchain.cmake"
cmake --build build/fx3-firmware
```

That produces three files in `build/fx3-firmware/`:

| File | What it is |
| --- | --- |
| `firmware.img` | The boot-loadable image — this is what gets programmed |
| `firmware.elf` | The linked ELF it was made from |
| `firmware.map` | The link map, for working out where the space went |

```bash
ctest --test-dir build/fx3-firmware --output-on-failure
```

The build needs `fx3-mkimage` to turn the ELF into the image. If it is not on `PATH` — it is
in the `.#fx3` shell — CMake compiles it from `fx3/mkimage` automatically with the host
compiler, so this works either way.

### The host tools

`fx3-mkimage` and `fx3-programmer` are ordinary host builds and need no toolchain file:

```bash
cmake -B build/fx3-mkimage -S fx3/mkimage -G Ninja
cmake --build build/fx3-mkimage
ctest --test-dir build/fx3-mkimage --output-on-failure

cmake -B build/fx3-programmer -S fx3/programmer -G Ninja
cmake --build build/fx3-programmer
ctest --test-dir build/fx3-programmer --output-on-failure
```

### Loading it onto a device

```bash
./build/fx3-programmer/fx3-programmer -l                                  # list devices
./build/fx3-programmer/fx3-programmer -d 0 -u build/fx3-firmware/firmware.img
```

Reaching the device needs udev rules — see
[Linux device access](hardware-programming/linux-device-access.md) — and the boot-mode
jumper has to be set correctly. [FX3 firmware](hardware-programming/fx3-firmware.md) covers
the jumper, RAM versus EEPROM programming and what each mode looks like on the host.

### As Nix packages

```bash
nix build .#fx3-firmware      # result/ holds firmware.img, .elf and .map
nix build .#fx3-programmer
```

---

## The FPGA gateware

Everything except producing a bitstream is free software and needs no Quartus.

### Lint, simulation and constraints

```bash
nix develop .#fpga

./fpga/tests/run-lint.sh      # T4: verilator --lint-only over the hand-written modules
./fpga/tests/run-sim.sh       # T3: the module testbenches, under Icarus Verilog
./fpga/tests/run-style.sh     # T4: formatting and style, via verible
./fpga/tests/run-sdc.sh       # T4: the timing constraints parse and cover every pin
./fpga/tests/run-version.sh   # T2: the commit-to-register version stamp generator
```

They all work out of tree — they build in a temporary directory and leave nothing behind.
They are the same checks CI runs, as `nix flake check`'s `fpga-lint`, `fpga-sim`,
`fpga-style`, `fpga-sdc` and `fpga-version`, so a clean run locally means a clean run there.

`run-sdc.sh` is worth knowing about, because the timing constraints are the one gateware
source file only Quartus consumes, and Quartus never runs in CI. It checks the two things
that can be checked for free: that the file is valid Tcl, and that it names every pin the
top level maps — a constraint covering fifteen of sixteen databus pins leaves the sixteenth
unanalysed, and nothing else in the tree would notice. Whether the numbers in it are right,
and whether the design meets them, still needs a Quartus run.

### Building the bitstream

This is the one that needs Quartus Prime Lite, which is unfree, `x86_64-linux` only, and a
multi-gigabyte download.

```bash
nix develop .#fpga-quartus -c ./fpga/build-local.sh
```

The script copies `fpga/src` to `fpga/build` and compiles there, for the reason given above —
`quartus_sh` would otherwise rewrite a tracked `.qsf` on every run. Pass a different
destination as the first argument if you want the build somewhere else entirely:

```bash
nix develop .#fpga-quartus -c ./fpga/build-local.sh /tmp/ddd-bitstream
```

It produces `DomesdayDuplicator.sof` (volatile, for JTAG) and `DomesdayDuplicator.jic` (for
the EPCS64 flash), plus a `bitstream-provenance.txt` recording the Quartus version, the source
commit and the digests that make the result verifiable.

Program the board from the build directory:

```bash
quartus_pgm DomesdayDuplicator_write_sof.cdf     # volatile, lost on power cycle
quartus_pgm DomesdayDuplicator_write_jic.cdf     # permanent, writes EPCS64 flash
```

The USB-Blaster needs udev rules — the same `70-domesday-duplicator.rules` that covers the
Duplicator itself; [FPGA bitstream](hardware-programming/fpga-bitstream.md) covers those and
the programming procedure in full.

For a release build rather than an iteration, use the derivation instead — it pins the
toolchain and builds in a sandbox:

```bash
nix build .#bitstream
```

The bitstream is deliberately **not** built by CI. Quartus is `redistributable = false`, so it
can never come from a binary cache and every run would fetch gigabytes from Altera; the
bitstream is built locally and attached to firmware releases by hand, with its provenance
record and digests standing in for a CI build.

---

## The documentation site

```bash
nix develop .#docs
mkdocs build -f docs/mkdocs.yml --strict
mkdocs serve -f docs/mkdocs.yml     # live preview on http://127.0.0.1:8000
```

`--strict` is what CI uses: it fails on a broken internal link or a page missing from the
navigation, so a clean local build means the deploy will not surprise you.

---

## Everything at once

```bash
nix flake check
```

Builds every component and runs every test suite — the GUI, the FX3 firmware and host tools,
the documentation site, and the gateware lint and simulation. It skips only the bitstream, for
the Quartus reasons above.

This is what CI runs on every push, so it is also the answer to "will this pass?".

## Version stamping

Each component stamps the commit it was built from into its output: the capture application's
`--version` and About dialog, the FX3 firmware's USB product descriptor, and the bitstream's
provenance record.

A commit and nothing else — no release version anywhere, so all three parts of a Duplicator
report the same kind of thing and a bug report can quote three hashes side by side.

In a normal checkout this comes from `git` automatically, and a modified working tree is
marked — `af2511a5-dirty` — because a bare commit hash would name source that is not what
was built. Building from a tarball or inside a sandbox has no `git` to ask, so the value is
passed in:

```bash
cmake -B build/ddd-gui -S ddd-gui -DDDD_COMMIT=af2511a5
cmake -B build/fx3-firmware -S fx3/firmware -DFIRMWARE_VERSION=af2511a5 ...
```

Left unset with no `git` available, both fall back to `unknown` — which the release workflow
rejects, since a released binary that cannot be traced to a commit defeats the point of
building it in CI at all.

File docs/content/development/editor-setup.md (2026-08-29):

# Editor Setup

This project does not require an IDE, and no editor is privileged over any other. Everything
below is optional — the build works from a terminal with nothing but CMake and a compiler.

The reason this page exists is history. The FX3 sources arrived as an Eclipse CDT project,
the GUI as a Qt Creator qmake project, and the gateware as a Quartus GUI project. Each
brought its own build definition, each drifted from the real one, and each made contributing
conditional on installing a particular large application. All three are gone. What replaces
them is one mechanism that every modern editor already speaks: the Language Server Protocol.

## How it works, in one paragraph

Every CMake component sets `CMAKE_EXPORT_COMPILE_COMMANDS`, so configuring a build writes
`build/compile_commands.json` — the exact compiler invocation for every source file. Each
component also has a `.clangd` file pointing at that build directory. Start `clangd` in any
editor and you get completion, go-to-definition, find-references, inline diagnostics and
rename across the C and C++ in that component. Verilog gets the same treatment from
`verible-verilog-ls`. Both language servers come with the Nix dev shells, so there is nothing
to install per developer.

## Once, before anything else

Get the toolchain, then configure each component you intend to work on.

**Run all of this from the repository root.** The `nix develop` line would work from any
subdirectory — there is one `flake.nix`, at the root, and Nix walks up to find it — but the
`cmake` lines below use paths relative to the root, so the root is the one place every
command here is correct.

```bash
nix develop                      # everything free, across all components
cmake -B ddd-gui/build -S ddd-gui
cmake -B fx3/programmer/build -S fx3/programmer
cmake -B fx3/firmware/build -S fx3/firmware \
      -DCMAKE_TOOLCHAIN_FILE=../arm-none-eabi-toolchain.cmake
```

The configure step is what produces `compile_commands.json`.

!!! warning "Configure first"

    Until a component has been configured at least once, clangd has nothing to read and will
    report errors on every include. That is the single most common cause of "the language
    server does not work here".

Re-run configure after adding or removing a source file.

### With direnv

If you use [direnv](https://direnv.net/), `.envrc` in the repository root activates the
default shell automatically:

```bash
direnv allow
```

Editors launched from inside the directory then inherit the toolchain, which matters for
GUI editors that do not read your shell profile. To use a component shell instead, put
`use flake .#ddd-gui` in `.envrc.local`.

## Per-component notes

| Component | Language server | Notes |
| --- | --- | --- |
| `ddd-gui/` | clangd | Qt's moc output lands in the build tree; the compile database already includes those paths |
| `fx3/programmer/` | clangd | Nothing special — ordinary host C |
| `fx3/firmware/` | clangd | `.clangd` sets `Compiler: arm-none-eabi-gcc`. Without it clangd probes the *host* compiler for system headers and reports hundreds of false errors, because the firmware is freestanding and never sees the host libc |
| `fpga/` | verible-verilog-ls | `nix develop .#fpga` — free tools only, no Quartus needed to edit, lint or simulate |
| `docs/` | — | Markdown; any editor |
| `hardware/` | — | KiCad's own GUI. `nix develop .#hardware` |

## VS Code

Install two extensions:

- **clangd** (`llvm-vs-code-extensions.vscode-clangd`)
- **CMake Tools** (`ms-vscode.cmake-tools`)

Disable the C/C++ extension's IntelliSense if you have it installed — it and clangd fight
over the same files and produce contradictory diagnostics:

```json
{
  "C_Cpp.intelliSenseEngine": "disabled",
  "clangd.arguments": ["--background-index", "--clang-tidy"]
}
```

Open the *component* directory (`ddd-gui/`, `fx3/firmware/`) rather than the repository root, so
clangd finds the right `.clangd`. If you prefer a single window, use a multi-root workspace
with one folder per component.

Do not commit a `.vscode/` directory — it is gitignored at the root deliberately.

## Neovim

With the built-in LSP client and `nvim-lspconfig`:

```lua
require('lspconfig').clangd.setup {
  cmd = { 'clangd', '--background-index', '--clang-tidy' },
}

require('lspconfig').verible.setup {
  cmd = { 'verible-verilog-ls', '--rules_config_search' },
}
```

`clangd` locates the right configuration by walking up from the file being edited, so opening
a file anywhere in the tree works — there is no per-project setup beyond the above.

For Verilog, `verible-verilog-ls` is in the `fpga` shell. Start it with
`--rules_config_search` (as in the Neovim example below) and it finds
`fpga/.rules.verible_lint` by walking up from the file being edited, so the diagnostics in
your editor are the same ones the `fpga-style` CI check enforces. Formatting is
`./fpga/tests/run-format.sh`, not a bare `verible-verilog-format` — the settings live in
`fpga/.verible-format` and the script is what applies them.

## Emacs

With `eglot` (built in since Emacs 29):

```elisp
(add-hook 'c-mode-hook #'eglot-ensure)
(add-hook 'c++-mode-hook #'eglot-ensure)
(add-hook 'verilog-mode-hook #'eglot-ensure)

(with-eval-after-load 'eglot
  (add-to-list 'eglot-server-programs
               '(verilog-mode . ("verible-verilog-ls" "--rules_config_search"))))
```

`lsp-mode` works equally well; nothing in the repository depends on which you choose.

## Helix

Helix has an LSP client built in and needs no configuration for C and C++ — it looks for
`clangd` on `PATH`, which the dev shell provides. For Verilog, add to `languages.toml`:

```toml
[[language]]
name = "verilog"
language-servers = ["verible"]

[language-server.verible]
command = "verible-verilog-ls"
args = ["--rules_config_search"]
```

## Qt Creator

Qt Creator opens CMake projects natively. Use *File → Open File or Project* and select
`ddd-gui/CMakeLists.txt`.

Do **not** look for `.pro` files — the qmake project files were removed. They were a second
build definition maintained by hand alongside the CMake one, and they drifted. Qt Creator
loses nothing: it reads the CMake project directly, including the Qt-specific targets.

Its generated `*.user` files are gitignored.

## CLion and KDevelop

Both open `CMakeLists.txt` directly and manage their own build directory. Point them at the
component directory. Neither needs anything from this repository beyond the CMake project.

If CLion cannot find Qt or libusb, it is being launched outside the Nix shell — start it from
a terminal inside `nix develop`, or use direnv.

## Formatting

Formatting is enforced for the gateware and not for anything else, so the rules differ by
component. What exists:

- **`.editorconfig`** at the repository root, honoured by every editor listed above (VS Code
  and Emacs need a plugin; Neovim, Helix, CLion, KDevelop and Qt Creator support it natively).
  It sets indentation, line endings and trailing-whitespace behaviour per file type.
- **`verible-verilog-format`** for `fpga/`, and here formatting **is** enforced — the
  `fpga-style` check fails the build on a file that is not exactly what the formatter would
  produce. Run `./fpga/tests/run-format.sh` rather than the tool directly; the settings are
  in `fpga/.verible-format`. The gateware has already had its one-off reformat, so there is
  no history left to bury.
- **`clang-format`** ships in the dev shells. `ddd-gui/` has a `.clang-format` and gates on
  it; `fx3/` does not, so running it there would reformat against its default style. Do not
  run it across those files.

The rule that matters, everywhere except `fpga/`: **do not reformat code you are not
otherwise changing.** Whitespace-only diffs bury the actual change and break `git blame`.

Paths that must never be reformatted at all — vendored or generated — are listed in
[AGENTS.md](https://github.com/Domesday86/DomesdayDuplicator/blob/main/AGENTS.md) §3 and
marked `unset` in `.editorconfig` so a format-on-save cannot touch them.

## When the language server misbehaves

| Symptom | Cause |
| --- | --- |
| Every `#include` is red | The component has not been configured — no `compile_commands.json` yet |
| Only *some* files are broken | Those files were added after the last configure; re-run `cmake -B build` |
| Firmware sources show hundreds of libc errors | clangd is not using `fx3/firmware/.clangd`; you probably opened the repository root rather than the component |
| Qt headers not found | The editor was launched outside the Nix shell |
| Stale diagnostics after a rebuild | Clear clangd's index: `rm -rf .cache/clangd` |

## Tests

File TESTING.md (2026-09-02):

# TESTING.md

How the Domesday Duplicator is tested, what that covers today, and what it does not.

This document is deliberately honest about scope. This repository once had **no automated
tests at all**. There are now 1,421 across five
components, plus nine gateware testbenches, a lint pass over five Verilog modules, a static
check on the documentation site, and a licence-header check and an update-bundle check over
the whole tree. That is a
start, not a suite, and this document says so where it applies rather than describing an
aspiration as though it were a fact.

---

## 1. Why testing here is unusual

Most projects test one program on one machine. This one spans a PCB, an FPGA, a bare-metal
USB controller and a desktop application, connected by a wire protocol none of them can
verify alone. Three consequences shape everything below.

**A green build proves very little.** The firmware compiles for a processor the build machine
does not have. The gateware compiles for silicon that is not present. Neither has ever been
executed at the point CI goes green.

**The failure mode that matters is silent.** A capture device that crashes is a nuisance. A
capture device that *drops one sample in ten thousand* produces files that look fine, decode
fine, and are subtly wrong forever. Nothing in a unit test catches that.

**Some things can only be tested on hardware, and that is not a gap to be closed.** Mocking
libusb, DMA and GPIF to the fidelity needed to prove a capture path would produce a model
elaborate enough to have its own bugs. The honest answer is a documented manual procedure,
which is §5.

## 2. Test tiers

Every automated test carries exactly one tier as a CTest label.

| Tier | Label | Meaning | In CI |
| --- | --- | --- | --- |
| T1 | `unit` | Host-native, no I/O, no hardware, mocked dependencies. Milliseconds | Yes |
| T2 | `golden` | Host-native, output compared against committed reference data | Yes |
| T3 | `sim` | Gateware simulation (Verilator / Icarus Verilog) | Yes |
| T4 | `static` | Lint, format, ERC/DRC, link checks, licence-header checks | Yes |
| T5 | `hil` | Hardware-in-the-loop. Needs a real Domesday Duplicator | **No** — manual, gated on release |
| T5 | `hil-player` | Hardware-in-the-loop against a real **LaserDisc player** | **No** — manual, gated on release |

T5 never runs in CI and never runs unattended. Several of its steps write to non-volatile
memory on the device.

**Why the player has a label of its own.** They are two different pieces of hardware and
not every bench has both: a machine with a Duplicator and no player must not fail tests it
has no way to run. Each test still carries exactly one tier label, which keeps the rule
simple — the two are separate rows here rather than a single test wearing both.

One wrinkle worth knowing, because it is silent otherwise: CTest matches labels as an
unanchored regular expression, so `-L hil` selects `hil-player` too. The device tier alone
is `-L "^hil$"`. Exclusion needs no such care — `-LE hil` excludes both, which is what CI
and the Nix build do.

## 3. Running the tests

**From the repository root** — `nix flake check` itself works from any subdirectory, since
Nix walks up to the single root `flake.nix`, but the `cmake` paths below are relative to the
root:

```bash
nix flake check                      # everything, on a clean machine
```

Or per component, from a configured build tree:

```bash
cmake -B ddd-gui/build -S ddd-gui
cmake --build ddd-gui/build
ctest --test-dir ddd-gui/build                    # all tests
ctest --test-dir ddd-gui/build -L unit            # one tier
ctest --test-dir ddd-gui/build -LE hil            # everything except hardware
ctest --test-dir ddd-gui/build --output-on-failure
```

It also uses the `functional` label, which no other component does. Those are whole-pipeline
soak tests: a synthetic source generates the device's stream in software at its real
80 MB/s and pushes it through validation, metrics, the monitor tap and a sink for a minute,
with a consumer reading the tap as fast as it can. They are the strongest statement short of
T5 that the real-time design holds, and they are the reason `ctest -L unit` exists as the
everyday loop — the functional tier takes minutes where the rest takes seconds.

```bash
ctest --test-dir ddd-gui/build -L unit          # the everyday loop, ~5 seconds
ctest --test-dir ddd-gui/build -LE hil          # everything but the hardware tiers
ctest --test-dir ddd-gui/build -L "^hil$"       # the device tier, Duplicator attached
ctest --test-dir ddd-gui/build -L hil-player    # the player tier, player attached
DDD_SOAK_SECONDS=10 ctest --test-dir ddd-gui/build -L functional   # a shorter soak
```

The player tier takes its bench from the environment, so it does not have to scan every
serial port on the machine — which is a thing to avoid where the bench has other equipment
on it (see *Risks and safety* in the player control plan):

```bash
DDD_PLAYER_PORT=/dev/ttyUSB0 DDD_PLAYER_BAUD=9600 \
DDD_PLAYER_DISC_TYPE=cav DDD_PLAYER_LAST_FRAME=54321 \
  ctest --test-dir ddd-gui/build -L hil-player --output-on-failure
```

All four are optional and each buys something: the first two skip the scan, and the last
two turn the examination from a measurement into a comparison — without them it must
still complete and establish the disc's type and length, with them it must also get them
right. `DDD_PLAYER_MODEL_ID` checks the identity against the badge on the front panel.
**These tests spin the disc**, for about a minute, exactly as the application's own
**Examine** does.

Note the `-LE hil`: unlike every other component, `ddd-gui/` has a T5 tier that is a gtest
binary rather than a manual procedure, so a bare `ctest` here would try to talk to a device.
CI and the Nix build both exclude it explicitly.

`DDD_SOAK_SECONDS` sets each soak's duration, defaulting to 60. Whatever it ends up as is
printed in the test output, so a shortened run cannot be mistaken for a full one. The
FLAC-sink soak backs off and retries at half rate if the machine cannot sustain the
encoder, and says so in its output rather than passing quietly at a quarter speed.

**What the soak does not cover.** Everything past the host's memory: the USB stack, the
cable, the FX3 and the gateware. A pipeline that passes here can still lose samples to a
bad cable, which is why §5 exists and why passing this is not a substitute for it. The
`hil` tier reaches some of that — enough to tell a working device from a misbehaving one in
one command — but not the hour-long soak with a player attached that §5 describes.

Its build additionally runs clang-format and clang-tidy as gates, so a formatting or lint
regression fails the build before any test runs. That is deliberate — it is a new component
and can afford to be held to it from the first file — but it means the build needs those
tools present. `-DDDD_ENABLE_CLANG_FORMAT=OFF -DDDD_ENABLE_CLANG_TIDY=OFF` turns them off
where they are unavailable, which is what the Nix package does.

Tests are built by default. Pass `-DBUILD_TESTING=OFF` to skip them — the Nix packages do
this when `doCheck` is false.

The gateware has no CMake and so no `ctest`. Its checks are scripts, run either through the
flake or directly:

```bash
nix develop .#fpga -c ./fpga/tests/run-lint.sh     # T4
nix develop .#fpga -c ./fpga/tests/run-sim.sh      # T3
```

The licence-header check (§4.7) belongs to no component and needs no toolchain at all:

```bash
./tools/check-licence-headers.sh          # T4; -v also lists the unconverted files
```

## 4. What exists today

### 4.1 `ddd-gui/` — 1,785 tests (1,775 without hardware)

The capture application. Split by what a test needs rather than by what it
covers: `ddd_capture_tests` links no Qt at all, which is what makes the engine's Qt-free
rule enforceable — if the engine ever grows a Qt dependency, that binary stops linking.
`ddd_player_tests` links none either, for the same reason and with the same effect on the
LaserDisc player protocol.

| File | Covers | Tiers |
| --- | --- | --- |
| `tests/unit/test_logger.cpp` | The engine's logging seam: level filtering, the callback boundary | T1 |
| `tests/unit/test_log_options.cpp` | The names `--log-level` and `--log-out` accept: the four levels a record can carry, the wider vocabulary mapped onto them so a level named on another of the project's tools means the same thing here, `off` outranking every level there is, the three destinations round-tripping through their own names, an unknown name refused rather than defaulted, and the sink each destination resolves to — including the one that matters, `file` with no file named keeping the console rather than discarding the log | T1 |
| `tests/unit/test_spdlog_logger.cpp` | The console and file destinations, driven through the same seam the engine logs through: records reaching the file with their level beside them, everything below the level dropped, `off` leaving the file empty rather than absent, a message full of braces written verbatim rather than read as a format string, `console` leaving a named file uncreated, and a log file that cannot be opened reported in a sentence naming the path while the console carries on — because losing the log is not a reason to refuse to start | T1 |
| `tests/unit/test_log_format.cpp` | The figures a log line carries: a decimal separator that is a full stop whatever the machine's locale asks for, arithmetic nobody checked written as zero rather than as `nan`, sizes in binary units so a 256 MiB ring cannot read as 268 MB, and a duration in whichever of four forms carries meaning at that length — with the minutes and seconds of a clock padded, because "1 h 12 m 4 s" is three unrelated numbers | T1 |
| `tests/unit/test_fill_history.cpp` | How full a buffer got over a run: the mean and the peak, the readings at or above each of three levels — which is what tells a run that touched three quarters once from one that sat there — a level worked out from an occupancy against a capacity, a capacity of zero ignored rather than read as full, a reading off the end of the scale clamped rather than lost, and the sentence it produces stopping at the first level nothing reached rather than listing zeroes | T1 |
| `tests/gui/unit/test_platform_description.cpp` | The platform line every run opens with, built from facts a test chooses rather than from the machine it runs on: the system, the kernel — named on every platform, because on macOS the Darwin version is the one a kernel-level USB fault is filed against — the architecture and the Qt in use, with both Qt versions given only when the loaded one differs from the one built against, and "not known" rather than an empty line when nothing could be answered | T1 |
| `tests/unit/test_sample_format.cpp` | The device's wire layout: sample/counter packing, that the two agree with the byte-level constants the hot loop uses, that the sequence-counter period is odd so no whole number of USB packets can ever equal one — the arithmetic behind issue #186, asserted against the legacy block length that failed it — the `(v−512)×64` scaling ld-decode expects, capture file naming | T1 |
| `tests/unit/test_test_pattern_verifier.cpp` | The ramp check: intact ramps, both gateware ramp lengths discovered rather than assumed, breaks reported at their exact offset, a dropped sample caught, state carried across buffers | T1 |
| `tests/unit/test_sequence_validator.cpp` | Sequence-marker validation and the metrics that share its pass: lock-on within one counter period, mid-stream mismatch at the exact sample, a markerless legacy stream disabling checking rather than failing, the wrap at 62, both shipped block lengths accepted but only one of them per stream, a counter that outstays its block, a hole of exactly one legacy counter period caught because the current period is odd, marker stripping, clip counts, RMS — and a measurement that the whole pass fits inside the 26 ms real-time budget | T1 |
| `tests/unit/test_disk_buffer_ring.cpp` | The producer-to-consumer handoff: geometry rounding, overflow detection, fill-level accounting, a contended run of 4,000 slots checked serial-by-serial, and that an abort releases waiters on **both** sides | T1 |
| `tests/unit/test_monitor_tap.cpp` | The wait-free publishers: 200,000 stats publications against a hammering reader with no torn read, triple-buffered snapshots never seen half-written, a slow reader dropping snapshots rather than delaying the writer, and the writer's own publish cost measured with four readers hammering and with none | T1 |
| `tests/unit/test_capture_pipeline.cpp` | The orchestrator, and the account it keeps of itself: start/stop/abort, error latching precedence, injected faults surfacing as their own codes, a stalled source declared stalled rather than waited for, a sink attached mid-stream receiving whole buffers with no sample lost or repeated, the device's buffer readings reaching the statistics — counted once per reading however many times the same one is seen, and accumulated across the run as the device's own counters clear when they are read — and the published throughput: measured across a window rather than averaged over the run, so a paced source reads its true rate while the same snapshot's lifetime average is still a third below it, no figure published at all until a window has passed, and the last rate held once the capture stops rather than divided by a stopping time in which no buffer can arrive | T1 |
| `tests/unit/test_usb_device.cpp` | The SuperSpeed rule, device personalities — a device with no firmware never selected for capture even when it is the remembered preference, found when a caller asks for any personality, and a change of personality counting as a change of device — preferred-device selection, and the USB transfer layout: transfers a whole number of packets, dividing a buffer exactly, the queue capped at the usbfs limit — and a simulation walking the transfers through several laps of the ring to prove buffers are handed over in the order the consumer reads them | T1 |
| `tests/unit/test_firmware_version.cpp` | The firmware version comparison: commits parsed out of the USB product string, dirty builds on either side, stamps of differing length from one commit still matching, and an application that cannot name its own commit staying quiet | T1 |
| `tests/unit/test_fpga_telemetry.cpp` | The gateware's account of its capture buffer: a well-formed block read field by field, the all-zero reading of gateware without the instrument and the all-ones reading of a floating link both refused, a layout version this build does not know refused rather than misread, geometry that cannot be true refused before anything divides by it — and the scale itself, where a peak at the packet threshold is no back pressure at all, half the room above it is half the scale, and an interval that lost samples reads 100 whatever its peak was | T1 |
| `tests/unit/test_digest.cpp` | SHA-256 against the published FIPS 180-2 vectors and the million-character case, the streaming interface agreeing with the one-shot function at every chunk boundary, and hex parsing refusing anything but 64 hex characters | T1 |
| `tests/unit/test_json_value.cpp` | The manifest parser's strictness stated as tests: duplicate keys, trailing content, comments, trailing commas, leading zeros, unescaped control characters, lone surrogates and runaway nesting each refused by name — plus numbers surviving a round trip as the text they arrived as | T1 |
| `tests/unit/test_minisign_verify.cpp` | Signature verification against signatures **minisign 0.12 produced**, in both its modes: a manifest with one byte changed refused, an edited trusted comment refused because the second signature covers it, a signature from another key refused, and malformed key and signature files refused | T1 |
| `tests/unit/test_update_manifest.cpp` | The manifest schema: the fixture read field by field and written back byte-identically, a one-component bundle accepted and an empty one refused, an unknown schema version stopping the parse rather than producing a list, every problem reported rather than only the first, dotted versions ordered while commit hashes and `unknown` are refused an ordering at all — and the provisioning component: a set read and written back under its own name, a set carrying only vectors accepted as a manifest, and a component kind this build does not know refused by name rather than silently skipped | T1 |
| `tests/unit/test_update_bundle.cpp` | The archive: entries round-tripped through the writer and reader including the empty, exactly-one-block and one-byte-over cases; directories, paths, bad checksums, truncation and duplicate names refused; and, at bundle level, a tampered manifest, a tampered payload, a wrong length, a missing payload, a missing signature and a manifest that is not the first entry each refused with their own message — plus a signed bundle carrying all four payloads opened and its vectors checked against the manifest's digest like any other payload, and refused when one byte of them changes | T1 |
| `tests/golden/test_stock_tar_bundle.cpp` | A bundle **as `tools/make-update-bundle.sh` really produced it** — GNU tar's bytes, minisign's signature — opened, verified and compared against what this project's own writer produces. The one test that says the reader reads what the release tooling writes rather than only what this code writes | T1, T2 |
| `tests/unit/test_update_key.cpp` | Which signatures a build accepts: a development bundle accepted with the explicit opt-in and refused without it, a bundle whose claimed channel and signing key disagree refused, the compiled-in development key checked against the one in `tools/keys/`, and the default policy proved able to open something at all | T1 |
| `tests/unit/test_boot_image.cpp` | The FX3 boot image, read from the host's side: a well-formed image parsed into its sections with the offsets landing on the right bytes, and every malformed case refused with a sentence — a missing signature, an image that is not executable code, a type the boot ROM would not run, a checksum that does not match, a truncated file, bytes after the checksum, an image with nothing in it, and a section length that would wrap when multiplied into a byte count | T1 |
| `tests/unit/test_device_recovery.cpp` | Programming a device that has no firmware to be programmed with: the prelude downloading each section and starting it, the downloaded bytes proved to be the image's own, the updater opened at the path the device *came back* at rather than the one it left, and then the ordinary update running unchanged — plus every way the prelude can fail, all of which are things that happen to a device nobody is holding: a bundle with no firmware in it, a payload that is not an image, a download stopping part way, a device that will not start what it was given, one that never comes back, and a cancellation, each proved to leave nothing written | T1 |
| `tests/unit/test_device_updater.cpp` | The status packet: every field decoded at its offset, the three counters proved not interchangeable, the wrong length refused, a phase or error code this build does not know refused rather than narrated — and that every error code has its own sentence, none of them repeating another's | T1 |
| `tests/unit/test_update_gate.cpp` | The install-time gate: a bundle needing a newer application refused with that verdict rather than a generic one, an unknown manifest schema refused, firmware or gateware speaking a version outside this build's range refused in both directions, a downgrade inside the range allowed, a build that cannot order its own version saying so rather than assuming, the gateware floor not applied to a device whose FPGA never answered, a device with no firmware passing the checks that need an identity while being refused a bundle that carries no firmware to give it, and a file carrying only the bring-up payloads refused by the update window with a sentence naming the window that does want it | T1 |
| `tests/unit/test_update_orchestrator.cpp` | The whole flow against a fake device, and the account it keeps of itself — what the file carried, the chunk size the device negotiated, what each component cost, and, at a failure, the device's own status at the moment it stopped: an install proved by reading the identity back, every chunk but the last page-aligned, the chunk size taken from the device and rounded down to whole pages, the stages reported in order, transfer progress monotonic and reaching its total — and each failure branch by name: no update agent, a capture running, a payload that is not firmware, a stream digest mismatch, a readback mismatch, a device that stops answering, one that never returns, one that comes back running the wrong build, and a cancellation proved to leave nothing committed — plus the deferred restart the bring-up flow uses, where the write and the readback happen and the reset, the FPGA reload and the confirmation deliberately do not, and the ordinary path proved to still do all three | T1 |
| `tests/unit/test_update_cli.cpp` | `ddd-update`'s command line and its exit codes: each option parsed, `--device` with nothing after it refused, two bundles refused, and a missing file reported as a bundle error before any device is touched | T1 |
| `tests/unit/test_usb_blaster_cable.cpp` | The USB-Blaster's wire protocol, against a fake byte pipe: a TCK cycle as the same pin state twice with the clock raised, TDO asked for on the half of the cycle before the edge, eight TMS-low cycles collapsing into one byte-shift command, the last bit of a scan dropping back to bit-bang because it raises TMS, a long run split at the largest command, a wait clocked as whole bytes with the remainder bit-banged and nothing ever asked back, commands held until something needs the cable to have caught up, the two status bytes on every packet dropped rather than read as data, and a cable that only ever answers status given up on rather than waited for | T1 |
| `tests/unit/test_svf_player.cpp` | The programming file and the TAP state machine it walks: the run forced to a known state, a scan's whole cycle stream — the walk there, TMS raised on the last bit and nowhere else, the walk to the state the file says scans end in — answers compared under their mask and a mismatch naming the line and both values, what a statement remembers and what it deliberately does not, waits counted and left where their end state says, a wait taking at least as long as the count stands for at the rate the file declares, and the files this player refuses rather than half-understands: a chain with more than one device on it, a drive of a reset line the cable does not have, a value wider than its scan, a statement it does not know. Fixtures include a real Quartus-emitted file played against a device that agrees with it and one that does not | T1 |
| `tests/unit/test_bringup_orchestrator.cpp` | Bringing a board up — including what it records of each JTAG attempt and of the order the three writes happen in — and the one property here that protects hardware rather than data: **the FPGA is refused until the FX3 has been programmed** — before the cable is so much as opened — whatever calls it and in whatever order, including after an FX3 step that failed. Plus both halves run in order against fakes, the deferred restart the fitted jumper requires, a set with no firmware and a set with no vectors each refused, the cable driver's own sentence carried through rather than replaced, a stopped play reported as stopped rather than failed, and progress reported in the shape the update page already consumes | T1 |
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

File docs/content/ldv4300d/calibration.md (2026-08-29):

# LDV4300D Calibration

# Preface
This article covers the mechanical calibration of the Pioneer LD-V4300D LaserDisc player based on the service manual and including a wealth of additional material and information.  Note that this article does not cover the electrical calibration steps (page 119 of the original service manual) – only the mechanical calibration.

The Pioneer LD-V4400 is an NTSC only variant of the LD-V4300D (they are the same players with different power supplies and firmware). Therefore these calibration instructions are suitable for the LD-V4400 too - as the calibration disc is NTSC, the procedure is exactly the same.

There is, of course, no guarantee that the calibration steps suggested here are correct.  You should note that attempting to calibrate a LaserDisc player can not only cause the player to stop functioning, it can also damage the player (and even you, since the 240V/110V voltages in the exposed power supply are potentially deadly).  Proceed with calibration **at your own risk** and ensure you have studied the details of each step (and understood the requirements) before attempting on a player.  If you are unsure, don’t have the required equipment or don’t have the required electronics skills – **do not attempt to calibrate your player**.

The laser in a LaserDisc player produces an intense but invisible beam of infrared light. Under no circumstances should you stare directly into the lens of the player whilst it is powered up. Always ensure the test disc is in place when the player is powered up and avoid standing over the player looking directly down at it. Please ensure you study the dangers of working with lasers before attempting to open a LaserDisc player or attempting calibration.

# Introduction
## Required materials
In order to calibrate the player the following items are required (in addition you will need an ESD safe work-space and access to standard tools such as screwdrivers, hex-wrenches etc.):

* Dual-channel Digital Storage Oscilloscope (DSO) with at least 20MHz of bandwidth
* Arbitrary Waveform Generator (AWG) capable of generating a 4KHz sinewave
* A Pioneer GGV1069 NTSC 8" calibration and test disc
* Pioneer CU-V113A LaserDisc IR remote control
* RM Series RMC12010 3rd-party Pioneer service IR remote
* Either a calibration breakout board (see below) or the required test-header connecting cables and components (100K resistor and 1uF unpolarised capacitor)
* A monitor/TV capable of displaying NTSC video along with the required interconnecting cables for video and audio

Nearly all calibration steps require connection between the player and an oscilloscope (some steps require connection to both the DSO and AWG). In addition, some steps also require simple filtering components in the measurement path. To make these steps easier there is a calibration board design [available on Github](https://github.com/Domesday86/LD-V4300D-Service-Adaptor) including the required Gerber files for PCB production. The following schematic shows the contents of the board:



_LD-V4300D Service Adaptor schematic_

The following picture shows the calibration board attached to the correct header of the player:



_The calibration board attached to the correct test header_

## Disassembly of the player
To disassemble the player ready for calibration first remove the two screws located on the back of the player:



_Remove the two case screws located on the back of the player_

Next remove the 6 screws at the sides of the case (3 on each side) as shown in the following picture:



_Side case screws_

Once the screws are removed, take off the top cover by prying it gently from both sides at the back, then lift the back of the case pivoting on the front. Once lifted, remove the top case by lifting it out towards the back of the player.

Now flip the player over onto it's top and remove the 6 screws holding in the bottom case plate as shown in the following picture:



_Removing the bottom case plate_

Once the screws are removed the plate should lift easily off the player.

Next flip the player back over, power up and eject the disc tray (be very careful of the live power supply when operating the player without a case!). Once the tray is ejected remove the three screws and the plastic plunger indicated in the following picture:



_Removing the disc tray_

Once the screws are removed take the metal mounting brackets completely out of the player. Then pull the disc tray gently to remove it completely from the player.

## Verifying the lens condition
The lens of the player should be clean and scratch free and should be checked before calibration (if the lens is damaged, calibration will not be possible). Check the lens by examining it under a microscope or using a strong magnifying glass. A clean undamaged lens is shown in the following picture:



_A clean, undamaged lens_

If there are any scratches visible on the lens surface the lens will required replacement before calibration. Although calibration may be possible, a damaged lens will severely effect the player's noise levels causing poor playback. The following picture shows an example of a lens which has been damaged by spinning debris during use:



_A damaged lens_

## Inserting the test disc
As the is no disc tray during calibration it is necessary to insert the test disc (GGV1069) by hand.

Insert the disc from the back of the player as shown in the following picture whilst being careful not to touch the disc's surface on the mechanics of the player:



_Inserting the test disc into the player_

Once the disc is in place on the player's spindle push up the two white levers to clamp the disc in place as shown in the following picture:



_Clamping the disc in place_

Once clamped, the disc should be able to rotate freely on the spindle. Note that, when the player is first power up (with the disc tray removed) the player will think that the tray is ejected and attempt to load the tray. This should be stopped by briefly pressing the tray closed microswitch at the back-right of the player (under the external sync board).

## Placing the player in test mode
To place the player in test mode power up the player as normal, then press the ESS button (on the RMC12010 remote) followed by the TEST button. This will place the player in test mode. Pressing TEST once more will place the player in diagnostic mode. Pressing the DISPLAY button twice on the player's front-panel will return the player to normal playback mode. It is also possible to enter test mode by holding DISPLAY on power up or by using a jumper on the main processor board of the player - since the remote can be used it is recommended to use it instead of the other methods.

## Lifting the player during calibration
Many of the adjustments require you to access the underside of the player to reach the adjustment screws and potentiometers.  When the player is horizontal on the workbench lift from the left side of the player so the power supply (on the right) is on the bench when the left side is raised.  This lowers the chances of you putting your fingers into the live power supply during calibration.  Putting your fingers inside the power supply during testing will lead to a very quick end to your adventures in player maintenance and repair.  **Be very careful of the power supply at all times**.

It is also possible to lift the player by simply suspending it between two boxes; this reduces the need to lift the player during calibration.

## Location of calibration potentiometers
There are 9 calibration potentiometers located on the FTSB module which are required for the mechanical calibration. The potentiometers are numbered from 1-9. The location of the potentiometers is shown in the following picture:



_FTSB Module calibration points_

The functions of the calibration potentiometers are as follows:

* VR1 – RF Gain
* VR2 – Tracking Balance
* VR3 – Tracking Gain
* VR4 – Tilt Offset
* VR5 – Focus Gain
* VR6 – Focus Balance (maximum)
* VR7 – Focus Balance (normal)
* VR8 – Tilt Gain
* VR9 – Tilt Balance

The potentiometers are generally fixed in place (at the factory) by heating a small point on the side of the potentiometer. In order to adjust you will need to use a small sharp knife to ensure the rotational part of the potentiometer is free of the base. Carefully slice across the melted point until the knife slides slightly under the top (black) part of the potentiometer. Once freed you can use the melted spot as a marker to place the potentiometer back to it's factory set position before beginning calibration.

# Calibration steps
**READ THIS FIRST**: If you are not experienced in calibrating LaserDisc players it is recommended that you first read through every step paying close attention to any warnings. Then dry-run the calibration steps by performing all of the measurements (and ensuring you understand how to take them) before finally running through the calibration and making adjustments. It is very easy to damage a player due to poor attempts at calibration.

**READ THIS SECOND**: Before attempting calibration ensure that the lens of the LaserDisc player is clean and unscratched. The lens should be carefully examined (preferably using a good microscope) and then cleaned with optical lens cleaning material such as 'OpticPrep' - absolutely **DO NOT** use materials such as cotton buds or any type of Q-Tip - you **WILL** damage the lens.

## Step 1 - Tilt gain adjustment
Note: All calibration steps should be performed with the test disc in place and the player in test mode unless otherwise noted.

### Purpose
The tilt sensor is a small photodiode located to the right of the lens which detects the proximity of the assembly to the LaserDisc. When manufactured the tilt sensor is given a 'gain rank' indicated by a coloured dot on the tilt sensor PCB as shown in the following picture:



_Tilt gain dot location_

The presence and colour of the dot indicates the rank of the sensor.

### Procedure
Move the optical deck from under the test disc using the SCAN FWDs button on the RMC12010 until the tilt sensor is visible (note it is also possible to simply move the deck by hand - do this from the left-hand side of the deck without touching the lens or tilt sensor).

Note the colour of the dot located on the tilt sensor as shown above.

Lift the player onto it's side and adjust VR9 to its mechanical centre (simply swing the potentiometer both ways and then put it in the centre of the two extremes).

If the sensor has a red dot, turn VR8 fully clockwise. If the sensor has a blue dot turn VR8 fully anti-clockwise. If the sensor has no dot, turn VR8 to it's mechanical centre point.

## Grating temporary adjustment
### Purpose
The laser diffraction grating is an optical component responsible for splitting the laser beam and must be correctly aligned to ensure the laser output (at the lens) is correct. Incorrect setting can cause playback to be impossible or can make the player jump tracks randomly during playback.

**CAUTION**: This adjustment will make all other adjustments incorrect - if you alter the grating you will need to perform a compete calibration. If you are inexperienced at calibration **avoid** this step unless all other calibration steps fail to bring your player to an acceptable performance level. Generally the fine adjustment of the grating (later in the process) will be enough to fully correct this setting and course adjustment is not necessary.

The adjustment of the laser grating is rotational and is adjusted using a small V shaped lever on the optical assembly as shown in the following picture (the red line shows the neutral point of the adjustment):



_Grating adjustment screw_

The only way to examine the adjustment point (if you would like to see the alignment before making any adjustments) is to remove the optical assembly from the player (see the service manual for details of how to do this) - this is not required for calibration however.

**CAUTION**: If you haven't performed this calibration step before it is recommended to remove the optical deck and get a good look at the calibration point before reassembling and adjusting. It can be very difficult to get a 'feel' for the adjustment without making yourself very familiar with the construction and shape of the adjustment point. If in doubt, skip this calibration step.

Note that this adjustment can effect the pick-up tracking calibration (see below) - so, if the calibration is very inaccurate, it may take several back-and-forth adjustments between these steps to achieve a satisfactory result.
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

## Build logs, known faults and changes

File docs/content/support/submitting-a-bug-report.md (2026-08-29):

# Submitting a bug report

If you find a bug in the capture application please use the Github issue reporting tool available from [this link](https://github.com/Domesday86/DomesdayDuplicator/issues).

## What to include

A log is worth more than a description, and the application will write one for you. Start it
from a terminal with:

```bash
ddd-gui --log-level debug --log-file ddd.log
```

then make the fault happen and attach `ddd.log` to the report. It opens with the build and
the platform it ran on, and carries the application's own account of what it did — a
capture's throughput and buffer levels, or every step of a firmware update or a board
bring-up, whichever went wrong. [Command line](../capture-gui/command-line.md) describes
both switches and what each level records.

Without a log, the two things always worth quoting are the commit from **Help ▸ About** and
the contents of the Log panel (**View ▸ Panels ▸ Log**) — select the records there and
press **Ctrl+C**, or right-click ▸ **Copy**, to paste them into the report.

If you'd like to request new features please use the Github issue reporting tool and describe clearly your requirements and, if possible, the justification for inclusion.

If you'd like to support the development of this application you are welcome to contribute code via Github, or simply make a [donation](donations.md).

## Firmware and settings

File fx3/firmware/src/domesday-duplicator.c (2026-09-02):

/************************************************************************

    domesdayDuplicator.c

    FX3 Firmware main functions
    DomesdayDuplicator - LaserDisc RF sampler
    SPDX-FileCopyrightText: 2018-2025 Simon Inns
    SPDX-License-Identifier: GPL-3.0-or-later

************************************************************************/

// External includes
#include "cyu3system.h"
#include "cyu3os.h"
#include "cyu3dma.h"
#include "cyu3error.h"
#include "cyu3usb.h"
#include "cyu3uart.h"
#include "cyu3gpio.h"
#include "cyu3utils.h"
#include "cyu3pib.h"
#include "cyu3gpif.h"

// Local includes
#include "domesday-duplicator.h"
#include "domesday-duplicator-gpif.h"
#include "fpga-registers.h"
#include "update-agent.h"

// Global definitions
CyU3PThread glAppThread; // Application thread structure
CyU3PDmaMultiChannel glDmaMultiChHandle; // DMA multi-channel handle

CyBool_t glIsApplnActive = CyFalse; // Application active/ready flag
CyBool_t glForceLinkU2 = CyFalse; // Force U2 flag

// Set once the USB descriptors are registered and the initial connection has been made.
// VBus events can arrive as soon as the event callback is registered, which is before the
// descriptors exist; acting on one then would connect the device with nothing to enumerate.
CyBool_t glUsbInitComplete = CyFalse;

volatile CyBool_t input0Flag = CyFalse; // Input 0 set flag
volatile CyBool_t input1Flag = CyFalse; // Input 1 set flag
volatile CyBool_t input2Flag = CyFalse; // Input 2 set flag
volatile CyBool_t input3Flag = CyFalse; // Input 3 set flag

CyBool_t input0HandledFlag = CyFalse; // Input 0 set condition handled flag
CyBool_t input1HandledFlag = CyFalse; // Input 1 set condition handled flag
CyBool_t input2HandledFlag = CyFalse; // Input 2 set condition handled flag
CyBool_t input3HandledFlag = CyFalse; // Input 3 set condition handled flag

volatile CyBool_t dataCollectionFlag = CyFalse; // Flag to show if the host application is collecting data

// Staging buffer for register reads on their way to the host.
//
// Aligned because CyU3PUsbSendEP0Data hands the buffer to the DMA engine, which needs it
// on a 32-byte boundary. Statically allocated rather than living on the setup callback's
// stack for the same reason - and because that stack belongs to the USB driver.
static uint8_t glRegisterBuffer[FPGA_REGISTER_READ_MAX] __attribute__ ((aligned (32)));

// Staging for the update requests' data stages, aligned for the same reason.
//
// One buffer for the largest UPDATE_DATA chunk and one for the fixed-size
// UPDATE_BEGIN and UPDATE_STATUS packets. Static rather than on the setup
// callback's stack because two kilobytes does not belong on a stack that
// belongs to the USB driver.
static uint8_t glUpdateChunkBuffer[UPDATE_MAX_CHUNK] __attribute__ ((aligned (32)));
static uint8_t glUpdatePacketBuffer[UPDATE_BEGIN_LENGTH] __attribute__ ((aligned (32)));

// Main application function
int main(void)
{
    CyU3PIoMatrixConfig_t io_cfg;
    CyU3PPibClock_t pibClock;
    CyU3PGpioClock_t gpioClock;
    CyU3PGpioSimpleConfig_t gpioConfig;
    CyU3PReturnStatus_t status = CY_U3P_SUCCESS;

    // Perform initial clock configuration of the FX3
    CyU3PSysClockConfig_t clockConfig;
    clockConfig.setSysClk400  = CyTrue; // True = 403.2 MHz, false = 384 MHz
    clockConfig.cpuClkDiv     = 2;
    clockConfig.dmaClkDiv     = 2;
    clockConfig.mmioClkDiv    = 2;
    clockConfig.useStandbyClk = CyFalse;
    clockConfig.clkSrc        = CY_U3P_SYS_CLK;
    status = CyU3PDeviceInit(&clockConfig);
    if (status != CY_U3P_SUCCESS) {
        goto handleFatalError;
    }

    // Initialise the state of the caches - Icache, Dcache, DMAcache
    status = CyU3PDeviceCacheControl(CyTrue, CyFalse, CyFalse);
    if (status != CY_U3P_SUCCESS) {
        goto handleFatalError;
    }

    // Initialise the IO matrix
    //
    // I2C is enabled because the firmware is its own flasher: the FX3 boots from an I2C
    // EEPROM and the update agent rewrites it in place. The I2C lines are dedicated on
    // this device - the SDK is explicit that they are not multiplexed and are available
    // in every configuration except when claimed as GPIOs - so turning them on costs the
    // GPIF bus and the UART nothing, and lppMode below is unchanged.
    io_cfg.isDQ32Bit = CyFalse; // Data bus is 16-bits
    io_cfg.useUart   = CyTrue;
    io_cfg.useI2C    = CyTrue;
    io_cfg.useI2S    = CyFalse;
    io_cfg.useSpi    = CyFalse;
    io_cfg.lppMode   = CY_U3P_IO_MATRIX_LPP_UART_ONLY; // 16-bit data bus with UART

    // Note:
    // If io_cfg.isDQ32Bit = CyFalse then GPIO[0:15] and CTL[0:4] will be reserved for GPIF
    io_cfg.gpioSimpleEn[0] = 0;	// Most significant GPIOs 32-63
    io_cfg.gpioSimpleEn[1] = 0; // Least significant GPIOs 0-31
    io_cfg.gpioComplexEn[0] = 0;
    io_cfg.gpioComplexEn[1] = 0;

    status = CyU3PDeviceConfigureIOMatrix(&io_cfg);
    if (status != CY_U3P_SUCCESS) {
        goto handleFatalError;
    }

    // Start GPIF clocks, they need to be running before we attach a DMA channel to GPIF
	pibClock.clkDiv = 4; // 403.2 / 4 = 100.8 MHz
	pibClock.clkSrc = CY_U3P_SYS_CLK;
	pibClock.isHalfDiv = CyFalse;
	pibClock.isDllEnable = CyFalse; // Disable Dll (not required for synchronous applications)
	status = CyU3PPibInit(CyTrue, &pibClock);
	if (status != CY_U3P_SUCCESS) {
		goto handleFatalError;
	}

    // Initialise the GPIO module clocks, needed for nRESET towards FPGA
	gpioClock.fastClkDiv = 2;
	gpioClock.slowClkDiv = 0;
	gpioClock.simpleDiv = CY_U3P_GPIO_SIMPLE_DIV_BY_2;
	gpioClock.clkSrc = CY_U3P_SYS_CLK;
	gpioClock.halfDiv = 0;

	// Initialise the GPIO and set the callback function (for GPIO interrupts)
	status = CyU3PGpioInit(&gpioClock, gpioInterruptCallback);
	if (status != CY_U3P_SUCCESS) {
		goto handleFatalError;
	}

	// Claim GPIO19 from the GPIF Interface (collectData signal)
	status = CyU3PDeviceGpioOverride(19, CyTrue);
	if (status != CY_U3P_SUCCESS) {
		goto handleFatalError;
	}

	// Put the FPGA in not collectData by driving GPIO19 low
	CyU3PMemSet((uint8_t *)&gpioConfig, 0, sizeof(gpioConfig));
	gpioConfig.outValue = CyFalse;
	gpioConfig.driveLowEn = CyTrue;
	gpioConfig.driveHighEn = CyTrue;
	status = CyU3PGpioSetSimpleConfig(19, &gpioConfig);
	if (status != CY_U3P_SUCCESS) {
		goto handleFatalError;
	}

	// Claim GPIO27 from the GPIF Interface (nRESET signal)
	status = CyU3PDeviceGpioOverride(27, CyTrue);
	if (status != CY_U3P_SUCCESS) {
		goto handleFatalError;
	}

	// Bring the FPGA out of reset by driving nRESET/GPIO27 high
	CyU3PMemSet((uint8_t *)&gpioConfig, 0, sizeof(gpioConfig));
	gpioConfig.outValue = CyTrue;
	gpioConfig.driveLowEn = CyTrue;
	gpioConfig.driveHighEn = CyTrue;
	status = CyU3PGpioSetSimpleConfig(27, &gpioConfig);
	if (status != CY_U3P_SUCCESS) {
		goto handleFatalError;
	}

	// Generic input signals from FPGA (GPIO 20, 21, 28 and 29) -------------------------------------------------------

	// Claim GPIO20 from the GPIF Interface (input0)
	status = CyU3PDeviceGpioOverride(20, CyTrue);
	if (status != CY_U3P_SUCCESS) {
		goto handleFatalError;
	}

	// Configure as input
	CyU3PMemSet((uint8_t *)&gpioConfig, 0, sizeof(gpioConfig));
	gpioConfig.outValue = CyTrue;
	gpioConfig.driveLowEn = CyFalse;
	gpioConfig.driveHighEn = CyFalse;
	gpioConfig.inputEn = CyTrue;
	gpioConfig.intrMode = CY_U3P_GPIO_INTR_POS_EDGE;

	status = CyU3PGpioSetSimpleConfig(20, &gpioConfig);
	if (status != CY_U3P_SUCCESS) {
		goto handleFatalError;
	}

	// Claim GPIO21 from the GPIF Interface (input1)
	status = CyU3PDeviceGpioOverride(21, CyTrue);
	if (status != CY_U3P_SUCCESS) {
		goto handleFatalError;
	}

	// Configure as input
	CyU3PMemSet((uint8_t *)&gpioConfig, 0, sizeof(gpioConfig));
	gpioConfig.outValue = CyTrue;
	gpioConfig.driveLowEn = CyFalse;
	gpioConfig.driveHighEn = CyFalse;
	gpioConfig.inputEn = CyTrue;
	gpioConfig.intrMode = CY_U3P_GPIO_INTR_POS_EDGE;

	status = CyU3PGpioSetSimpleConfig(21, &gpioConfig);
	if (status != CY_U3P_SUCCESS) {
		goto handleFatalError;
	}

	// Claim GPIO28 from the GPIF Interface (input2)
	status = CyU3PDeviceGpioOverride(28, CyTrue);
	if (status != CY_U3P_SUCCESS) {
		goto handleFatalError;
	}

	// Configure as input
	CyU3PMemSet((uint8_t *)&gpioConfig, 0, sizeof(gpioConfig));
	gpioConfig.outValue = CyTrue;
	gpioConfig.driveLowEn = CyFalse;
	gpioConfig.driveHighEn = CyFalse;
	gpioConfig.inputEn = CyTrue;
	gpioConfig.intrMode = CY_U3P_GPIO_INTR_POS_EDGE;

	status = CyU3PGpioSetSimpleConfig(28, &gpioConfig);
	if (status != CY_U3P_SUCCESS) {
		goto handleFatalError;
	}

	// Claim GPIO29 from the GPIF Interface (input3)
	status = CyU3PDeviceGpioOverride(29, CyTrue);
	if (status != CY_U3P_SUCCESS) {
		goto handleFatalError;
	}

	// Configure as input
	CyU3PMemSet((uint8_t *)&gpioConfig, 0, sizeof(gpioConfig));
	gpioConfig.outValue = CyTrue;
	gpioConfig.driveLowEn = CyFalse;
	gpioConfig.driveHighEn = CyFalse;
	gpioConfig.inputEn = CyTrue;
	gpioConfig.intrMode = CY_U3P_GPIO_INTR_POS_EDGE;

	status = CyU3PGpioSetSimpleConfig(29, &gpioConfig);
	if (status != CY_U3P_SUCCESS) {
		goto handleFatalError;
	}

	// SPI register interface to the FPGA (GPIO 22, 23, 24 and 25), and the ---------------------------------------------
	// one line left over from the configuration signals it replaces (GPIO 26)
	//
	// GPIO 22 to 26 used to be five one-bit configuration outputs, of which
	// only test mode was ever used. They now carry a register bank instead —
	// see fpga-registers.h and the "FPGA register interface" documentation page.
	status = fpgaRegistersInitialise();
	if (status != CY_U3P_SUCCESS) {
		goto handleFatalError;
	}

    // Initialise the RTOS kernel -------------------------------------------------------------------------------------
    CyU3PKernelEntry();

    return 0;

handleFatalError:

    // An unrecoverable error has occurred
	// Loop forever
	while(1);
}

// Function to initialise the application's main thread
void domDupThreadInitialise(uint32_t input)
{
    CyU3PReturnStatus_t status;
    CyU3PUsbLinkPowerMode powerState;
    uint32_t linkRecoveryAttempts;

    // What the status LEDs are currently showing, so that they are only
    // written when the answer changes. 0x00 is not one of the patterns the
    // firmware ever sets, so the first pass through the loop always writes.
    uint8_t ledPattern = 0;
    uint8_t ledPatternShown = 0;

    // Loops since the last look for an FPGA that was not there at start-up
    uint32_t fpgaRecheckCount = 0;

    // Initialise the debug console
    domDupDebugInit();
    CyU3PDebugPrint(1, "\r\nDomesday Duplicator FX3 Firmware - Build 0062\r\n");
    CyU3PDebugPrint(1, "(c)2018 Simon Inns - https://www.domesday86.com\r\n\r\n");
    CyU3PDebugPrint(1, "domDupThreadInitialise(): Debug console initialised\r\n");

    // The register interface has to be usable before the USB setup callback
    // can answer a request that reaches it, which is any time after the
    // application below is initialised.
    status = fpgaRegistersStart();
    if (status != CY_U3P_SUCCESS) {
        CyU3PDebugPrint(4, "domDupThreadInitialise(): fpgaRegistersStart failed, Error code = %d\r\n", status);
    }

    // Look for the FPGA's register bank and report what it says it is.
    //
    // Deliberately before the application is initialised, so the gateware
    // version reaches the console whether or not a host ever connects, and on
    // the application thread rather than in a callback, because it retries
    // for as long as the FPGA might still be loading from EPCS.
    //
    // This identity read is also what the gateware's remote-update watchdog will
    // be tickled by once the factory/application split exists: the application
    // image tickles the watchdog when its SPI register interface decodes a first
    // valid transaction, and this read is that transaction. It happens within a
    // second of power-up whether or not a host is attached, which is the property
    // the watchdog policy depends on.
    fpgaRegistersProbe(FPGA_STARTUP_PROBE_ATTEMPTS);

    // Bring up the I2C block so the firmware can rewrite its own boot EEPROM.
    //
    // After the kernel is running, because CyU3PI2cInit() allocates. A failure
    // here is not fatal - the device enumerates and captures normally, and the
    // only thing lost is the ability to update itself, which the host is told
    // about explicitly rather than by a device that answers nothing.
    status = updateAgentStart();
    if (status != CY_U3P_SUCCESS) {
        CyU3PDebugPrint(4, "domDupThreadInitialise(): updateAgentStart failed, Error code = %d; "
            "device updates unavailable\r\n", status);
    }

    // Initialise the application
    domDupInitialiseApplication();

    // Main application thread loop
    while(1) {
        // The readback half of an update, handed here by UPDATE_FINISH.
        //
        // It runs on this thread rather than in the setup callback because it
        // reads the whole written region back off the EEPROM, which takes tens of
        // seconds - far longer than a control request may take to answer. The host
        // watches it through UPDATE_STATUS, whose verified counter this advances,
        // and nothing else in this loop runs while it does. That is deliberate:
        // the capture path is stopped by state for the duration of an update, so
        // there is nothing else here worth doing.
        if (updateAgentVerifyPending()) {
            if (fpgaRegistersPresent()) fpgaRegistersSetLeds(FPGA_LED_UPDATING);
            updateAgentVerify();
            ledPatternShown = 0;
        }

        if (glForceLinkU2) {
            // The host has placed the function in suspend via SET_FEATURE(FUNCTION_SUSPEND),
            // so hold the USB 3.0 link in U2 for as long as that condition lasts.
        	status = CyU3PUsbGetLinkPowerState(&powerState);
            while ((glForceLinkU2) && (status == CY_U3P_SUCCESS) && (powerState == CyU3PUsbLPM_U0)) {
                // Try to get to U2 state
                CyU3PUsbSetLinkPowerState(CyU3PUsbLPM_U2);
                CyU3PThreadSleep(5);
                status = CyU3PUsbGetLinkPowerState(&powerState);
            }
        } else if (glIsApplnActive && (CyU3PUsbGetSpeed() == CY_U3P_SUPER_SPEED)) {
            // Recover the link to U0 if the host has left it in U1 or U2 while the capture
            // path is up. The DMA hardware normally does this by itself when it has a packet
            // to send, so this is a backstop rather than the primary mechanism.
            //
            // U3 is deliberately excluded, and that exclusion is the point of this block.
            // U3 is host-directed suspend, and the only way a device may leave U3 is by
            // signalling remote wakeup - so firmware that pulls the link out of U3 wakes the
            // host up again the instant it tries to sleep. Requesting U0 from U1/U2 is
            // ordinary link management; requesting it from U3 is not.
            //
            // The attempt count bounds the loop. Without it, a link that will not leave U1 -
            // during link training, or on a marginal cable - spins here forever and the
            // thread never yields.
        	status = CyU3PUsbGetLinkPowerState(&powerState);
        	linkRecoveryAttempts = 0;
            while ((status == CY_U3P_SUCCESS) && (linkRecoveryAttempts < 8) &&
                ((powerState == CyU3PUsbLPM_U1) || (powerState == CyU3PUsbLPM_U2))) {
                CyU3PUsbSetLinkPowerState(CyU3PUsbLPM_U0);
                CyU3PThreadSleep(1);
                status = CyU3PUsbGetLinkPowerState(&powerState);
                linkRecoveryAttempts++;
            }
        }

        // Process the input0 flag (generated via GPIO interrupt)
        if (input0Flag) {
        	// Ensure we only output the debug once
        	if (!input0HandledFlag) {
        		input0HandledFlag = CyTrue;
        		CyU3PDebugPrint(4, "Main application loop: input0 pin set by the FPGA\r\n");
        	}
        }

        // Process the input1 flag (generated via GPIO interrupt)
		if (input1Flag) {
			// Ensure we only output the debug once
			if (!input1HandledFlag) {
				input1HandledFlag = CyTrue;
				CyU3PDebugPrint(4, "Main application loop: input1 pin set by the FPGA\r\n");
			}
		}

		// Process the input2 flag (generated via GPIO interrupt)
		if (input2Flag) {
			// Ensure we only output the debug once
			if (!input2HandledFlag) {
				input2HandledFlag = CyTrue;
				CyU3PDebugPrint(4, "Main application loop: input2 pin set by the FPGA\r\n");
			}
		}

		// Process the input3 flag (generated via GPIO interrupt)
		if (input3Flag) {
			// Ensure we only output the debug once
			if (!input3HandledFlag) {
				input3HandledFlag = CyTrue;
				CyU3PDebugPrint(4, "Main application loop: input3 pin set by the FPGA\r\n");
			}
		}

		// Status LEDs.
		//
		// Driven from here rather than from the callbacks that change the state they
		// report, so that one thread decides what the LEDs say and the register is
		// written only when the answer has actually changed. A failed write leaves
		// ledPatternShown alone, so the next pass tries again.
		if (fpgaRegistersPresent()) {
			if (updateAgentInProgress()) ledPattern = FPGA_LED_UPDATING;
			else if (input0Flag) ledPattern = FPGA_LED_BUFFER_ERROR;
			else if (dataCollectionFlag) ledPattern = FPGA_LED_CAPTURING;
			else ledPattern = FPGA_LED_READY;

			if (ledPattern != ledPatternShown) {
				if (fpgaRegistersSetLeds(ledPattern)) ledPatternShown = ledPattern;
			}
		} else {
			// Look again for a register bank that did not answer at start-up.
			//
			// The FPGA is reprogrammed over JTAG while the FX3 keeps running for the
			// whole of gateware development, and without this the board would have to
			// be power cycled as well before the firmware noticed. One attempt every
			// couple of seconds costs nothing and is silent until it succeeds.
			fpgaRecheckCount++;
			if (fpgaRecheckCount >= FPGA_RECHECK_LOOPS) {
				fpgaRecheckCount = 0;
				if (fpgaRegistersProbe(1)) ledPatternShown = 0;
			}
		}

		// Yield the CPU.
		//
		// Nothing in this loop is latency critical: the GPIF to USB data path is carried
		// entirely by the DMA hardware and never passes through this thread. Without a sleep
		// the loop spins at 100% CPU whenever the link is at U0, which is almost always, and
		// starves the debug console and the USB driver's own housekeeping threads.
		CyU3PThreadSleep(10);
    }
}

// Function to create the initial application thread
void CyFxApplicationDefine(void)
{
    void *ptr = NULL;
    uint32_t returnCode = CY_U3P_SUCCESS;

    // Allocate the memory for the threads
    ptr = CyU3PMemAlloc(CY_FX_GPIFTOUSB_THREAD_STACK);
    if (ptr == NULL) {
    	// Could not allocate the thread stack
    	// Application cannot start
    	while(1);
    }

    // Create the application's main thread
    returnCode = CyU3PThreadCreate(
		&glAppThread,						// Application thread structure
		"28:domDup",						// Thread ID and thread name
		domDupThreadInitialise,				// Application thread entry function
		0,									// No input parameter to thread
		ptr,								// Pointer to the allocated thread stack
		CY_FX_GPIFTOUSB_THREAD_STACK,		// Application thread stack size
		CY_FX_GPIFTOUSB_THREAD_PRIORITY,	// Application thread priority
		CY_FX_GPIFTOUSB_THREAD_PRIORITY,	// Application thread priority
		CYU3P_NO_TIME_SLICE,				// No time slice for the application thread
		CYU3P_AUTO_START					// Start the thread immediately
		);

    // Check the return code
    if (returnCode != 0) {
    	// Could not create initial thread
    	// Application cannot start
        while(1);
    }
}
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

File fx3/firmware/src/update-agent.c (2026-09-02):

/************************************************************************

    update-agent.c

    Rewriting the device's two flash memories, commanded from the host
    DomesdayDuplicator - LaserDisc RF sampler
    SPDX-FileCopyrightText: 2026 Simon Inns
    SPDX-License-Identifier: GPL-3.0-or-later

************************************************************************/

#include "cyu3system.h"
#include "cyu3os.h"
#include "cyu3error.h"
#include "cyu3i2c.h"
#include "cyu3utils.h"

#include "epcs-flash.h"
#include "fpga-registers.h"
#include "update-agent.h"
#include "vendor/sha-256.h"

// The I2C bit rate. 400 kHz is the M24M02's fast mode and is what the
// Cypress flash programmer uses over the same bus, so the timing is not
// new: it is the timing every EEPROM on every one of these kits has already
// been written at.
#define UPDATE_I2C_BIT_RATE         (400000u)

// How many times to poll the EEPROM for the end of an internal page write
// before giving up. The part specifies 5 ms; each poll is a full I2C
// address cycle, so two hundred is a long way past patient.
#define UPDATE_I2C_ACK_RETRIES      (200u)

// How many times to retry a transfer the slave did not acknowledge at all,
// inside one attempt. One retry, because a NAK on the address phase means
// the part is busy with the previous write and the SDK reissues the address
// with no delay between tries; recovering from anything slower than that is
// the outer attempt loop's job.
#define UPDATE_I2C_NAK_RETRIES      (1u)

// How many times one EEPROM access is attempted before the update gives up.
//
// A firmware image is a little over two thousand page writes and a few
// hundred readback reads, and every one of them has to succeed or the whole
// update is abandoned. That is an unreasonable thing to ask of a bus: the
// SDK documents CY_U3P_ERROR_TIMEOUT as retryable without any recovery at
// all, and a board whose I2C is marginal - long wiring, weak pull-ups, a
// rail sagging under a just-configured FPGA - fails one page somewhere in
// the middle, in a different place every run, and never completes.
//
// Retrying is safe because a page write is idempotent: the address is
// recomputed identically, a write never crosses a page boundary, and what
// finally decides whether the update commits is the readback digest, not
// the fact that a write returned success. Four attempts turns a bus that
// glitches occasionally into one that finishes, and leaves a bus that is
// genuinely broken failing as it did before, only four times slower.
#define UPDATE_I2C_ATTEMPTS         (4u)

// How long to leave the bus alone before attempting an access again. Enough
// for a slave that lost track of the transaction to time out and release
// SDA, and short enough that four attempts cost nothing on a board that
// never needs the second one.
#define UPDATE_I2C_SETTLE_US        (500u)

// The readback buffer. Sized to a whole number of EEPROM pages so a read
// never straddles the boundary the write span was chosen around, and kept
// small because it is static and this processor has 512 KiB of RAM in total.
#define UPDATE_READBACK_SIZE        (512u)

// Whether the I2C block came up. Everything here refuses with
// UPDATE_ERROR_HARDWARE when it did not, rather than calling into a block
// that was never initialised.
static CyBool_t glUpdateI2cReady = CyFalse;

static updateState_t glUpdateState;

// Set by UPDATE_FINISH, cleared by the application thread when it picks the
// work up. Volatile because it is written by one thread and read by another
// with nothing between them that would force a reload.
static volatile CyBool_t glUpdateVerifyPending = CyFalse;

// The first EEPROM page, held back until everything else is written and
// verified.
//
// It carries the 'CY' signature the boot ROM looks for, so an EEPROM whose
// first page has not been written is an EEPROM the boot ROM rejects — and a
// kit whose EEPROM the boot ROM rejects falls back to the USB bootloader.
// That is the whole of the interrupted-update safety story, and it is one
// buffer and one deferred write.
static uint8_t glUpdateFirstPage[UPDATE_EEPROM_PAGE_SIZE]
    __attribute__ ((aligned (32)));

// Readback staging. Handed to the I2C block, so it needs the same 32-byte
// alignment the register buffer does.
static uint8_t glUpdateReadback[UPDATE_READBACK_SIZE]
    __attribute__ ((aligned (32)));

// One page, for the zero-padded tail of an image that does not end on a
// page boundary. The padding is outside the payload the digest covers, so
// it is written to the medium and never read back into a comparison.
static uint8_t glUpdatePagePad[UPDATE_EEPROM_PAGE_SIZE]
    __attribute__ ((aligned (32)));

// SHA-256 over the chunk stream as it arrives (integrity link 5) and over
// the readback from the medium (link 6). Two contexts because the second
// starts while the first is still needed for the comparison.
static struct Sha_256 glUpdateStreamHash;
static uint8_t glUpdateStreamDigest[UPDATE_DIGEST_LENGTH];

static struct Sha_256 glUpdateMediumHash;
static uint8_t glUpdateMediumDigest[UPDATE_DIGEST_LENGTH];

// The boot block, built once the application image has been read back and
// proved, and written as the last act of a gateware update.
static uint8_t glUpdateBootBlock[UPDATE_BOOT_BLOCK_LENGTH];

// Build the preamble for an EEPROM access: slave address for the bank, then
// the sixteen-bit byte address within it.
static void updateEepromPreamble(CyU3PI2cPreamble_t *preamble, uint32_t address,
                                 CyBool_t isRead)
{
    const uint8_t slave = updateEepromSlaveAddress(address);
    const uint16_t offset = updateEepromSlaveOffset(address);

    preamble->buffer[0] = slave;
    preamble->buffer[1] = (uint8_t)(offset >> 8);
    preamble->buffer[2] = (uint8_t)(offset & 0xFFu);

    if (isRead) {
        // A read is a write of the address followed by a repeated start and
        // the same slave in read mode. ctrlMask bit 2 is what puts that
        // second start condition after the third preamble byte.
        preamble->buffer[3] = (uint8_t)(slave | 0x01u);
        preamble->length = 4;
        preamble->ctrlMask = 0x0004;
    } else {
        preamble->length = 3;
        preamble->ctrlMask = 0x0000;
    }
}

// Wait for the EEPROM to finish its internal write cycle.
//
// The part acknowledges its address again as soon as the cycle is over, so
// polling for an acknowledgement is both the specified way to do this and
// faster than the fixed 5 ms delay it replaces: a page usually completes in
// rather less.
static CyU3PReturnStatus_t updateEepromWaitReady(uint32_t address)
{
    CyU3PI2cPreamble_t preamble;

    preamble.buffer[0] = updateEepromSlaveAddress(address);
    preamble.length = 1;
    preamble.ctrlMask = 0x0000;

    return CyU3PI2cWaitForAck(&preamble, UPDATE_I2C_ACK_RETRIES);
}
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

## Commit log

2023-05-16 Sequence mismatch capture option
    add an option in capture menu for enabling the program to stop the capture when a sequence mismatch is detected
    (the program now didn't stop unless its specified using the new option)
    [configuration.h]
2023-05-16 Fix "Restore defaults" button
    Fix "Restore defaults" button so it also reset the "stop capture on sequence mismatch" when used
2023-11-27 Squashed commit of the following:
    commit 26032dc9a6c528fe9a96f419e9056aaa83d9626d
    Author: Adam Sampson <ats@offog.org>
    Date: Wed Jul 26 01:22:52 2023 +0100
    Avoid duplicate QVBoxLayout names.
    This is harmless, but Qt 6 warns about it.
    commit 7c03d6ca688d62603560613d1a122e73e86e12f7
    Author: Adam Sampson <ats@offog.org>
    Date: Sun Mar 19 15:19:53 2023 +0000
    Add settings to enable/disable per-side notes and mint marks.
    These are individually configurable because it's reasonable to want one
    but not the other (e.g. if you're using the notes field to record the
    player used).
    commit 3c7c076cf55fc30abe54066ebdf61e2d868f6f76
    Author: Adam Sampson <ats@offog.org>
    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
    [configuration.h, configurationdialog.h]
2026-08-28 Fix clang-tidy return-value checks
    [auto_capture_controller.cpp]
2026-08-29 Update all repo links after moving the repo to the Domesday86 github organisation
    [ADC.kicad_sch, Domesday Duplicator.kicad_sch, Power Supply.kicad_sch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]
2026-09-02 Prevent I2C failures from killing an update (this may mask bad boards...)
    [domesday-duplicator.c, update-agent.c, update-protocol-test.c]
2026-09-02 Fix for issue #179
    [board_bringup_wizard.h, test_board_bringup_wizard.cpp]
2026-09-02 Fix for issue #180
    [waveform_panel.h]
2026-09-02 Fix for issue #186
    [tb_dataGenerator.v]
2026-09-15 Include instructions for removing the EFM xtal from the LD-V4300D AUDB PCB

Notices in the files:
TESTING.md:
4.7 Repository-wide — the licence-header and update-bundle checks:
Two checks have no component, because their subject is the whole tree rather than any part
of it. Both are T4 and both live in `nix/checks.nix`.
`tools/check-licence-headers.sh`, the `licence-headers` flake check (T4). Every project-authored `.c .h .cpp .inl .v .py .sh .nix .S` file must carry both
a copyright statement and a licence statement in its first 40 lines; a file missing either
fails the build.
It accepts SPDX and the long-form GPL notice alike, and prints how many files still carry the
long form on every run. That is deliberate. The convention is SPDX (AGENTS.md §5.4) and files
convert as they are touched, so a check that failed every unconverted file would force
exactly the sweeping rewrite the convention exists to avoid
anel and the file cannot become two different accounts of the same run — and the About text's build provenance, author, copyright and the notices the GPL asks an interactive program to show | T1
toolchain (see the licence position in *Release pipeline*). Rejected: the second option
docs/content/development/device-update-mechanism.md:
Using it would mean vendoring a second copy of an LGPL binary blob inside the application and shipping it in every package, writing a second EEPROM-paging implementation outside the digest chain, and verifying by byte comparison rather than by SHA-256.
